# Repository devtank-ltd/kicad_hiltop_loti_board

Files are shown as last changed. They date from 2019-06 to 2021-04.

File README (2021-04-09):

Copyright Devtank Ltd 2021.

This documentation describes Open Hardware and is Licensed under CERN-OHL-W v2.

You may redistribute and modify this documentation under the terms of the CERN-OHL-W v2 (https://cern.ch/cern-ohl). This documentation is distributed WITHOUT ANY EXPRESS OR IMPLIED WARRANTY, INCLUDING OF MERCHANTABILITY, SATISFACTORY QUALITY AND FITNESS FOR A PARTICULAR PURPOSE. Please see the CERN-OHL-W v2 for applicable conditions

Source location: git@github.com:devtank-ltd/kicad_hiltop_loti_board.git 

As per CERN-OHL-W v2 section 4.1, should You produce hardware based on these sources, You must maintain the Source Location visible on the external case of the HILTOP or other product you make using this documentation.

This folder contains HILTOP LoTI Board hardware schematics and pcb layout files 

You will need Kicad to open hardware design files.

LoTI Boards and other test and measurement products can be purchased directly from Devtank Ltd.

Please contact:
Tim Telford
CTO - Devtank Ltd
+44 (0)1332 650944

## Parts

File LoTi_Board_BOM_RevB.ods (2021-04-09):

Title | LoTi Board
Revision | Rev B
Date | Mon 14 Sep 2020 16:12:00 BST
Generated
Company | Devtank Ltd
Comment 1
Comment 2
Comment 3
Comment 4
Total Parts | 442
Total Unique Parts | 79
Ref | Qty | Value | Footprint | Devtank | Description | Manufacturer | Manufacturer Part Number | Supplier | Supplier Part number
C9 C12 C1 C20 C21 C22 C23 C24 C25 C14 C15 C16 C26 C27 C28 C17 C18 C29 C38 C56 C82 C73 C74 C79 C80 C81 C54 | 27 | 100nF | Capacitor_SMD:C_0603_1608Metric | 105-002 | 100nF 50V X7R | Kemet | C0603C104M5RACTU | Farnell | 2581046
C8 C7 C13 | 3 | 100uF | Capacitor_SMD:CP_Elec_6.3x7.7 | 108-003 | 100uF 50V 0.34R FT Series | Panasonic | EEEFTH101XAP | Farnell | 1868426
C6 | 1 | 22nF | Resistor_SMD:R_0603_1608Metric | 105-024 | 22nF 16V X7R | AVX | 0603YC223KAT2A | Farnell | 2332669
C2 C3 C4 C5 | 4 | 15pF | Capacitor_SMD:C_0402_1005Metric | 106-013 | 15pF COG/NPO | AVX | 04025A150JAT2A | Farnell | 1327631
C10 C11 | 2 | 10uF | Capacitor_SMD:C_0805_2012Metric | 105-001 | 10uF 16V X5R 10% MLCC | AVX | 0805YD106KAT2A | Farnell | 1658880
C19 C53 | 2 | 100nF | Resistor_SMD:R_1210_3225Metric | 105-020 | 100nF 50V X7R | AVX | 12101C104KAT2A | Farnell | 1327731
C31 | 1 | 4.7uF | Capacitor_SMD:C_0603_1608Metric | 105-021 | 4.7uF 16V X5R | muRata | GRM188R61C475KAAJD | Farnell | 2611924
C32 C34 C39 C40 C41 C42 C43 C46 C44 C45 C47 C48 C50 C51 C30 C60 C61 C62 C66 C67 C68 C71 C72 | 23 | 100nF | Capacitor_SMD:C_0402_1005Metric | 105-019 | 100nF 50V X7R | TDK | C1005X7R1H104M050BB | Farnell | 2525048
C35 C49 | 2 | 1uF | Capacitor_SMD:C_0603_1608Metric | 105-014 | 1uF 16V X7R | Walsin | 0603B105K160CT | Farnell | 2496835
C33 C37 | 2 | 18pF | Capacitor_SMD:C_0402_1005Metric | 106-010 | 18pF COG/NPO | AVX | 04025A180JAT2A | Farnell | 1740572
C36 | 1 | 10nF | Capacitor_SMD:C_0402_1005Metric | 105-017 | 10nF 50V X7R | AVX | 04025C103KAT2A | Farnell | 2332514
C55 | 1 | 4.7uF | Capacitor_SMD:C_0805_2012Metric | 105-007 | 4.7uF 16V X7R | muRata | GCJ21BR71C475KA01L | Farnell | 2781412
C52 | 1 | DNF | Capacitor_SMD:C_0603_1608Metric
C57 C58 C59 C63 C64 C65 C69 C70 | 8 | DNP | Capacitor_SMD:C_0805_2012Metric
C77 C78 | 2 | 4.3pF | Capacitor_SMD:C_0603_1608Metric | 106-014 | 4.3pF COG/NPO | Kemet | CBR06C439B5GAC | Farnell | 2809587
C75 C76 | 2 | 18pF | Capacitor_SMD:C_0603_1608Metric | 106-003 | 18pF COG/NPO | AVX | 06035A180JAT2A | Farnell | 1612182
D1 D2 D3 D6 D7 D10 D13 | 7 | GRN | LED_SMD:LED_0603_1608Metric | 110-002 | Green LED | Rohm Semiconductor | SML-D12P8WT86C | Farnell | 2687486
D32 | 1 | MBR230LSFT1G | Diode_SMD:D_SOD-123 | 133-006 | Schottky Rectifier, 30 V, 2 A, Single, SOD-123FL | ON Semi | MBR230LSFT1G | Farnell | 2317422
D33 | 1 | BAT42W | Diode_SMD:D_SOD-123 |  | DNF
D4 D5 D8 D9 D11 | 5 | BAT54T1G | Diode_SMD:D_SOD-123 | 133-007 | BAT54T1G Small Signal Schottky Diode, Single, 30V, 200mA | ON Semi | BAT54T1G | Farnell | 1651157
D12 | 1 | RED | LED_SMD:LED_0402_1005Metric | 110-005 | LED RED CLEAR 0402 SMD | Rohm Semiconductor | SML-P12VTT86R | Digikey | 846-1168-6-ND
D18 D16 D14 D20 D22 D24 D19 D17 D15 D21 D23 D25 D28 D27 D26 D29 D30 D31 | 18 | BAV99 | Package_TO_SOT_SMD:SOT-23 | 134-001 | BAV99 - Small Signal Diode, Dual Series, 75 V, 300 mA, 1.25 V, 4 ns, 4.5 | Diodes Inc | BAV99 | Farnell | 1902422
F1 | 1 | Polyfuse | Resistor_SMD:R_1206_3216Metric | 190-003 | PPTC Resettable Fuse, SMD, POLYFUSE 1206L | Littlefuse | 1206L075THYR | Farnell | 1822204
J3 | 1 | Conn_03x32_DIN41612 | Devtank_PCB_Lib:Socket_DIN41612-CaseC1-full-Male-96Pin-3rows_correct | 717-002 | 406AF-96-MSR-AAE4 (Cards) | Valcon | 406AF-96-MSR-AAE4 | Toby | 406AF-96-MSR-AAE4
J4 | 1 | RJ45-TRANS_VALCON | Devtank_PCB_Lib:RJ45_TRANSFO_VALCON | 704-001 | RJ45 Ethernet with Magnetics + LEDs 10/100 | Valcon | VSIMJL-88-CC-GY | Toby | VSIMJL-88-CC-GY
J5 | 1 | USB_A | Devtank_PCB_Lib:USB_A_Vertical_Lumberg_2410_01 | 703-003 | USB Type A – PCB vertical | Lumberg | 2410 01 | Toby | 2410-01
J1 | 1 | Conn_02x10_Odd_Even | DNF |  | DNF |  |  | RS
J2 | 1 | DB44_MALE_MountingHoles | Connector_Dsub:DSUB-44-HD_Female_Horizontal_P2.29x1.98mm_EdgePinOffset8.35mm_Housed_MountingHolesOffset10.89mm | 707-003 | L17HTHBS4F1C - D Sub Connector, HD44, 44 Contacts, Receptacle, Through Hole, DB, HTH Series, Steel Body | Amphenol | L17HTHBS4F1C | Farnell | 2401273
J6 | 1 | Conn_02x08_Odd_Even | DNF |  | DNF |  | 281739-8 | RS | 532-080
JP1 | 1 | Jumper_NC_Dual | Connector_PinHeader_2.54mm:PinHeader_1x03_P2.54mm_Vertical | 710-015 | 3 Way Header (shroudless) | Valcon | THS-03-R | Toby | THS-03-R
K1 K2 K3 K4 K5 | 5 | HRS1KH-S | Devtank_PCB_Lib:Relay_SPDT_HRS1KH-S | 141-002 | Signal Relay 5VDC SPDT 24V 3A HRS1K Series | Multicomp | HRS1KH-S DC5V | Farnell | 9480293
L1 L2 L3 L4 L5 L6 L7 L8 L9 L10 L11 | 11 | 2A/0.05DCR | Inductor_SMD:L_0805_2012Metric | 113-002 | Ferrite 220 ohm, 2 A, WE-CBF Series, 0.05 ohm, ± 25% | Wurth Elektronik | 742792022 | Farnell | 1635733
Q2 Q3 Q4 Q5 Q6 Q7 Q8 Q9 Q10 Q11 Q12 Q13 Q14 | 13 | ZXMN6A07F | Package_TO_SOT_SMD:SOT-23 | 170-002 | ZXMN6A07F N Channel 1A, 60V, 0.4Ohm | Diodes Inc | ZXMN6A07FTA | Farnell | 9525769
R4 R5 R6 R23 R20 R24 R21 R22 R75 R81 R82 R124 | 12 | 330R | Resistor_SMD:R_0603_1608Metric | 101-024 | 330R 1% 0603 | Vishay | CRCW0603330RFKEA | Farnell | 1469803
R7 | 1 | 10R | Resistor_SMD:R_0402_1005Metric | 101-511 | 10R 1% 0402 | Vishay | CRCW040210R0FKED | Farnell | 1652742
R16 R15 | 2 | 4K7 | Resistor_SMD:R_0603_1608Metric | 101-009 | 4K7 1% 50V 0603 | Vishay | CRCW06034K70FKEA | Farnell | 121-9062
R17 R1 R2 R143 R147 R25 R26 R27 R29 R28 R64 R77 R9 R8 | 14 | DNF | Resistor_SMD:R_0603_1608Metric
R14 R18 R36 R38 R40 R42 R52 R53 R58 R59 R62 R63 R120 | 13 | 10K | Resistor_SMD:R_0603_1608Metric | 101-010 | 10K 1% 0603 | Vishay | CRCW060310K0FKEA | Farnell | 1469748
R10 R11 | 4 | 0R | Resistor_SMD:R_1206_3216Metric | 101-007 | 0R 1% 1206 | Vishay | CRCW12060000Z0EA | Farnell | 1469963
R3 R30 R31 R32 R33 R34 R35 R44 R45 R46 R47 | 11 | 100R | Resistor_SMD:R_0603_1608Metric | 101-018 | 100R 1% 50V 100mW CR Series | Bourns Inc | CR0603-FX-1000ELF | Farnell | 2008332
R13 | 1 | DNF | Resistor_SMD:R_0603_1608Metric |  | DNF | Vishay | CRCW06032K70FKEA | Farnell | 1469768
R145 | 1 | DNF | Resistor_SMD:R_0603_1608Metric |  | DNF
R149 R83 R84 R76 R122 R123 R118 R119 R121 R80 R79 | 11 | 0R | Resistor_SMD:R_0603_1608Metric | 101-005 | 0R 1% 0603 | Vishay | CRCW06030000Z0EA | Farnell | 1469739
R78 | 1 | 24K | Resistor_SMD:R_0603_1608Metric | 101-055 | 24K 1% 0603 | Multicomp Pro | MCWR06X2402FTL | Farnell | 2447308
R152 | 1 | 47K | Resistor_SMD:R_0603_1608Metric | 101-016 | 47K 1% 0603 | Bourns Inc | CR0603-FX-4702ELF | Farnell | 2333548
R150 R151 | 2 | 0R | Resistor_SMD:R_1210_3225Metric | 101-008 | 0R 1% 1210 | Vishay | CRCW12100000Z0EA | Farnell | 2309109
R19 R43 | 2 | 16K | Resistor_SMD:R_0603_1608Metric | 101-052 | 16K 1% 0603 | Vishay | CRCW060316K0FKEA | Farnell | 2138433
R37 R39 R41 | 3 | 3K3 | Resistor_SMD:R_0603_1608Metric | 101-013 | 3K3 1% 0603 | Vishay | CRCW06033K30FKEA | Farnell | 1469793
R50 R51 R56 R57 R61 | 5 | 470R | Resistor_SMD:R_0603_1608Metric | 101-001 | 470R 1% 50V | Vishay | CRCW0603470RFKEA | Farnell | 1469815
R48 R49 R54 R55 R60 | 5 | 2K2 | Resistor_SMD:R_0603_1608Metric | 101-011 | 2.2K 1% 0603 | Vishay | CRCW06032K20FKEA | Farnell | 1469765
R69 | 1 | 12K | Resistor_SMD:R_0402_1005Metric | 101-508 | 12K 1% 0402 | Vishay | CRCW040212K0FKED | Farnell | 2140866
R72 R73 R71 R74 | 4 | 49.9R | Resistor_SMD:R_0402_1005Metric | 101-514 | 49.9R 1% 0402 | Multicomp | CMR04X49R9FTL | Farnell | 2073090
R70 | 1 | 12.4K | Resistor_SMD:R_0402_1005Metric | 101-513 | 12.4K 1% 0402 | Panasonic | ERJ2RKF1242X | Farnell | 2059158
R68 R67 | 2 | 10K | Resistor_SMD:R_0402_1005Metric | 101-501 | 10K 1% 0402 | Vishay | CRCW040210K0FKED | Farnell | 1469669
R65 | 1 | 1M | Resistor_SMD:R_0402_1005Metric | 101-512 | 1M 1% 0402 | Vishay | CRCW04021M00JNED | Farnell | 2616728
R66 | 1 | 1K | Resistor_SMD:R_0402_1005Metric | 101-507 | 1K 1% 0402 | Vishay | CRCW04021K00FKED | Farnell | 1469662
R88 R89 R90 R100 R101 R102 R111 R112 R125 R126 R127 R128 R129 R130 R131 R132 R133 R134 R135 R136 R137 R138 R139 R140 R141 R142 | 26 | 1K | Resistor_SMD:R_0603_1608Metric | 101-012 | 1K 1% 0603 | Vishay | CRCW06031K00FKEA | Farnell | 1469740
R94 R95 R96 R106 R107 R108 R115 R116 | 8 | 100K | Resistor_SMD:R_0603_1608Metric | 101-015 | 100K 1% 0603 | Vishay | CRCW0402100KFKED | Farnell | 1469671
R85 R86 R87 R97 R98 R99 R109 R110 | 8 | 0R | Resistor_SMD:R_0805_2012Metric | 101-006 | 0R 1% 0805 | Vishay | CRCW08050000Z0EA | Farnell | 1469846
R91 R92 R93 R103 R104 R105 R113 R114 | 8 | DNP | Resistor_SMD:R_0805_2012Metric
SW1 | 1 | SW_Push | Button_Switch_SMD:SW_SPST_B3U-1000P | 780-001 | Switch SMT Micro SPST-NO | Omron | B3U-1000P | Mouser | 653-B3U-1000P
TP6 TP7 TP5 TP4 TP3 TP8 TP9 TP10 TP11 TP55 TP56 TP57 TP58 TP59 TP60 TP61 TP62 TP63 TP64 TP12 TP13 TP14 TP15 TP16 TP17 TP18 TP19 TP20 TP21 TP22 TP23 TP24 TP25 TP26 TP27 TP28 TP29 TP30 TP37 TP38 TP39 TP40 TP41 TP42 TP43 TP44 TP45 TP46 TP47 TP48 TP49 TP50 TP51 TP52 TP53 TP54 TP65 TP66 TP67 TP68 TP69 TP70 TP71 TP72 TP73 TP74 TP75 TP76 TP77 TP78 TP79 TP80 TP100 TP87 TP88 TP89 TP90 TP91 TP92 TP93 TP94 TP95 TP96 TP97 TP98 TP99 TP81 TP82 TP83 TP84 TP85 TP31 TP32 TP33 TP34 TP35 TP36 TP2 TP86 TP1 TP101 TP102 TP103 TP104 TP105 TP114 TP115 TP116 TP108 TP106 TP126 | 111 | Test_Point | TestPoint:TestPoint_THTPad_D1.0mm_Drill0.5mm
U1 | 1 | INA250A4 | Package_SO:TSSOP-16_4.4x5mm_P0.65mm | 119-002 | INA250 Current Shunt Monitor 2V/A (A4) | Texas Instruments | INA250A4PWR | Digikey
U3 | 1 | AT25DN512CSSHF-B | Package_SO:SOIC-8_3.9x4.9mm_P1.27mm | 129-002 | 512K, 2.3V, 104MHz Serial Flash | Adesto | AT25DN512C-SSHF-B (https://www.mouser.co.uk/ProductDetail/Adesto-Technologies/AT25DN512C-SSHF-B) | Mouser | 988-AT25DN512CSSHF-B
U2 | 1 | LD1117S33TR_SOT223 | Package_TO_SOT_SMD:SOT-223-3_TabPin2 | 150-004 | LM1117IMP-3.3 Fixed LDO Regulator 3.3V | Texas Instruments | LM1117IMP-3.3/NOPB | Farnell | 1469051
U4 U5 U6 U7 U8 | 5 | AD8646ARZ | Package_SO:SOIC-8_3.9x4.9mm_P1.27mm | 120-004 | Operational Amplifier, Rail-Rail, 1 Amplifier, 10 MHz, 20 V/µs, ± 2.25V to ± 18V, 4.5V to 36V, SOIC | Analog Devices | AD8646ARZ | Farnell | 1440771
U10 | 1 | LAN9513 | Package_DFN_QFN:QFN-64-1EP_9x9mm_P0.5mm_EP7.3x7.3mm_ThermalVias | 123-011 | LAN9513 - Ethernet Bridge, USB to Ethernet USB 2.0, 10/100 Base-T/TX PHY USB Interface 64-QFN (9x9) | Microchip | LAN9513-JZX | Digikey | LAN9513-JZX-ND
U11 | 1 | MIC2026-1YM | Package_SO:SOIC-8_3.9x4.9mm_P1.27mm | 153-003 | MIC2026-1YM USB Power distribution Switch Current Limit, high side switch – 2 outputs | Microchip | MIC2026-1YM | Farnell | 2509898
U9 | 1 | 93LCxxA | Package_SO:SOIC-8_3.9x4.9mm_P1.27mm | 129-004 | EEPROM, kbit, 64 x 16bit 3MHz | Microchip | 93LC46B-I/SN | Farnell | 9758232
U12 | 1 | SP3003-02XJ | Devtank_PCB_Lib:SC70-5 | 153-004 | SP3003-02JTG-ESD Protection Device | Littlefuse | SP3003-02JTG | Farnell | 1827640
U13 | 1 | CP2102N-A01-GQFN24 | Package_DFN_QFN:QFN-24-1EP_4x4mm_P0.5mm_EP2.6x2.6mm_ThermalVias | 118-007 | CP2102N USB to UART adapter IC | Silicon Labs | CP2102N-A01-GQFN24 | Farnell | 2577278
U14 U15 U16 U17 U18 U19 U20 U21 | 8 | BTS4140N | Package_TO_SOT_SMD:SOT-223 | 146-001 | BTS4140NHUMA1 Smart Power Switch, SIPMOS Technology, High Side, 1 Output, 0.7A, |  | BTS4140NHUMA1 | Farnell | 2215503
U22 | 1 | STM32F072RBTx | Package_QFP:LQFP-64_10x10mm_P0.5mm | 126-001 | STM32F072RBT6, 32bit ARM Cortex M0 Microcontroller, 48MHz, 64 kB, 128 kB Flash | ST Microelectronics | STM32F072RBT6 | RS | 907-4757
U23 | 1 | M74VHC1GT14DFT2G | Package_TO_SOT_SMD:SOT-353_SC-70-5 | 123-016 | M74VHC1GT14DFT2G Schmitt trigger inverter | On Semi | M74VHC1GT14DFT2G | Farnell | 2464477
Y1 | 1 | 25MHz Crystal | Crystal:Crystal_SMD_SeikoEpson_FA238V-4Pin_3.2x2.5mm | 181-001 | 25MHz Crystal 30ppm | Abracon | ABM8G-25.000MHZ-18-D2Y-T | Farnell | 2101339
Y3 | 1 | ABS25-32.768KHZ-6-T | Crystal:Crystal_SMD_7050-4Pin_7.0x5.0mm | 181-008 | Crystal, 32.768 kHz, SMD, 8mm x 3.8mm | Abracon | ABS25-32.768KHZ-6-T | Farnell | 2101354
Y2 | 1 | 8MHZ | Crystal:Crystal_SMD_Abracon_ABM3C-4Pin_5.0x3.2mm | 181-009 | ABM3B-8.000MHZ-B2-T - Crystal, 8 MHz, SMD, 5mm x 3.2mm, 50 ppm, 18 pF, 20 ppm | Abracon | ABM3B-8.000MHZ-B2-T | Farnell | 2467818
BOM made with KICAD_BOM_WIZARD (https://github.com/HashDefineElectronics/KiCad_BOM_Wizard.git)
Generated Tue 23 Apr 2019 13:30:32 BST

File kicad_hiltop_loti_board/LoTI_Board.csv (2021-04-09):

Title | LoTI Board
Revision | Rev A
Date | 2019-07-03
Generated | Mon 14 Sep 2020 16:12:00 BST
Company | Devtank Ltd
Comment 1
Comment 2
Comment 3
Comment 4
Total Parts | 442
Total Unique Parts | 79
Ref | Qty | Value | Footprint | Devtank
C9 C12 C1 C20 C21 C22 C23 C24 C25 C14 C15 C16 C26 C27 C28 C17 C18 C29 C56 C54 C82 C73 C74 C79 C80 C81 C38 | 27 | 100nF | Capacitor_SMD:C_0603_1608Metric | 105-002
C8 C7 C13 | 3 | 100uF | Capacitor_SMD:CP_Elec_6.3x7.7 | 108-003
C6 | 1 | 22nF | Resistor_SMD:R_0603_1608Metric | 105-024
C2 C3 C4 C5 | 4 | 15pF | Capacitor_SMD:C_0402_1005Metric | 106-013
C10 C11 | 2 | 10uF | Capacitor_SMD:C_0805_2012Metric | 105-001
C19 C53 | 2 | 100nF | Resistor_SMD:R_1210_3225Metric | 105-020
C55 | 1 | 4.7uF | Capacitor_SMD:C_0805_2012Metric | 105-007
C52 | 1 | DNF | Capacitor_SMD:C_0603_1608Metric
C60 C61 C62 C66 C67 C68 C71 C72 C32 C34 C39 C40 C41 C42 C43 C46 C44 C45 C47 C48 C50 C51 C30 | 23 | 100nF | Capacitor_SMD:C_0402_1005Metric | 105-019
C57 C58 C59 C63 C64 C65 C69 C70 | 8 | DNP | Capacitor_SMD:C_0805_2012Metric
C77 C78 | 2 | 4.3pF | Capacitor_SMD:C_0603_1608Metric | 106-014
C75 C76 | 2 | 18pF | Capacitor_SMD:C_0603_1608Metric | 106-003
C31 | 1 | 4.7uF | Capacitor_SMD:C_0603_1608Metric | 105-021
C35 C49 | 2 | 1uF | Capacitor_SMD:C_0603_1608Metric | 105-014
C33 C37 | 2 | 18pF | Capacitor_SMD:C_0402_1005Metric | 106-010
C36 | 1 | 10nF | Capacitor_SMD:C_0402_1005Metric | 105-017
D1 D2 D3 D6 D7 D10 D13 | 7 | GRN | LED_SMD:LED_0603_1608Metric | 110-002
D32 | 1 | MBR230LSFT1G | Diode_SMD:D_SOD-123 | 133-006
D33 | 1 | DNF | Diode_SMD:D_SOD-123 | 133-005
D4 D5 D8 D9 D11 | 5 | BAT54T1G | Diode_SMD:D_SOD-123 | 133-007
D18 D16 D14 D20 D22 D24 D19 D17 D15 D21 D23 D25 D28 D27 D26 D29 D30 D31 | 18 | BAV99 | Package_TO_SOT_SMD:SOT-23 | 134-001
D12 | 1 | RED | LED_SMD:LED_0402_1005Metric | 110-004
F1 | 1 | Polyfuse | Resistor_SMD:R_1206_3216Metric | 190-003
J3 | 1 | Conn_03x32_DIN41612 | Devtank_PCB_Lib:Socket_DIN41612-CaseC1-full-Male-96Pin-3rows_correct | 717-002
J4 | 1 | RJ45-TRANS_VALCON | Devtank_PCB_Lib:RJ45_TRANSFO_VALCON | 704-001
J5 | 1 | USB_A | Devtank_PCB_Lib:USB_A_Vertical_Lumberg_2410_01 | 703-003
J1 | 1 | Conn_02x10_Odd_Even | Connector_IDC:IDC-Header_2x10_P2.54mm_Vertical | 710-018
J2 | 1 | DB44_MALE_MountingHoles | Connector_Dsub:DSUB-44-HD_Female_Horizontal_P2.29x1.98mm_EdgePinOffset8.35mm_Housed_MountingHolesOffset10.89mm | 707-003
J6 | 1 | Conn_02x08_Odd_Even | Connector_IDC:IDC-Header_2x08_P2.54mm_Vertical | 710-017
JP1 | 1 | Jumper_NC_Dual | Connector_PinHeader_2.54mm:PinHeader_1x03_P2.54mm_Vertical | 710-015
K1 K2 K3 K4 K5 | 5 | HRS1KH-S | Devtank_PCB_Lib:Relay_SPDT_HRS1KH-S | 141-002
L3 L4 L5 L6 L7 L8 L9 L10 L11 L1 L2 | 11 | 2A/0.05DCR | Inductor_SMD:L_0805_2012Metric | 113-002
Q2 Q3 Q4 Q5 Q6 Q7 Q8 Q9 Q10 Q11 Q12 Q13 Q14 | 13 | ZXMN6A07F | Package_TO_SOT_SMD:SOT-23 | 170-002
R4 R5 R6 R23 R20 R24 R21 R22 R81 R82 R124 R75 | 12 | 330R | Resistor_SMD:R_0603_1608Metric | 101-024
R7 | 1 | 10R | Resistor_SMD:R_0402_1005Metric | 101-511
R16 R15 | 2 | 4K7 | Resistor_SMD:R_0603_1608Metric | 101-009
R17 R1 R2 R143 R147 R12 R148 R25 R26 R27 R29 R28 R77 R117 R64 | 15 | DNF | Resistor_SMD:R_0603_1608Metric
R14 R18 R36 R38 R40 R42 R52 R53 R58 R59 R62 R120 R63 | 13 | 10K | Resistor_SMD:R_0603_1608Metric | 101-010
R9 R8 | 2 | DNF | Resistor_SMD:R_1206_3216Metric | 101-007
R10 R11 | 2 | 0R | Resistor_SMD:R_1206_3216Metric | 101-007
R3 R30 R31 R32 R33 R34 R35 R44 R45 R46 R47 | 11 | 100R | Resistor_SMD:R_0603_1608Metric | 101-018
R13 | 1 | DNF | Resistor_SMD:R_0603_1608Metric | 101-051
R145 | 1 | DNF | Resistor_SMD:R_0603_1608Metric | 101-053
R144 R146 | 2 | DNF | Resistor_SMD:R_0603_1608Metric | 101-005
R149 R83 R84 R76 R80 R79 R122 R123 R118 R119 R121 | 11 | 0R | Resistor_SMD:R_0603_1608Metric | 101-005
R150 R151 | 2 | 0R | Resistor_SMD:R_1210_3225Metric | 101-008
R19 R43 | 2 | 16K | Resistor_SMD:R_0603_1608Metric | 101-052
R37 R39 R41 | 3 | 3K3 | Resistor_SMD:R_0603_1608Metric | 101-013
R50 R51 R56 R57 R61 | 5 | 470R | Resistor_SMD:R_0603_1608Metric | 101-001
R48 R49 R54 R55 R60 | 5 | 2K2 | Resistor_SMD:R_0603_1608Metric | 101-011
R78 | 1 | 24K | Resistor_SMD:R_0603_1608Metric | 101-005
R152 | 1 | 47K | Resistor_SMD:R_0603_1608Metric
R88 R89 R90 R100 R101 R102 R111 R112 R125 R126 R127 R128 R129 R130 R131 R132 R133 R134 R135 R136 R137 R138 R139 R140 R141 R142 | 26 | 1K | Resistor_SMD:R_0603_1608Metric | 101-012
R94 R95 R96 R106 R107 R108 R115 R116 | 8 | 100K | Resistor_SMD:R_0603_1608Metric | 101-015
R85 R86 R87 R97 R98 R99 R109 R110 | 8 | 0R | Resistor_SMD:R_0805_2012Metric | 101-006
R91 R92 R93 R103 R104 R105 R113 R114 | 8 | DNP | Resistor_SMD:R_0805_2012Metric
R69 | 1 | 12K | Resistor_SMD:R_0402_1005Metric | 101-508
R72 R73 R71 R74 | 4 | 49.9R | Resistor_SMD:R_0402_1005Metric | 101-514
R70 | 1 | 12.4K | Resistor_SMD:R_0402_1005Metric | 101-513
R68 R67 | 2 | 10K | Resistor_SMD:R_0402_1005Metric | 101-501
R65 | 1 | 1M | Resistor_SMD:R_0402_1005Metric | 101-512
R66 | 1 | 1K | Resistor_SMD:R_0402_1005Metric | 101-507
SW1 | 1 | SW_Push | Button_Switch_SMD:SW_SPST_B3U-1000P | 780-001
TP6 TP7 TP5 TP4 TP3 TP8 TP9 TP10 TP11 TP55 TP56 TP57 TP58 TP59 TP60 TP61 TP62 TP63 TP64 TP12 TP13 TP14 TP15 TP16 TP17 TP18 TP19 TP20 TP21 TP22 TP23 TP24 TP25 TP26 TP27 TP28 TP29 TP30 TP37 TP38 TP39 TP40 TP41 TP42 TP43 TP44 TP45 TP46 TP47 TP48 TP49 TP50 TP51 TP52 TP53 TP54 TP65 TP66 TP67 TP68 TP69 TP70 TP71 TP72 TP73 TP74 TP75 TP76 TP77 TP78 TP79 TP80 TP100 TP87 TP88 TP89 TP90 TP91 TP92 TP93 TP94 TP95 TP96 TP97 TP98 TP99 TP81 TP82 TP83 TP84 TP85 TP31 TP32 TP33 TP34 TP35 TP36 TP2 TP86 TP1 TP101 TP102 TP103 TP104 TP105 TP126 TP114 TP115 TP116 TP108 TP106 | 111 | Test_Point | TestPoint:TestPoint_THTPad_D1.0mm_Drill0.5mm
U1 | 1 | INA250A4 | Package_SO:TSSOP-16_4.4x5mm_P0.65mm | 119-002
U3 | 1 | AT25DN512CSSHF-B | Package_SO:SOIC-8_3.9x4.9mm_P1.27mm | 129-002
U2 | 1 | LD1117S33TR_SOT223 | Package_TO_SOT_SMD:SOT-223-3_TabPin2 | 150-004
U4 U5 U6 U7 U8 | 5 | AD8646 | Package_SO:SOIC-8_3.9x4.9mm_P1.27mm | 120-004
U13 | 1 | CP2102N-A01-GQFN24 | Package_DFN_QFN:QFN-24-1EP_4x4mm_P0.5mm_EP2.6x2.6mm_ThermalVias | 118-007
U23 | 1 | M74VHC1GT14DFT2G | Package_TO_SOT_SMD:SOT-353_SC-70-5
U14 U15 U16 U17 U18 U19 U20 U21 | 8 | BTS4140N | Package_TO_SOT_SMD:SOT-223 | 146-001
U22 | 1 | STM32F072RBTx | Package_QFP:LQFP-64_10x10mm_P0.5mm | 126-001
U10 | 1 | LAN9513 | Package_DFN_QFN:QFN-64-1EP_9x9mm_P0.5mm_EP7.3x7.3mm_ThermalVias | 123-011
U11 | 1 | MIC2026-1YM | Package_SO:SOIC-8_3.9x4.9mm_P1.27mm | 153-003
U9 | 1 | 93LCxxA | Package_SO:SOIC-8_3.9x4.9mm_P1.27mm | 129-004
U12 | 1 | SP3003-02XJ | Devtank_PCB_Lib:SC70-5 | 153-004
Y3 | 1 | ABS25-32.768KHZ-6-T | Crystal:Crystal_SMD_7050-4Pin_7.0x5.0mm | 181-008
Y2 | 1 | 8MHZ | Crystal:Crystal_SMD_Abracon_ABM3C-4Pin_5.0x3.2mm | 181-009
Y1 | 1 | 25MHz Crystal | Crystal:Crystal_SMD_SeikoEpson_FA238V-4Pin_3.2x2.5mm | 181-001
BOM made with KICAD_BOM_WIZARD (https://github.com/HashDefineElectronics/KiCad_BOM_Wizard.git)
Generated Mon 14 Sep 2020 16:12:00 BST

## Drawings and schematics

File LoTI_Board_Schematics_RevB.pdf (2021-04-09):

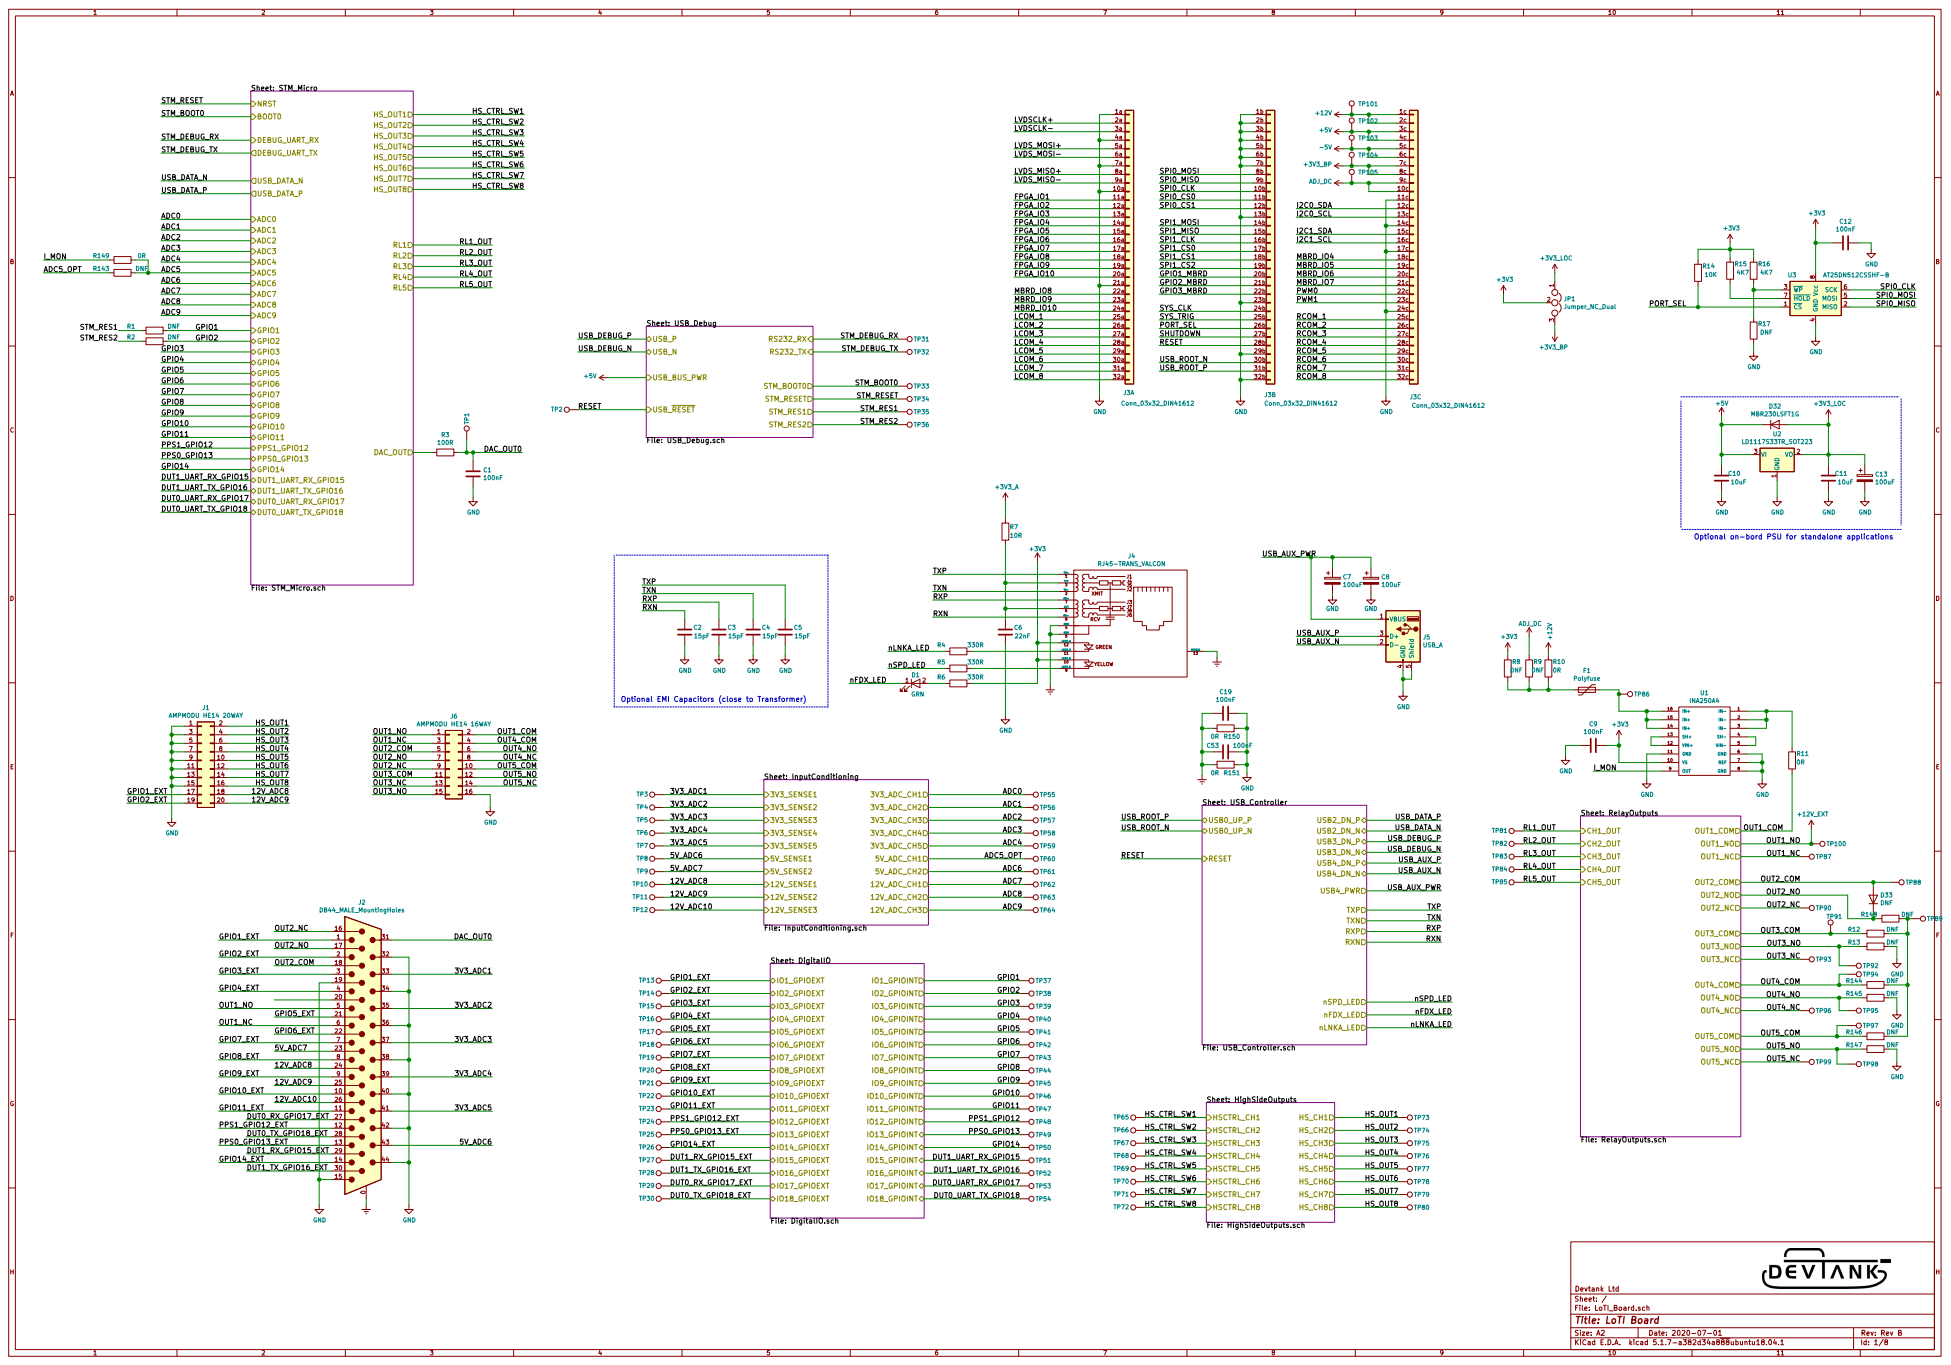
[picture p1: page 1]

Optional on-bord PSU for standalone applications

Optional EMI Capacitors (close to Transformer)

File: LoTI_Board.sch Sheet: / Devtank Ltd

Id: 1/8 Title: LoTI Board

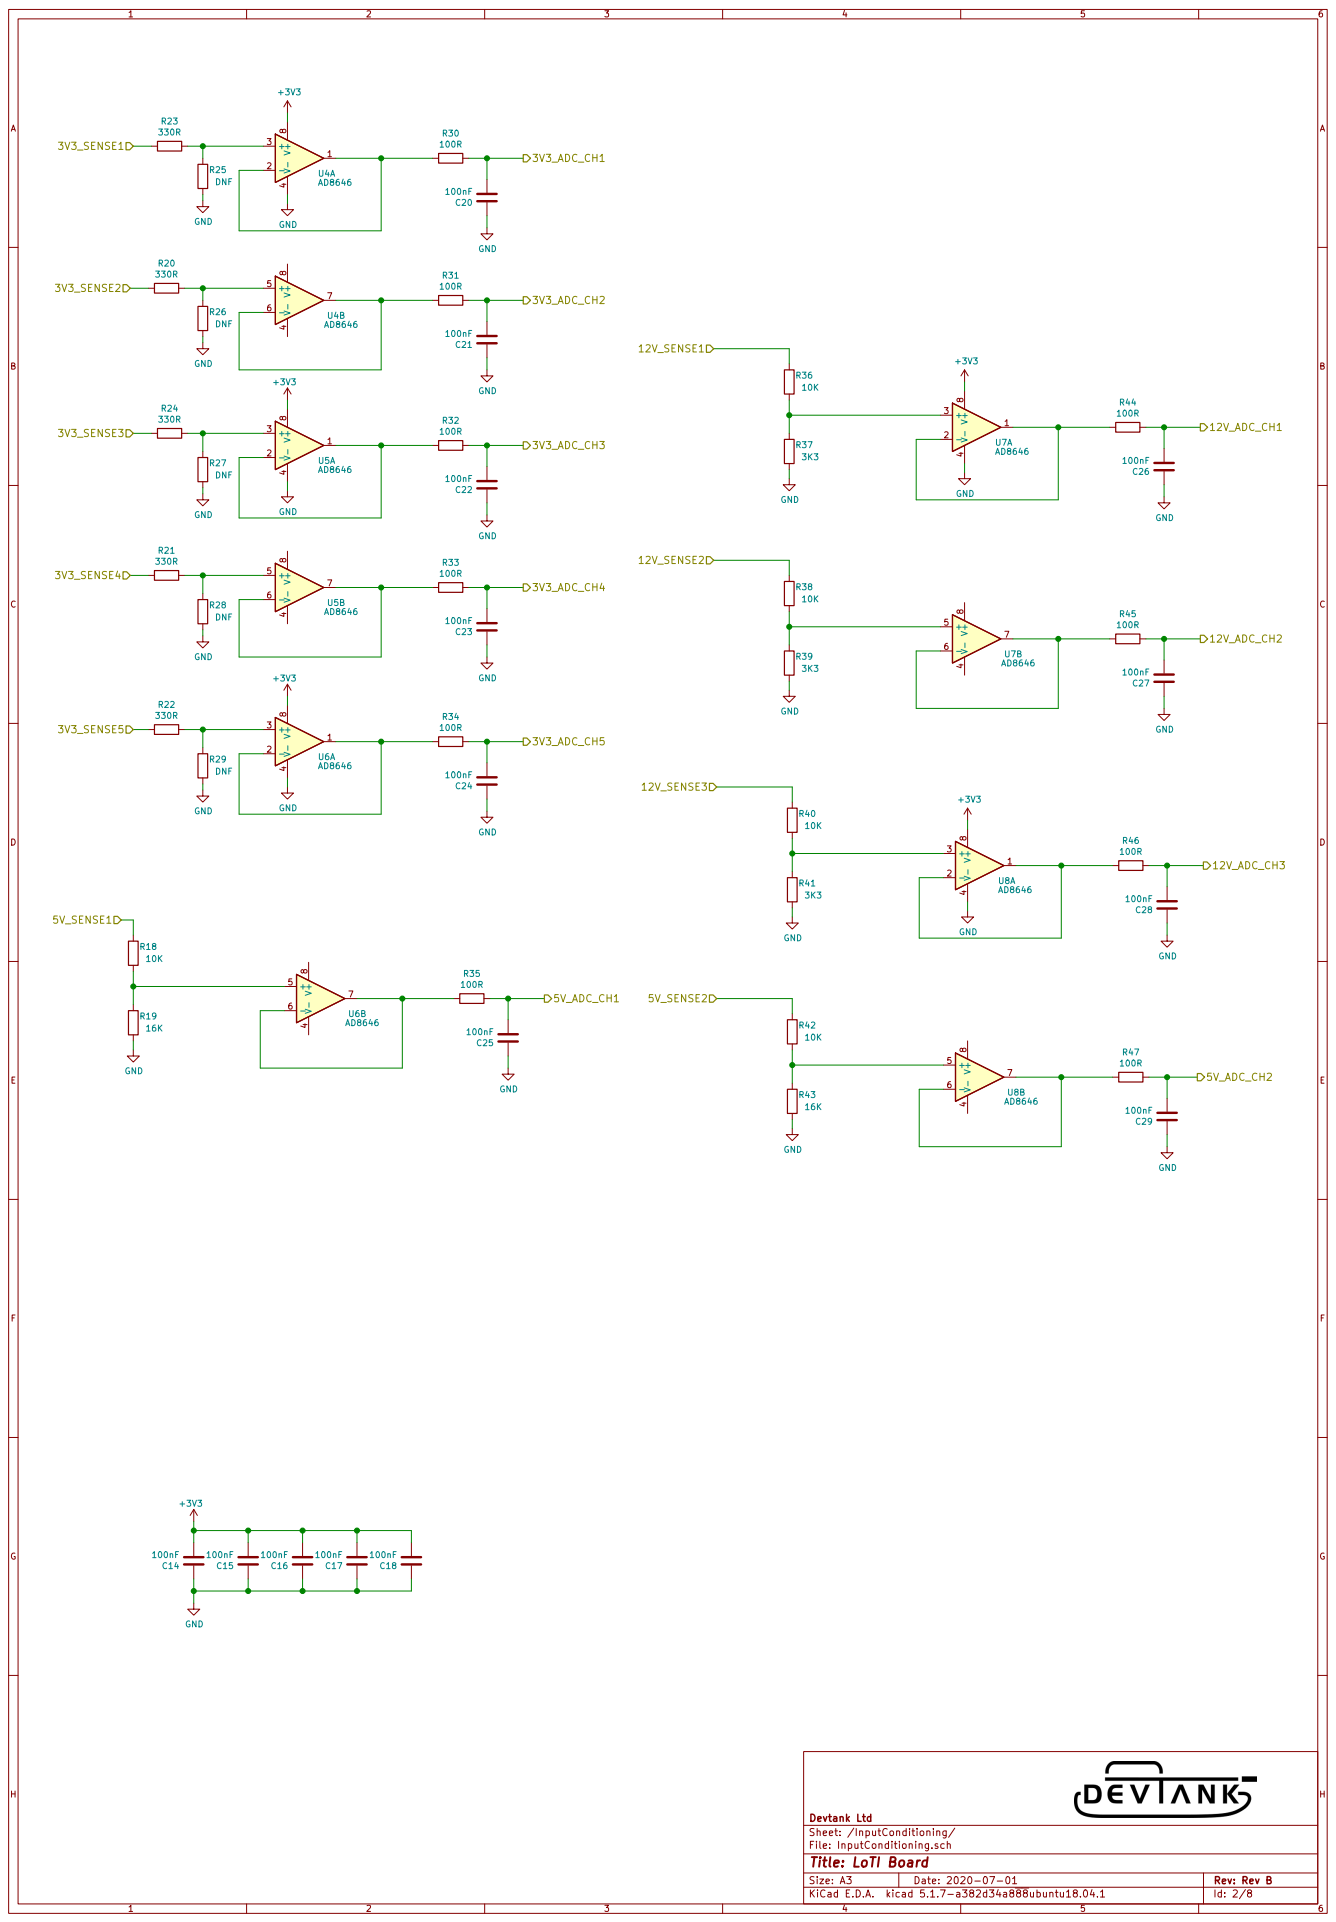
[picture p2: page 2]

Sheet: /InputConditioning/ Devtank Ltd

File: InputConditioning.sch
Id: 2/8 Title: LoTI Board

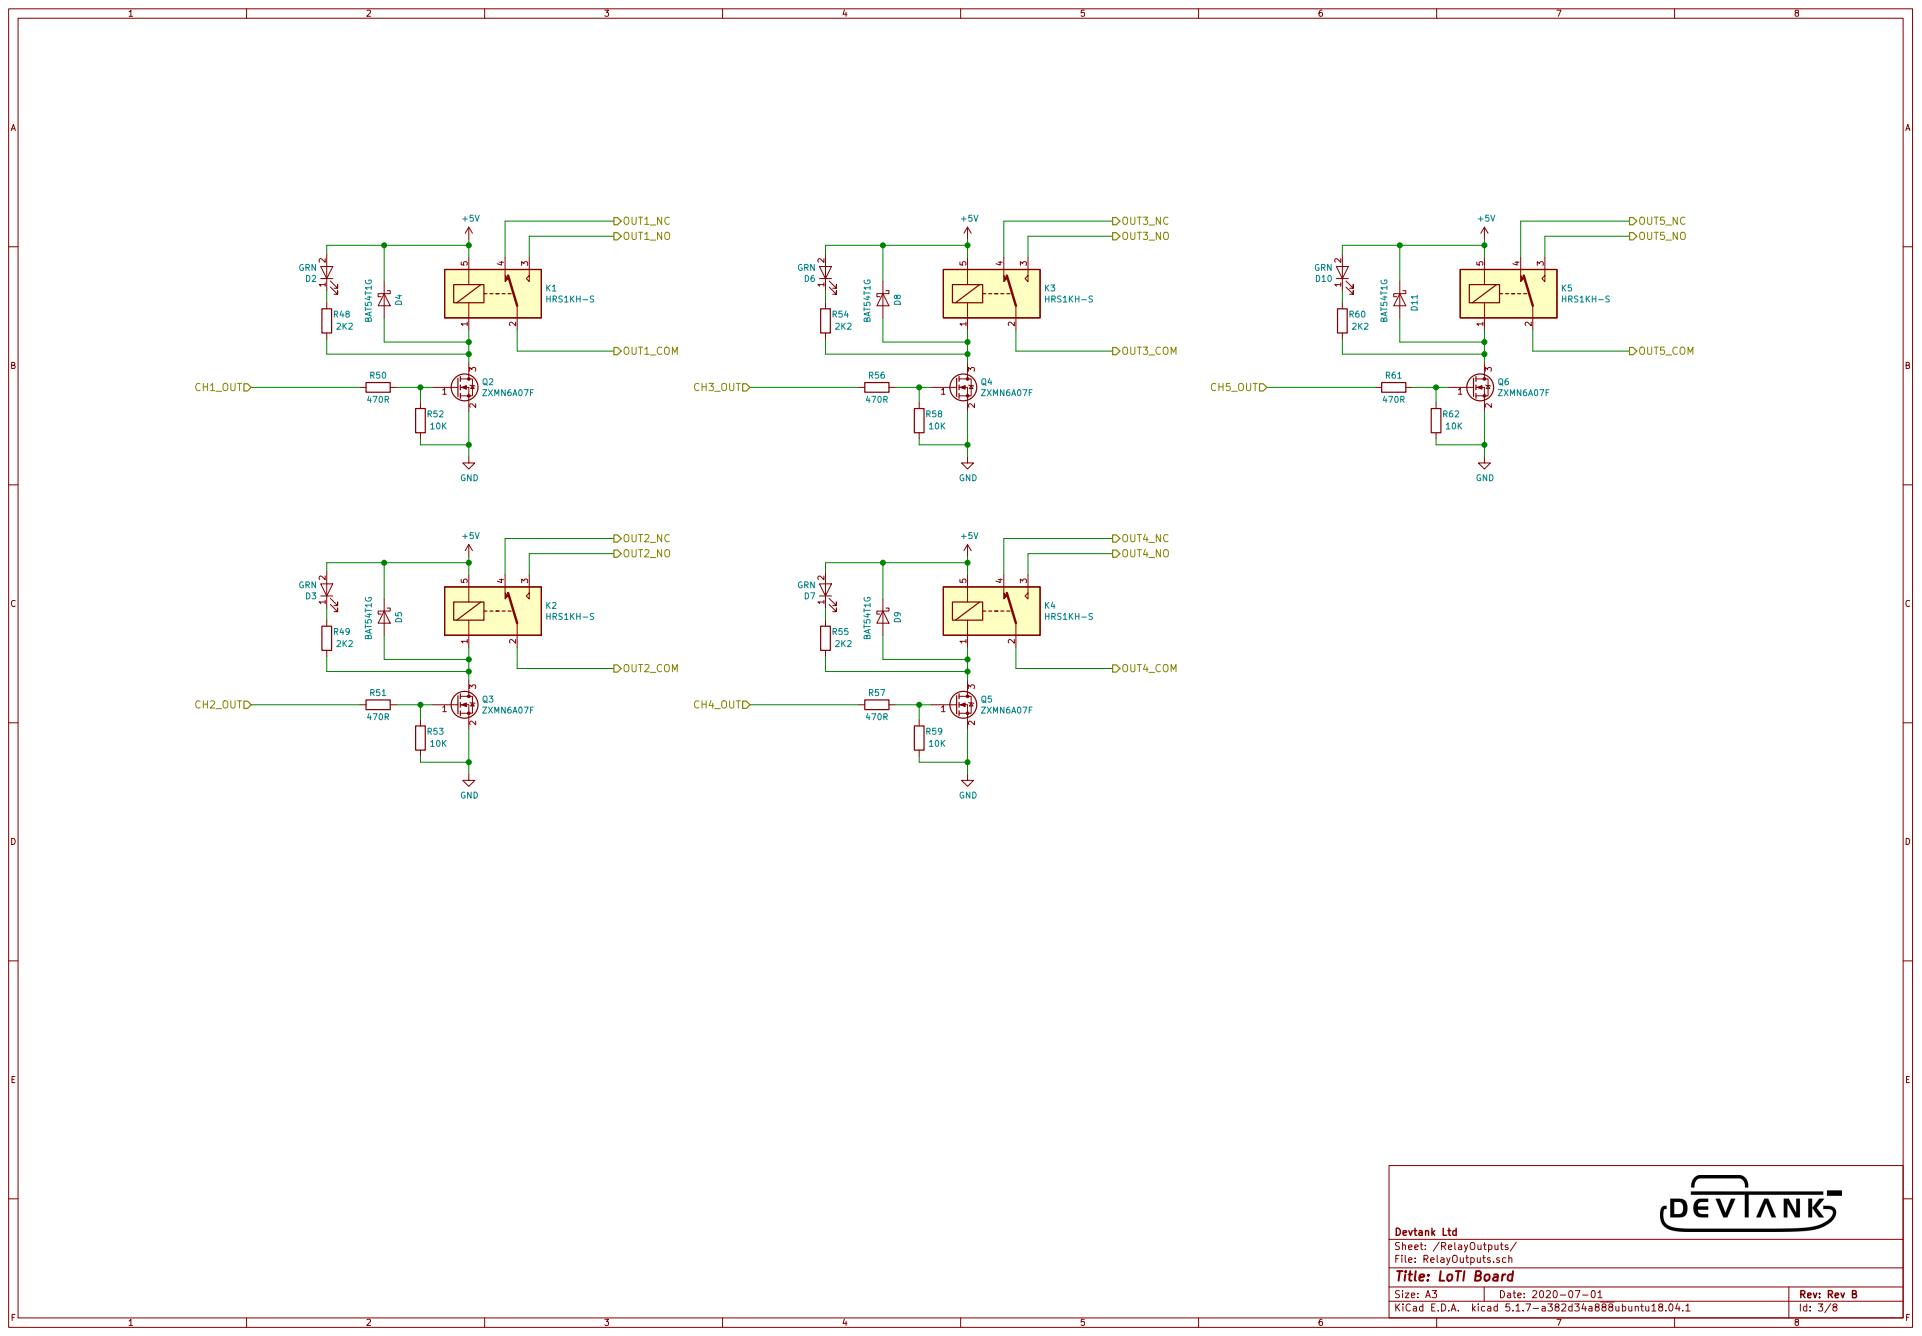
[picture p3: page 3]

Sheet: /RelayOutputs/ Devtank Ltd

File: RelayOutputs.sch
Id: 3/8 Title: LoTI Board

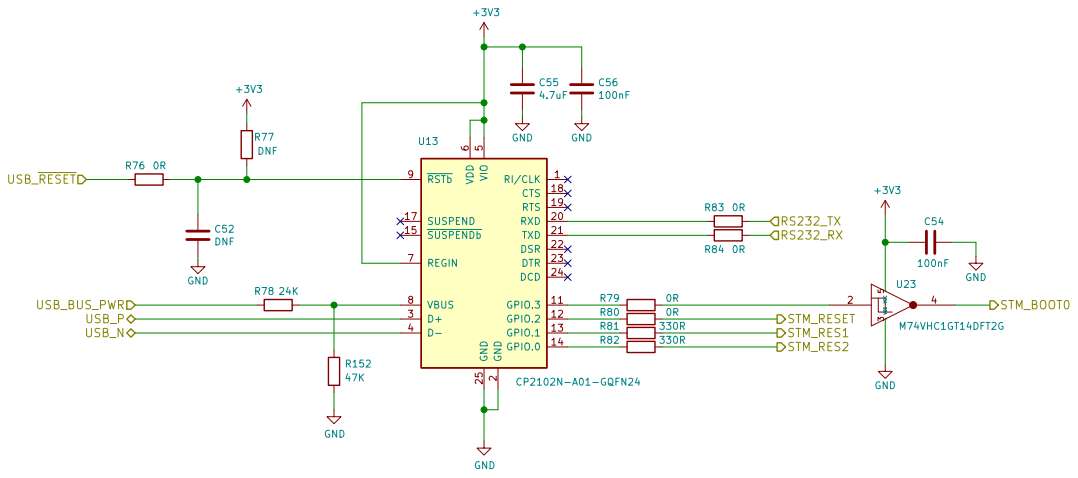
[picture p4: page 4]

6 REGIN 7 VBUS 8 RSTb 9 U13 CP2102N-A01-GQFN24 GND

2 RXD 20 TXD 21 DSR 22 DTR 23 DCD 24 GND 25 D+ 3 D- 4 VIO

File: USB_Debug.sch
Id: 4/8 Title: LoTI Board

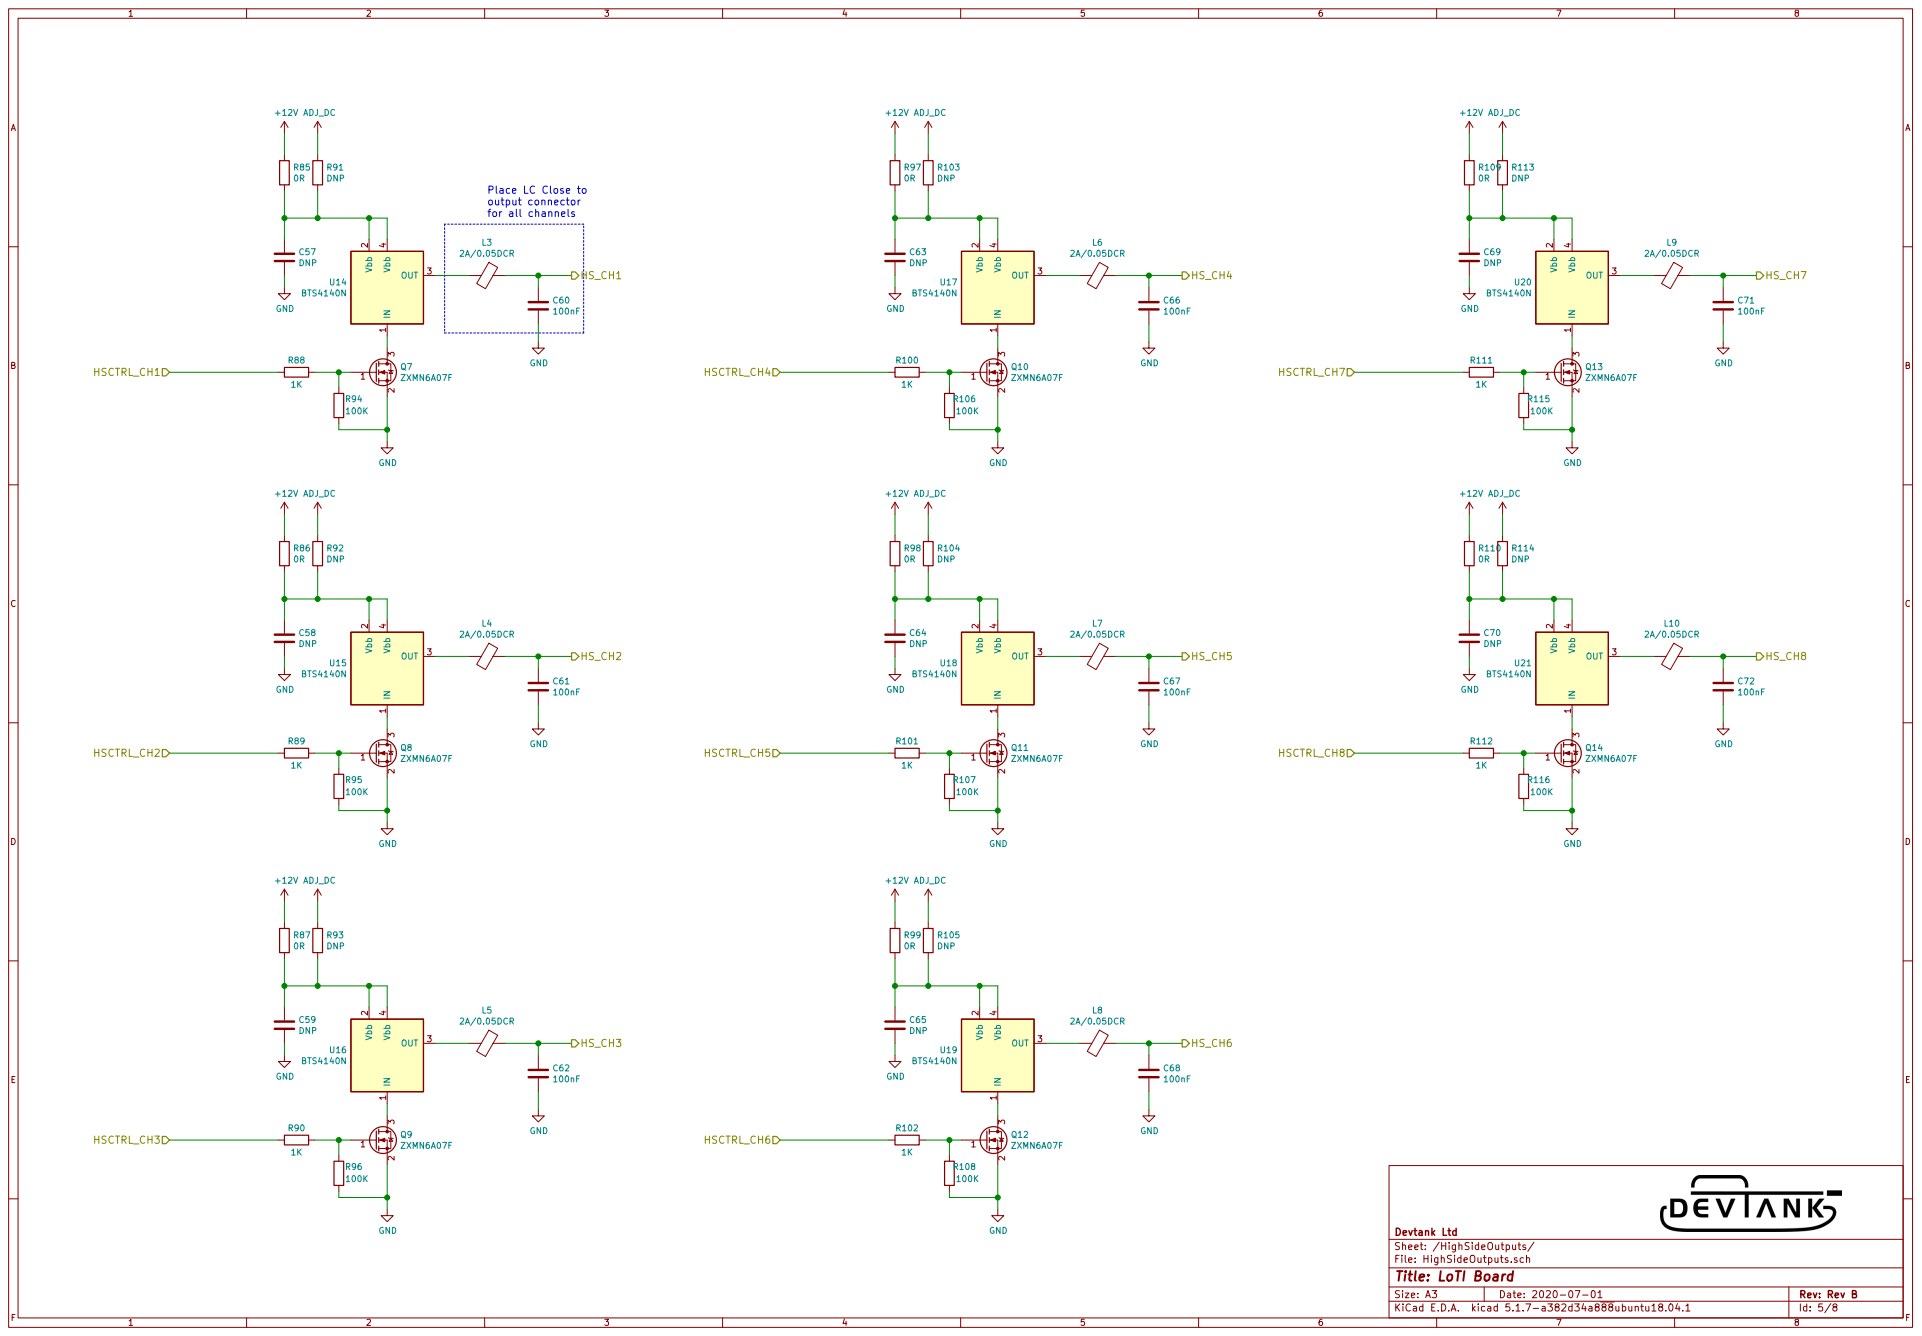
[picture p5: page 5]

Place LC Close to
output connector
for all channels

File: HighSideOutputs.sch
Id: 5/8 Title: LoTI Board

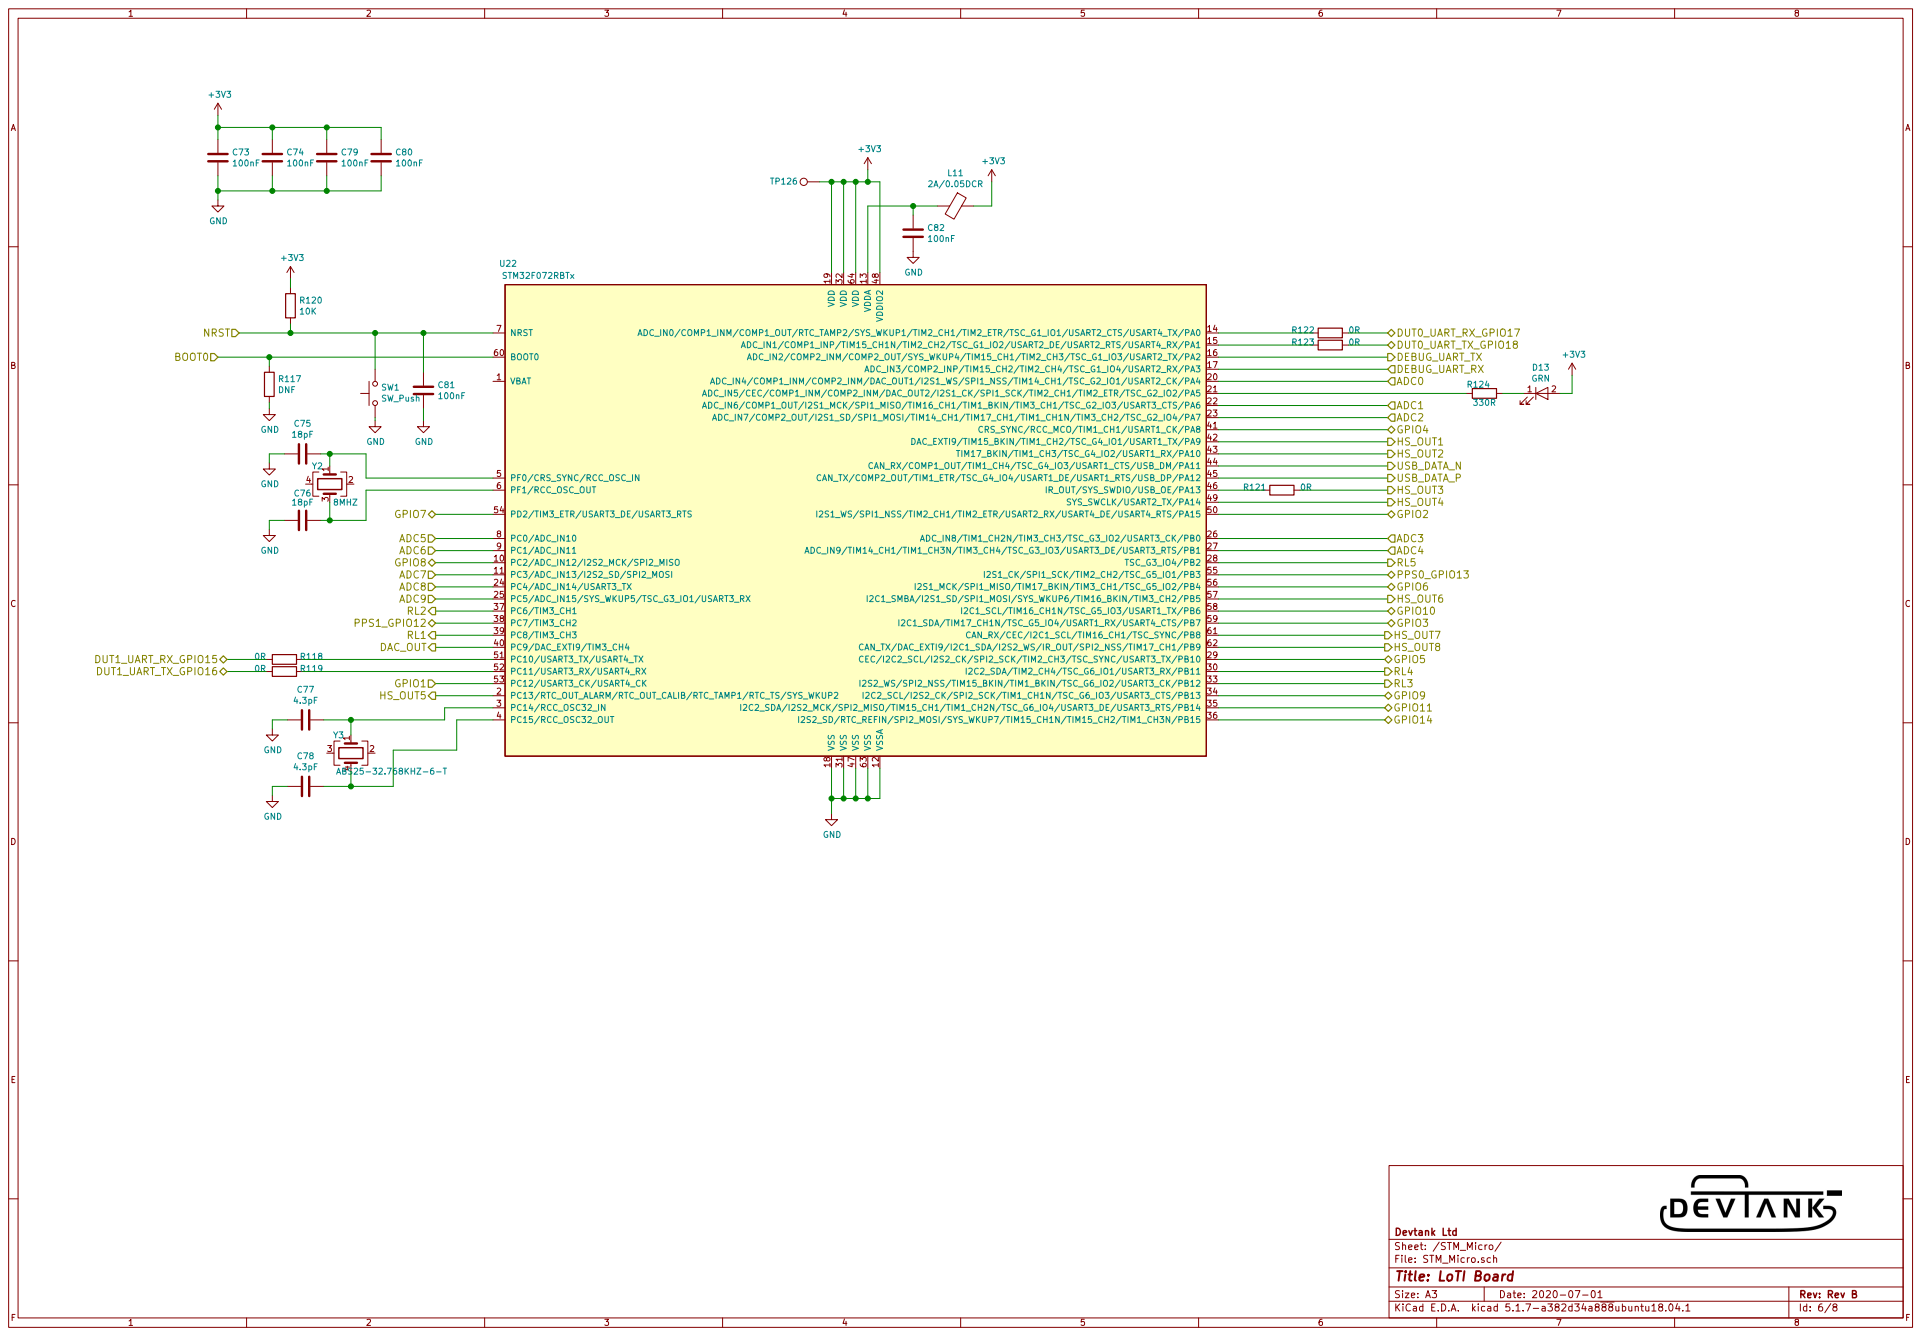
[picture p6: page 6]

File: STM_Micro.sch
Id: 6/8 Title: LoTI Board

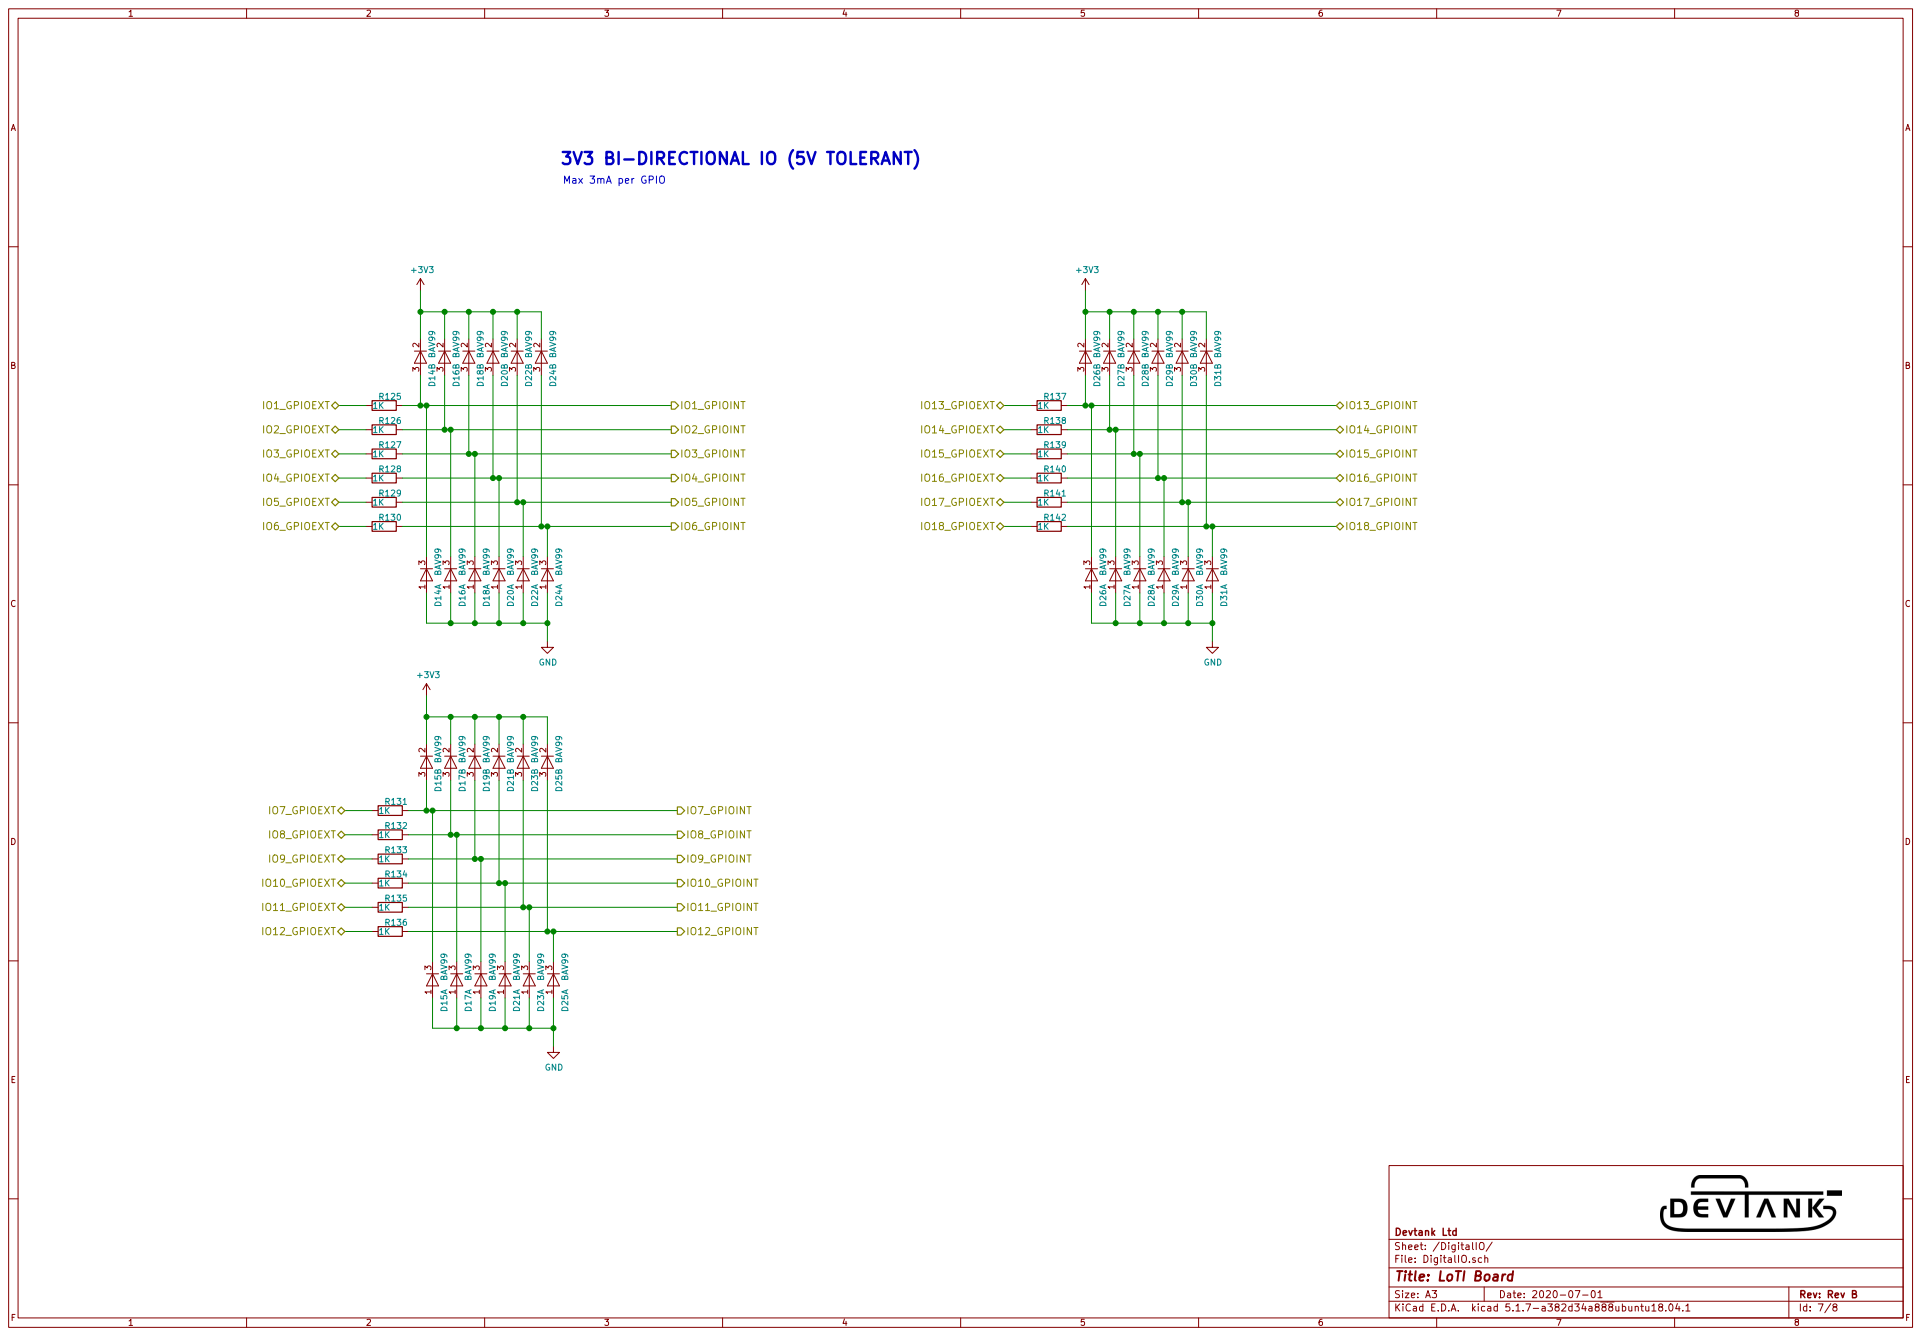
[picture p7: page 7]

3V3 BI-DIRECTIONAL IO (5V TOLERANT)

Sheet: /DigitalIO/ Devtank Ltd

File: DigitalIO.sch
Id: 7/8 Title: LoTI Board

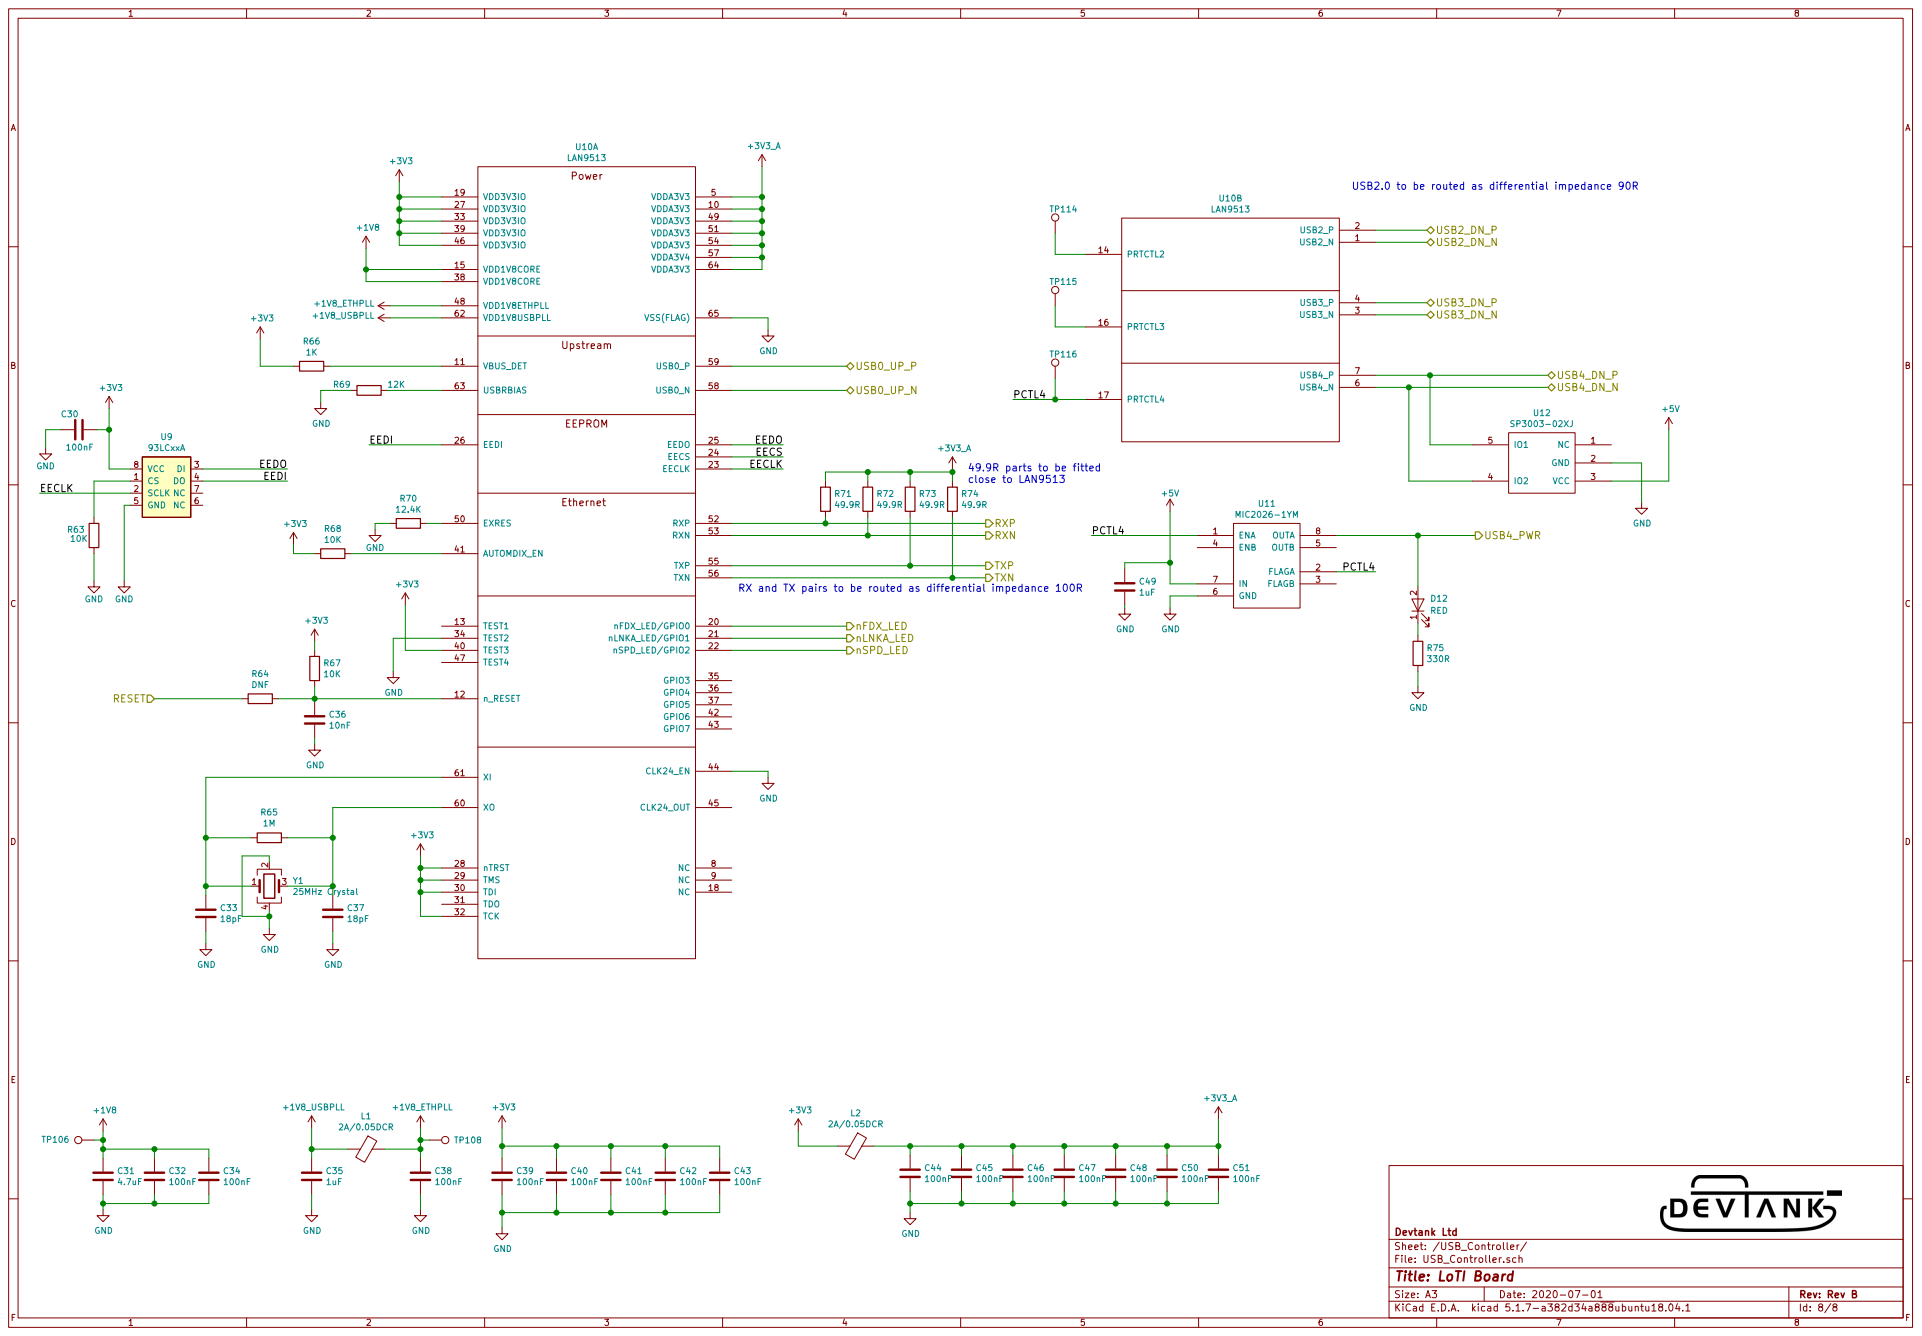
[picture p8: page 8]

USB2.0 to be routed as differential impedance 90R

EEDO
EECS
EECLK
49.9R parts to be fitted close to LAN9513 RX and TX pairs to be routed as differential impedance 100R

File: USB_Controller.sch
Id: 8/8 Title: LoTI Board

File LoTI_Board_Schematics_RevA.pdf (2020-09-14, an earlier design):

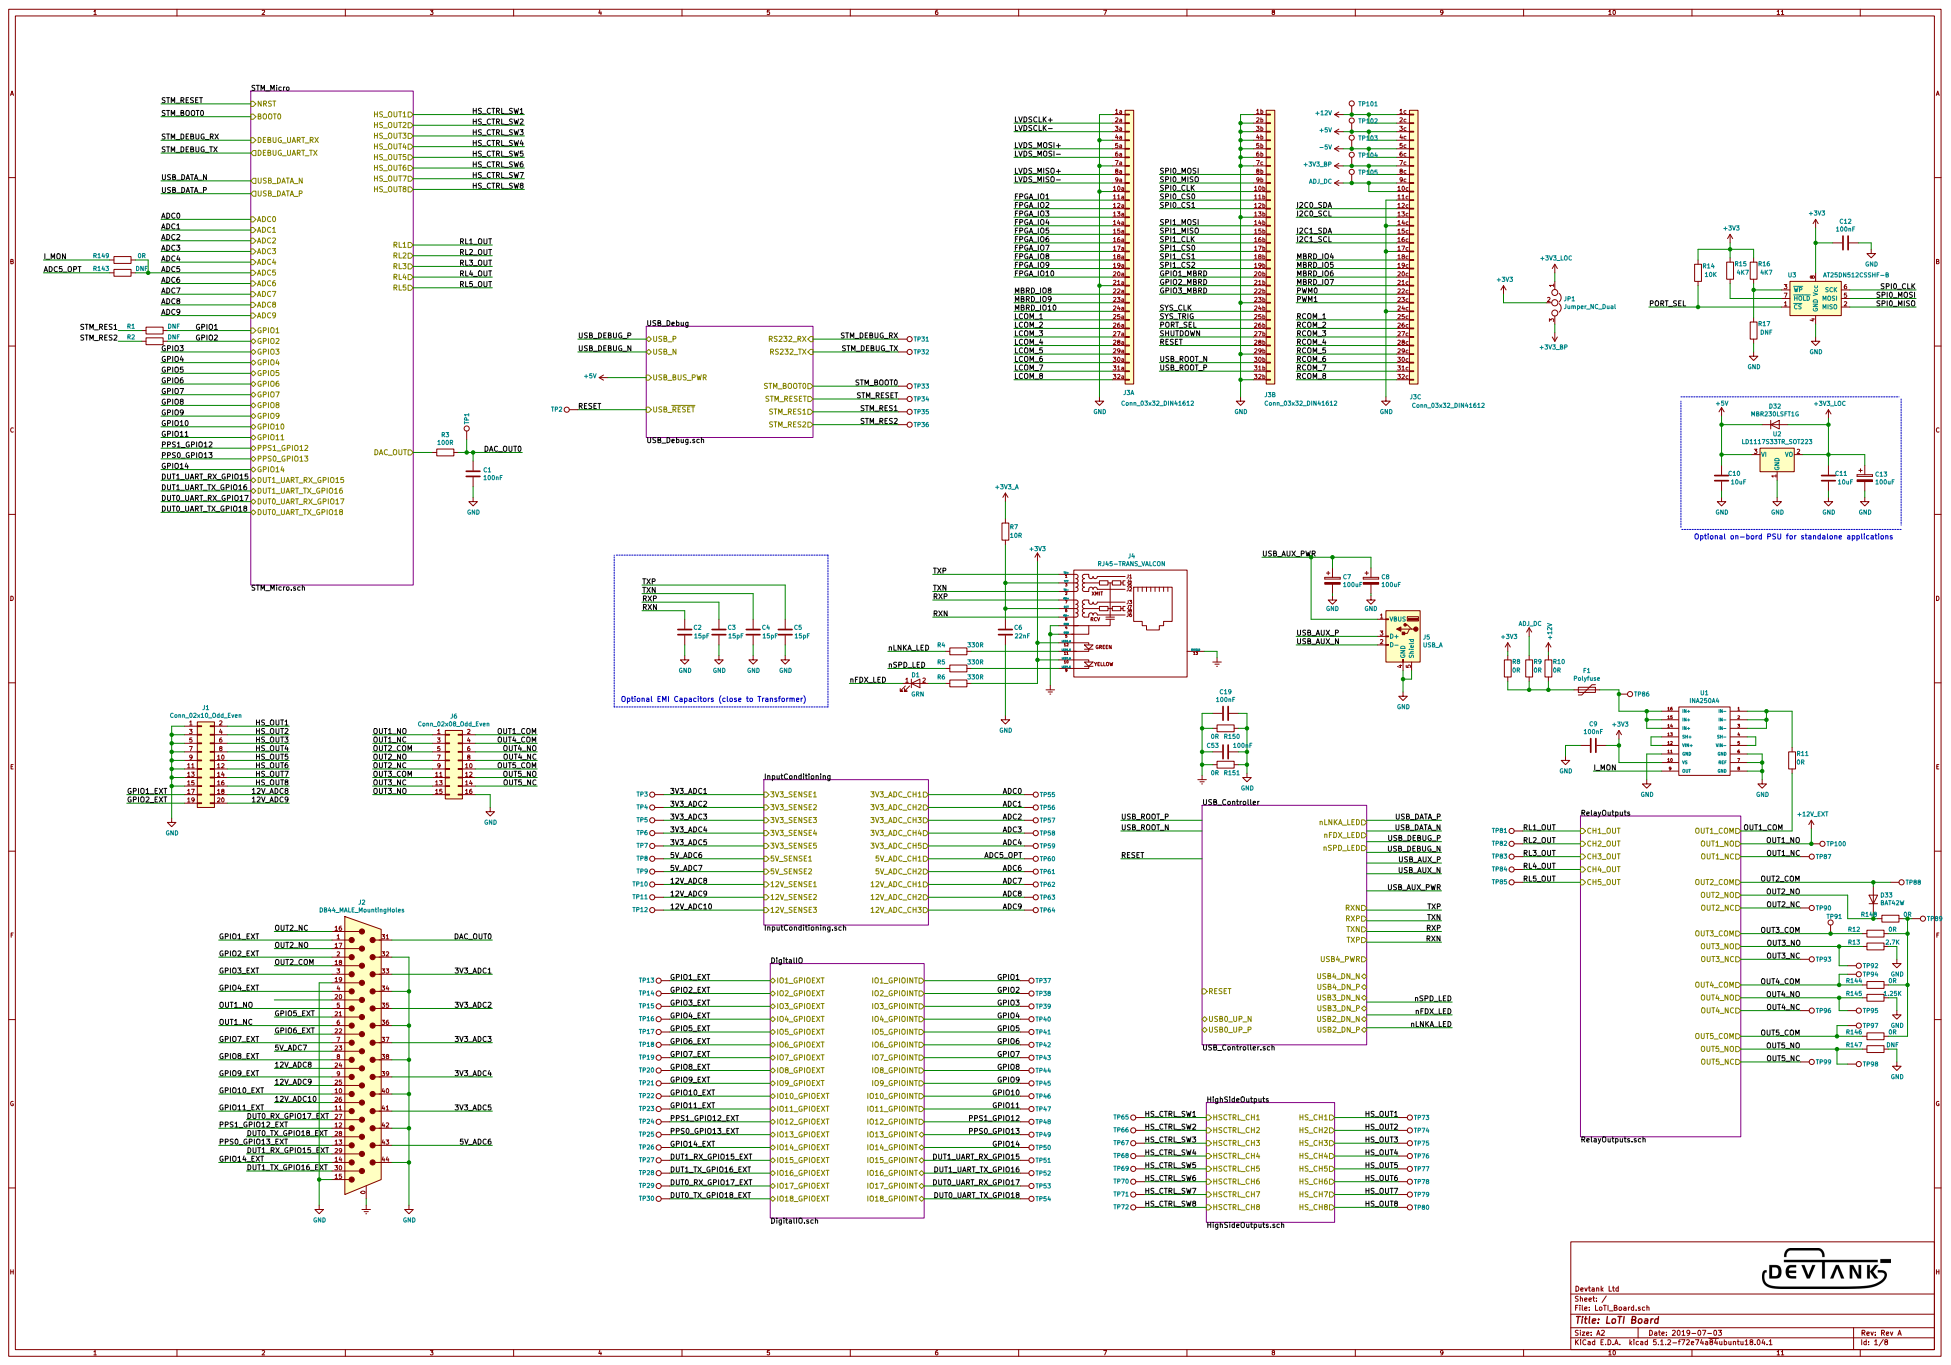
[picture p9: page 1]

LCOM_7 | 31a | USB_ROOT_P | 31b | RCOM_7
LCOM_8 | 32a | | 32b | RCOM_8

100uF GND Optional on-bord PSU for standalone applications D32 MBR230LSFT1G

File: LoTI_Board.sch Sheet: / Devtank Ltd

Id: 1/8 Title: LoTI Board

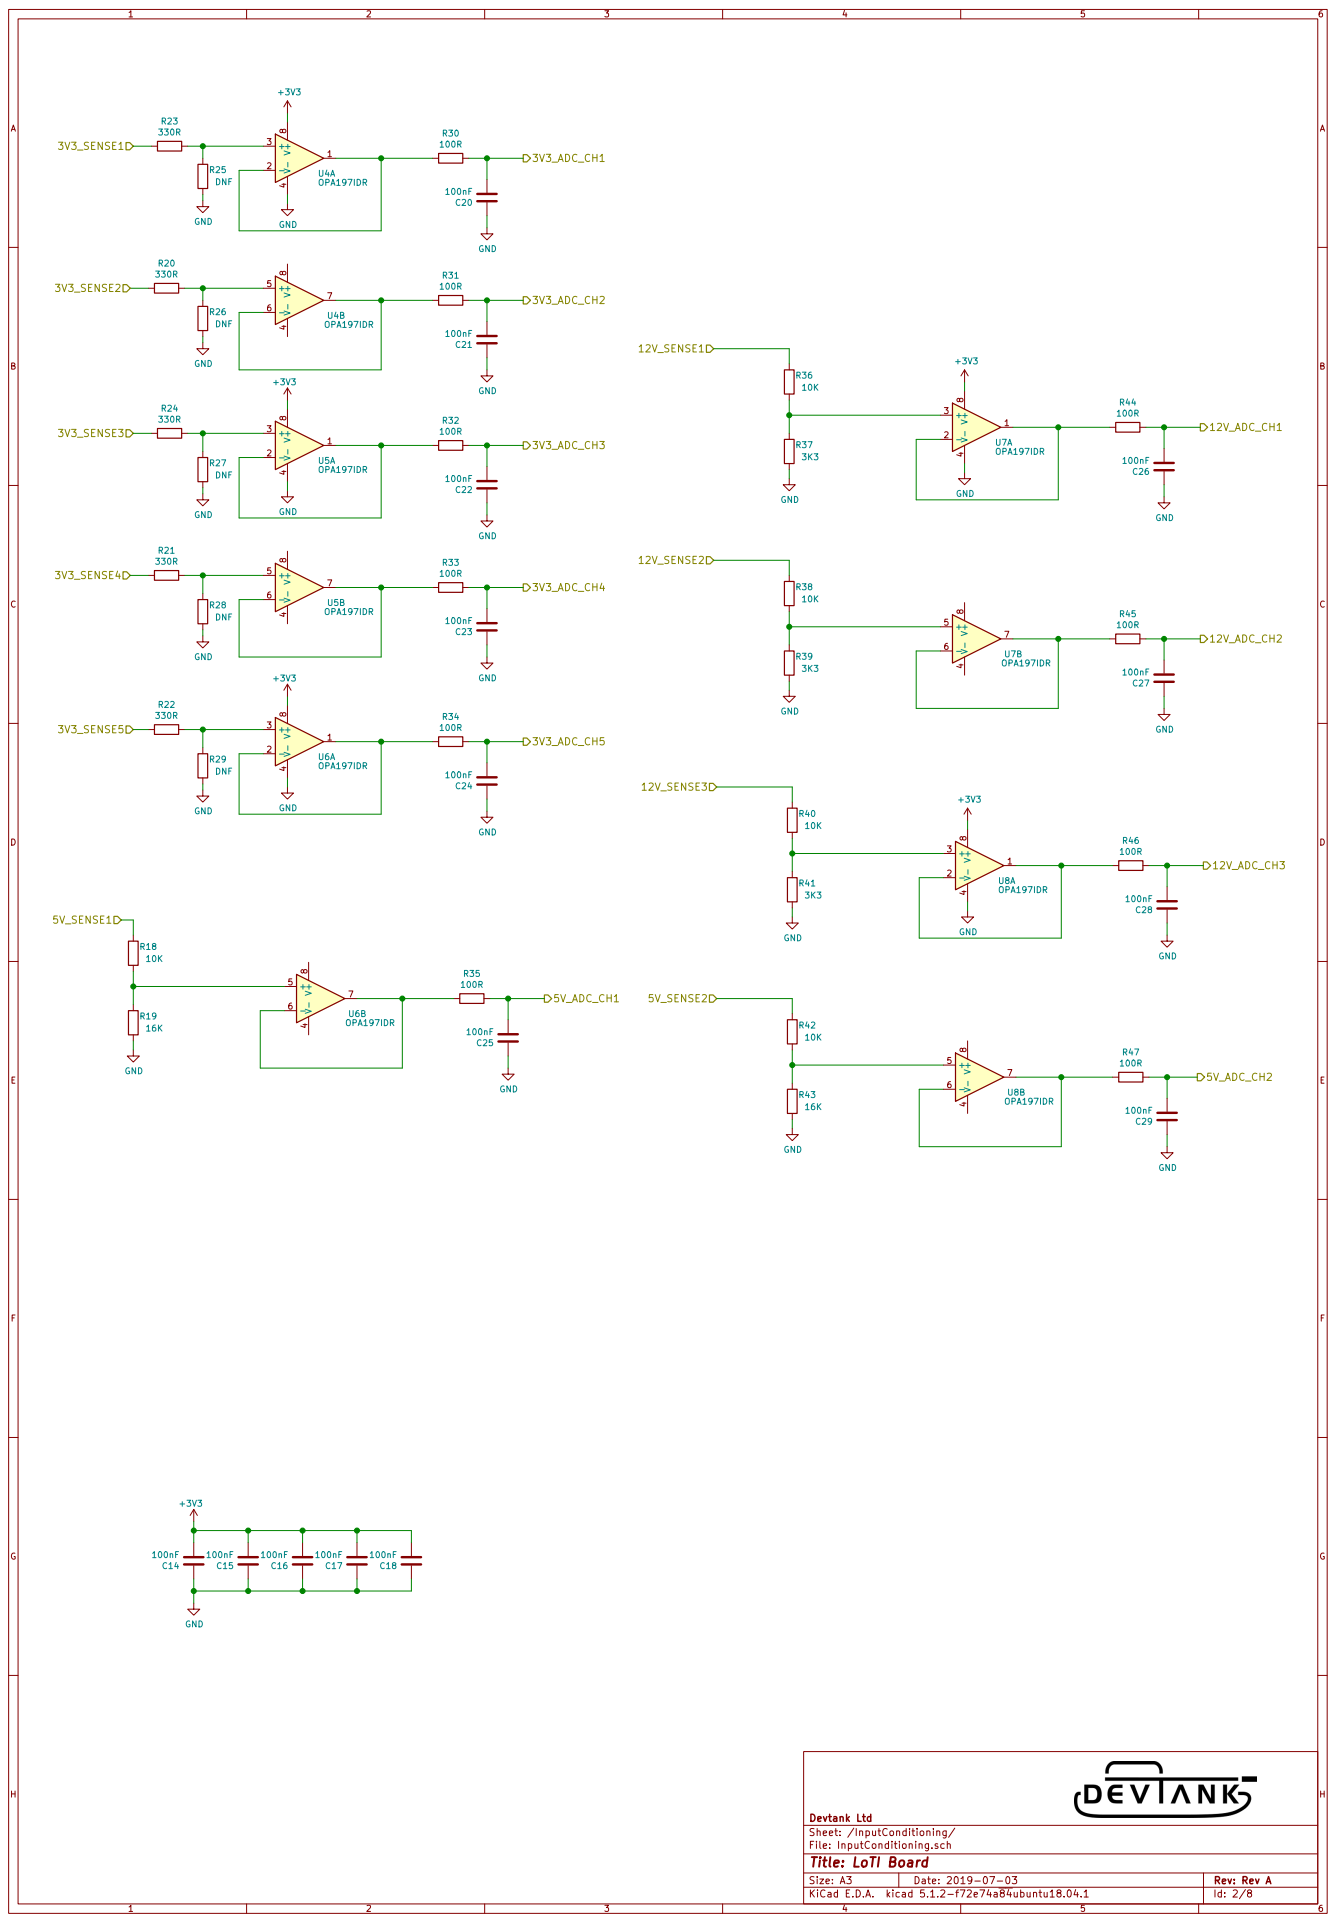
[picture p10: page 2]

Sheet: /InputConditioning/ Devtank Ltd

File: InputConditioning.sch
Id: 2/8 Title: LoTI Board

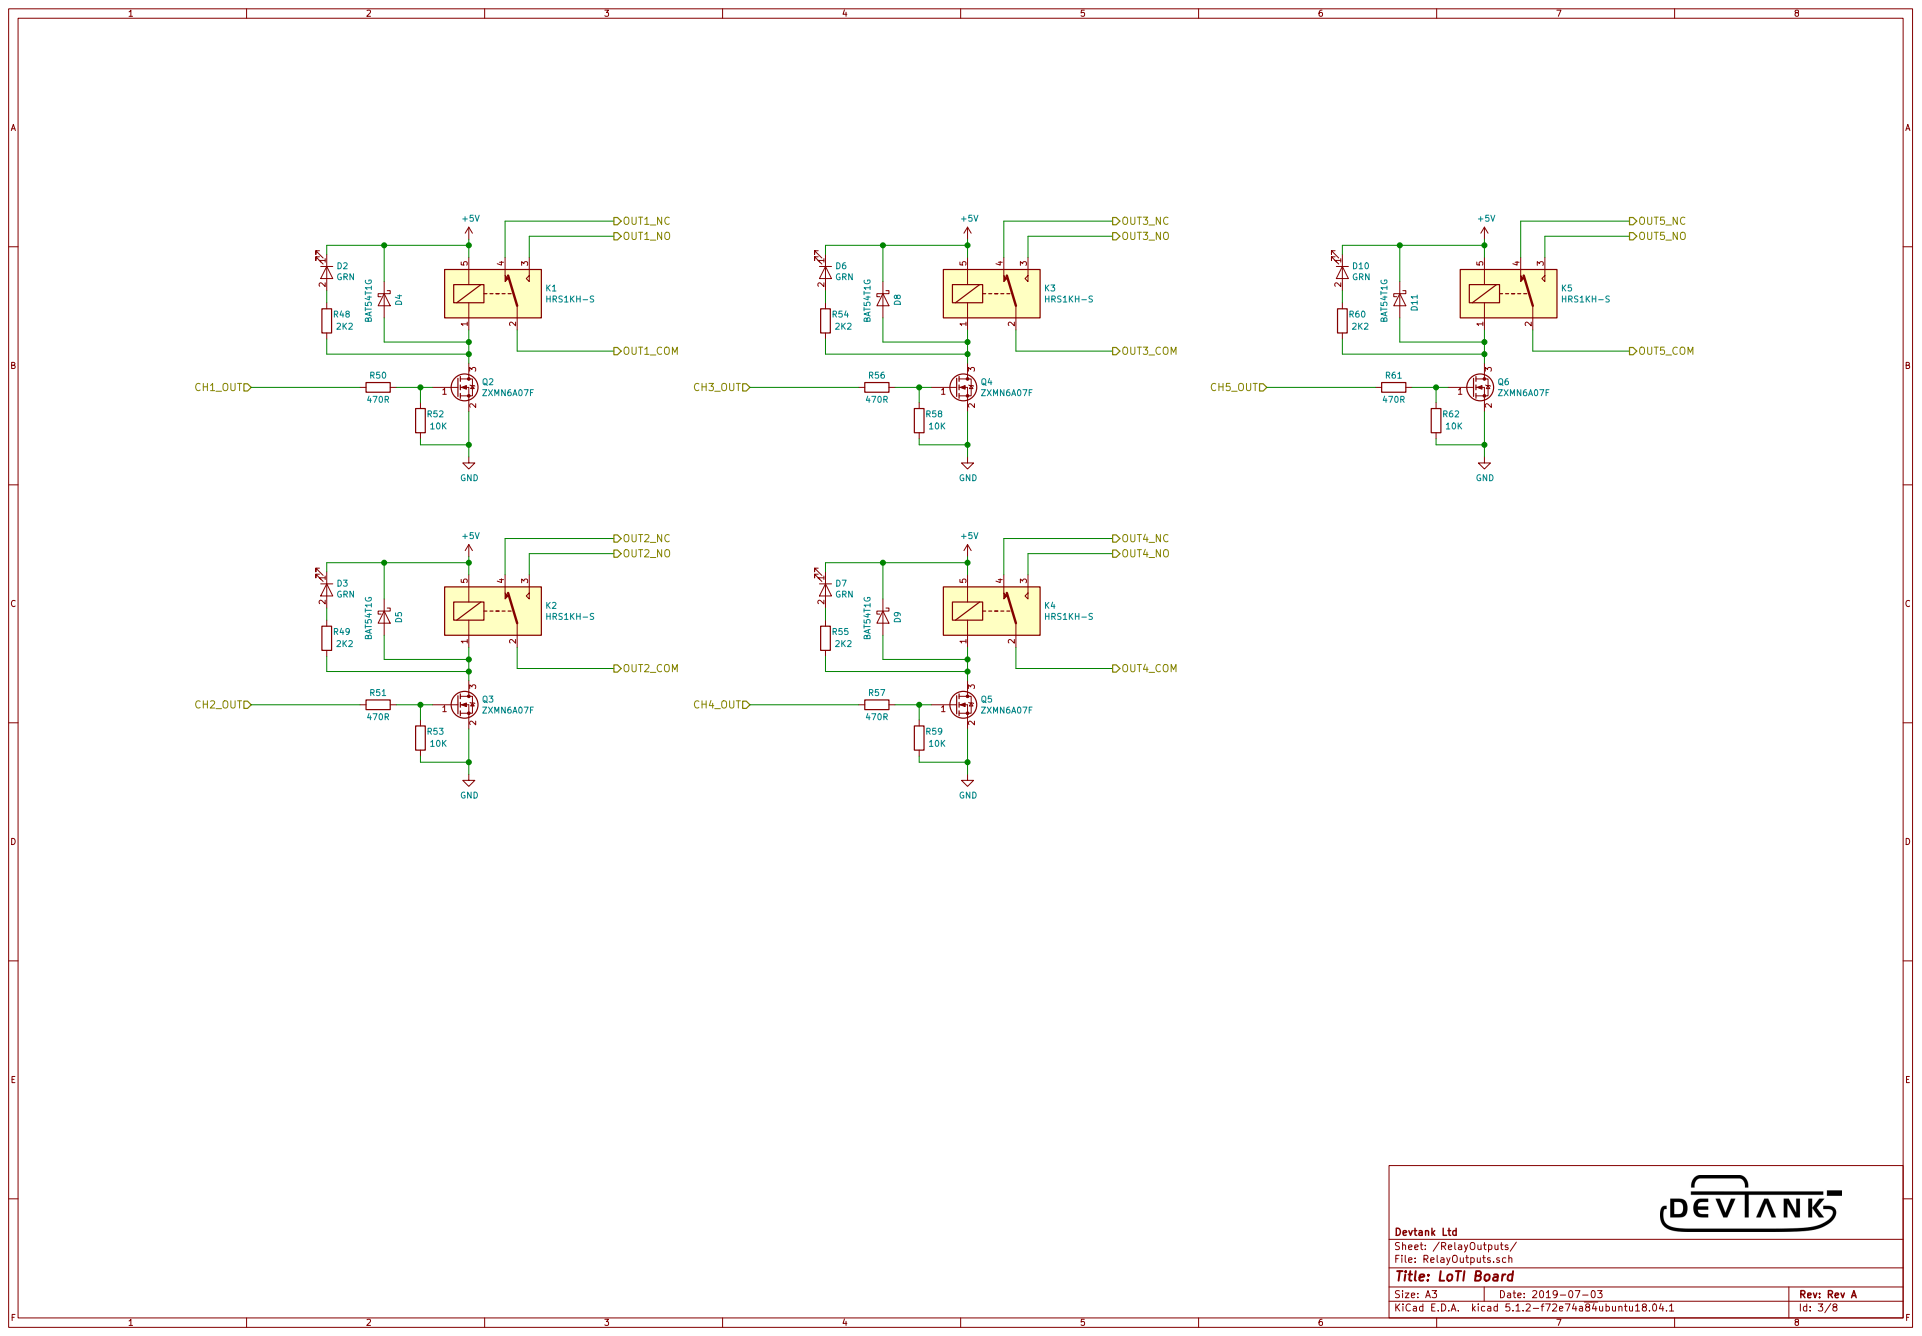
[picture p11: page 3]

Sheet: /RelayOutputs/ Devtank Ltd

File: RelayOutputs.sch
Id: 3/8 Title: LoTI Board

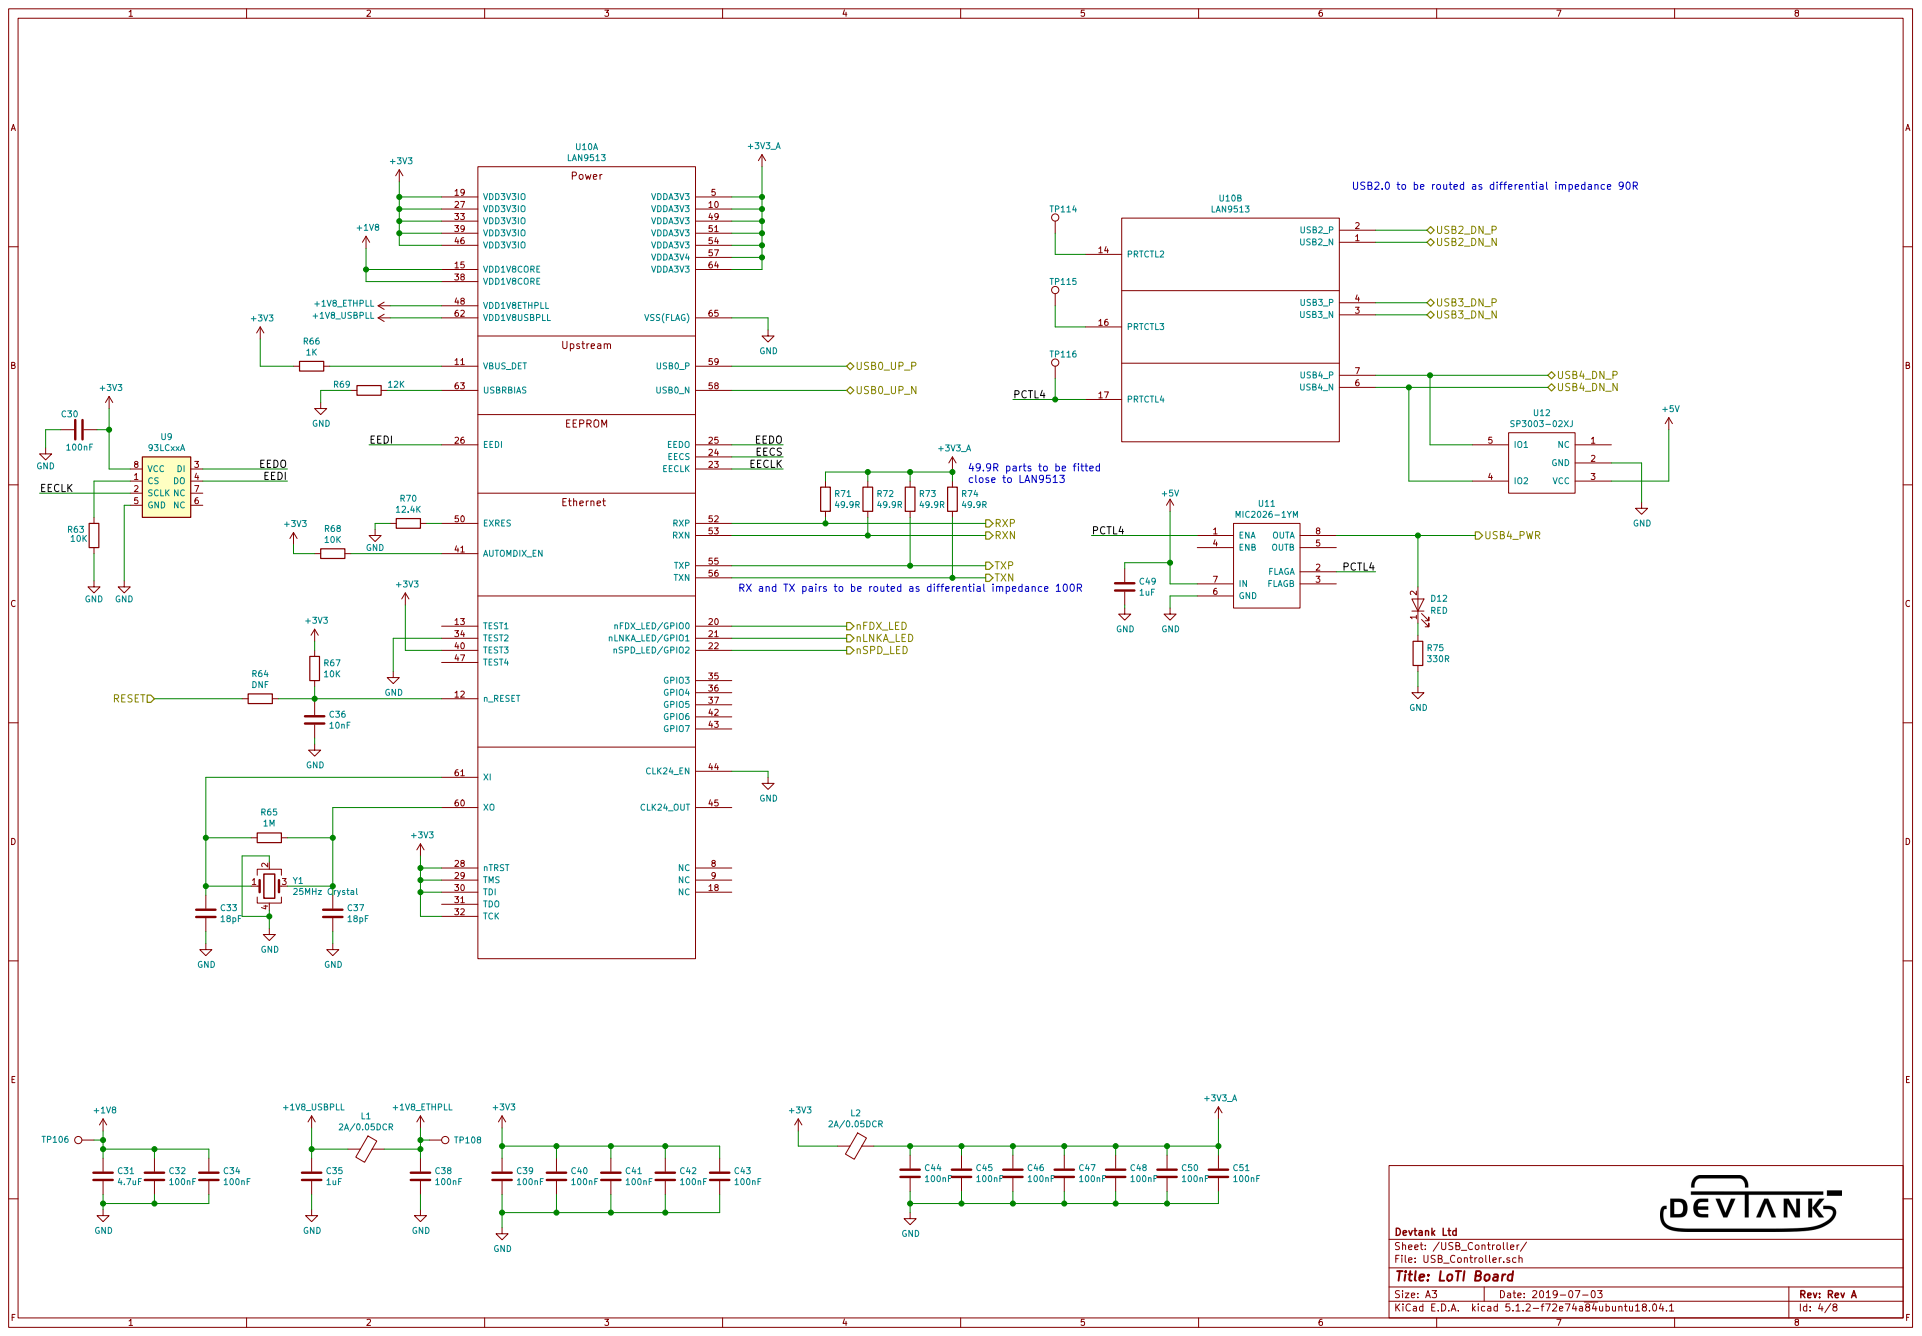
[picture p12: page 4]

USB2.0 to be routed as differential impedance 90R

TP114 TP115 TP116 49.9R parts to be fitted close to LAN9513

File: USB_Controller.sch
Id: 4/8 Title: LoTI Board


6 REGIN 7 VBUS 8 RSTb 9 U13 CP2102N-A01-GQFN24 GND

2 RXD 20 TXD 21 DSR 22 DTR 23 DCD 24 GND 25 D+ 3 D- 4 VIO

File: USB_Debug.sch
Id: 5/8 Title: LoTI Board


Place LC Close to
output connector
for all channels

Sheet: /HighSideOutputs/ Devtank Ltd IN

File: HighSideOutputs.sch
Id: 6/8 Title: LoTI Board


File: STM_Micro.sch
Id: 7/8 Title: LoTI Board


3V3 BI-DIRECTIONAL IO (5V TOLERANT)

Sheet: /DigitalIO/ Devtank Ltd

File: DigitalIO.sch
Id: 8/8 Title: LoTI Board

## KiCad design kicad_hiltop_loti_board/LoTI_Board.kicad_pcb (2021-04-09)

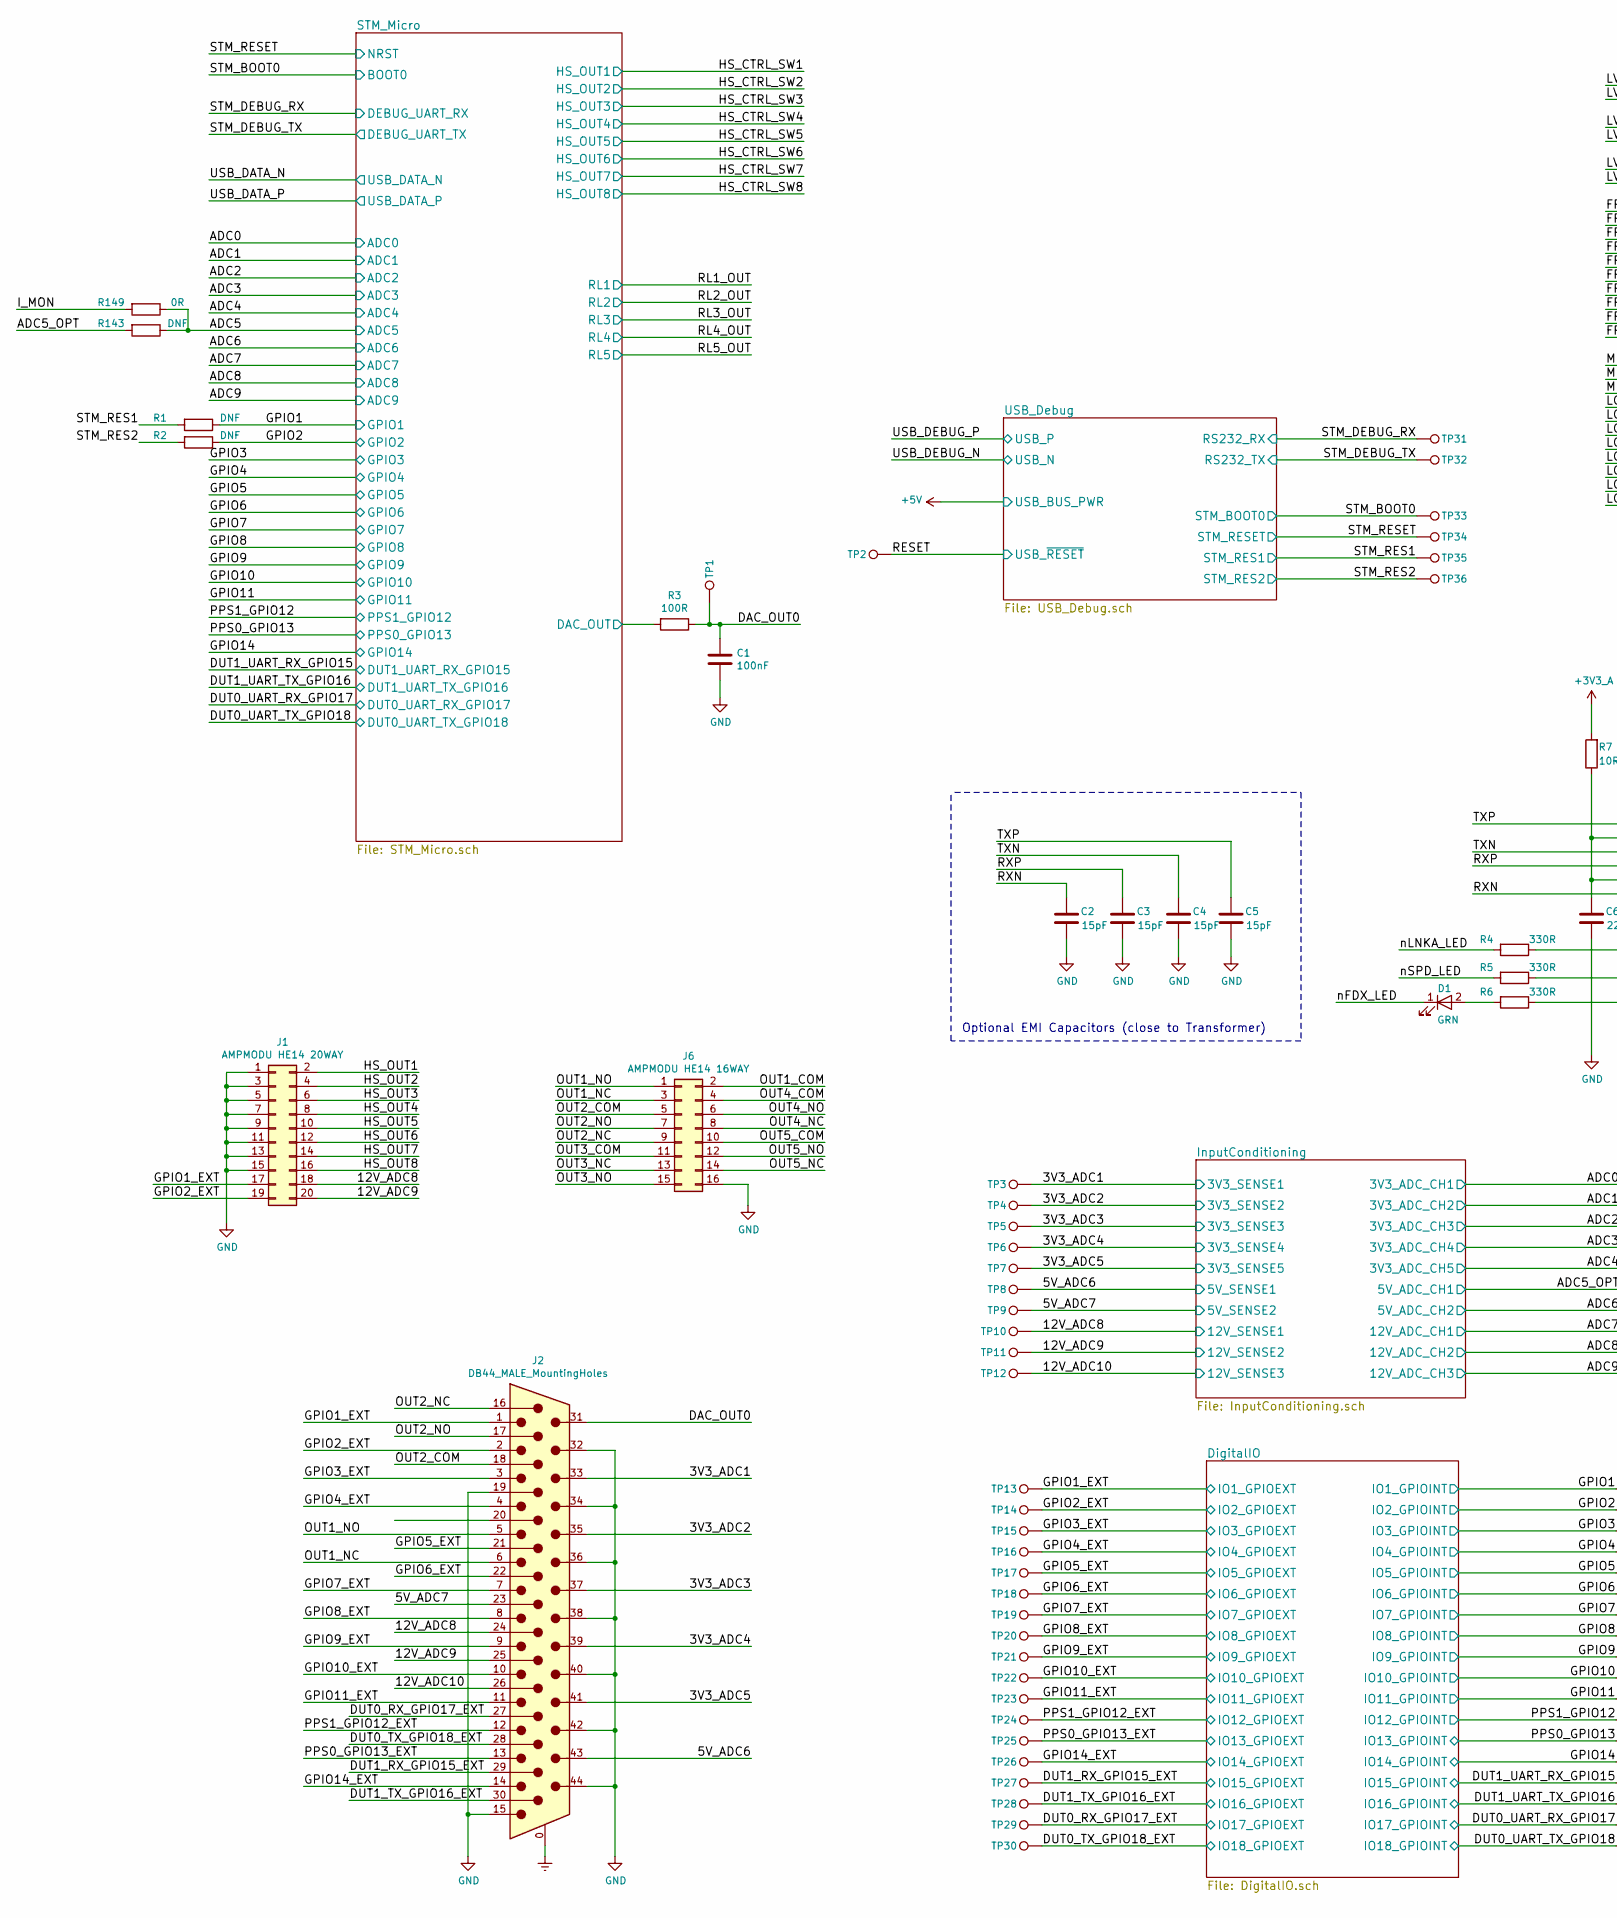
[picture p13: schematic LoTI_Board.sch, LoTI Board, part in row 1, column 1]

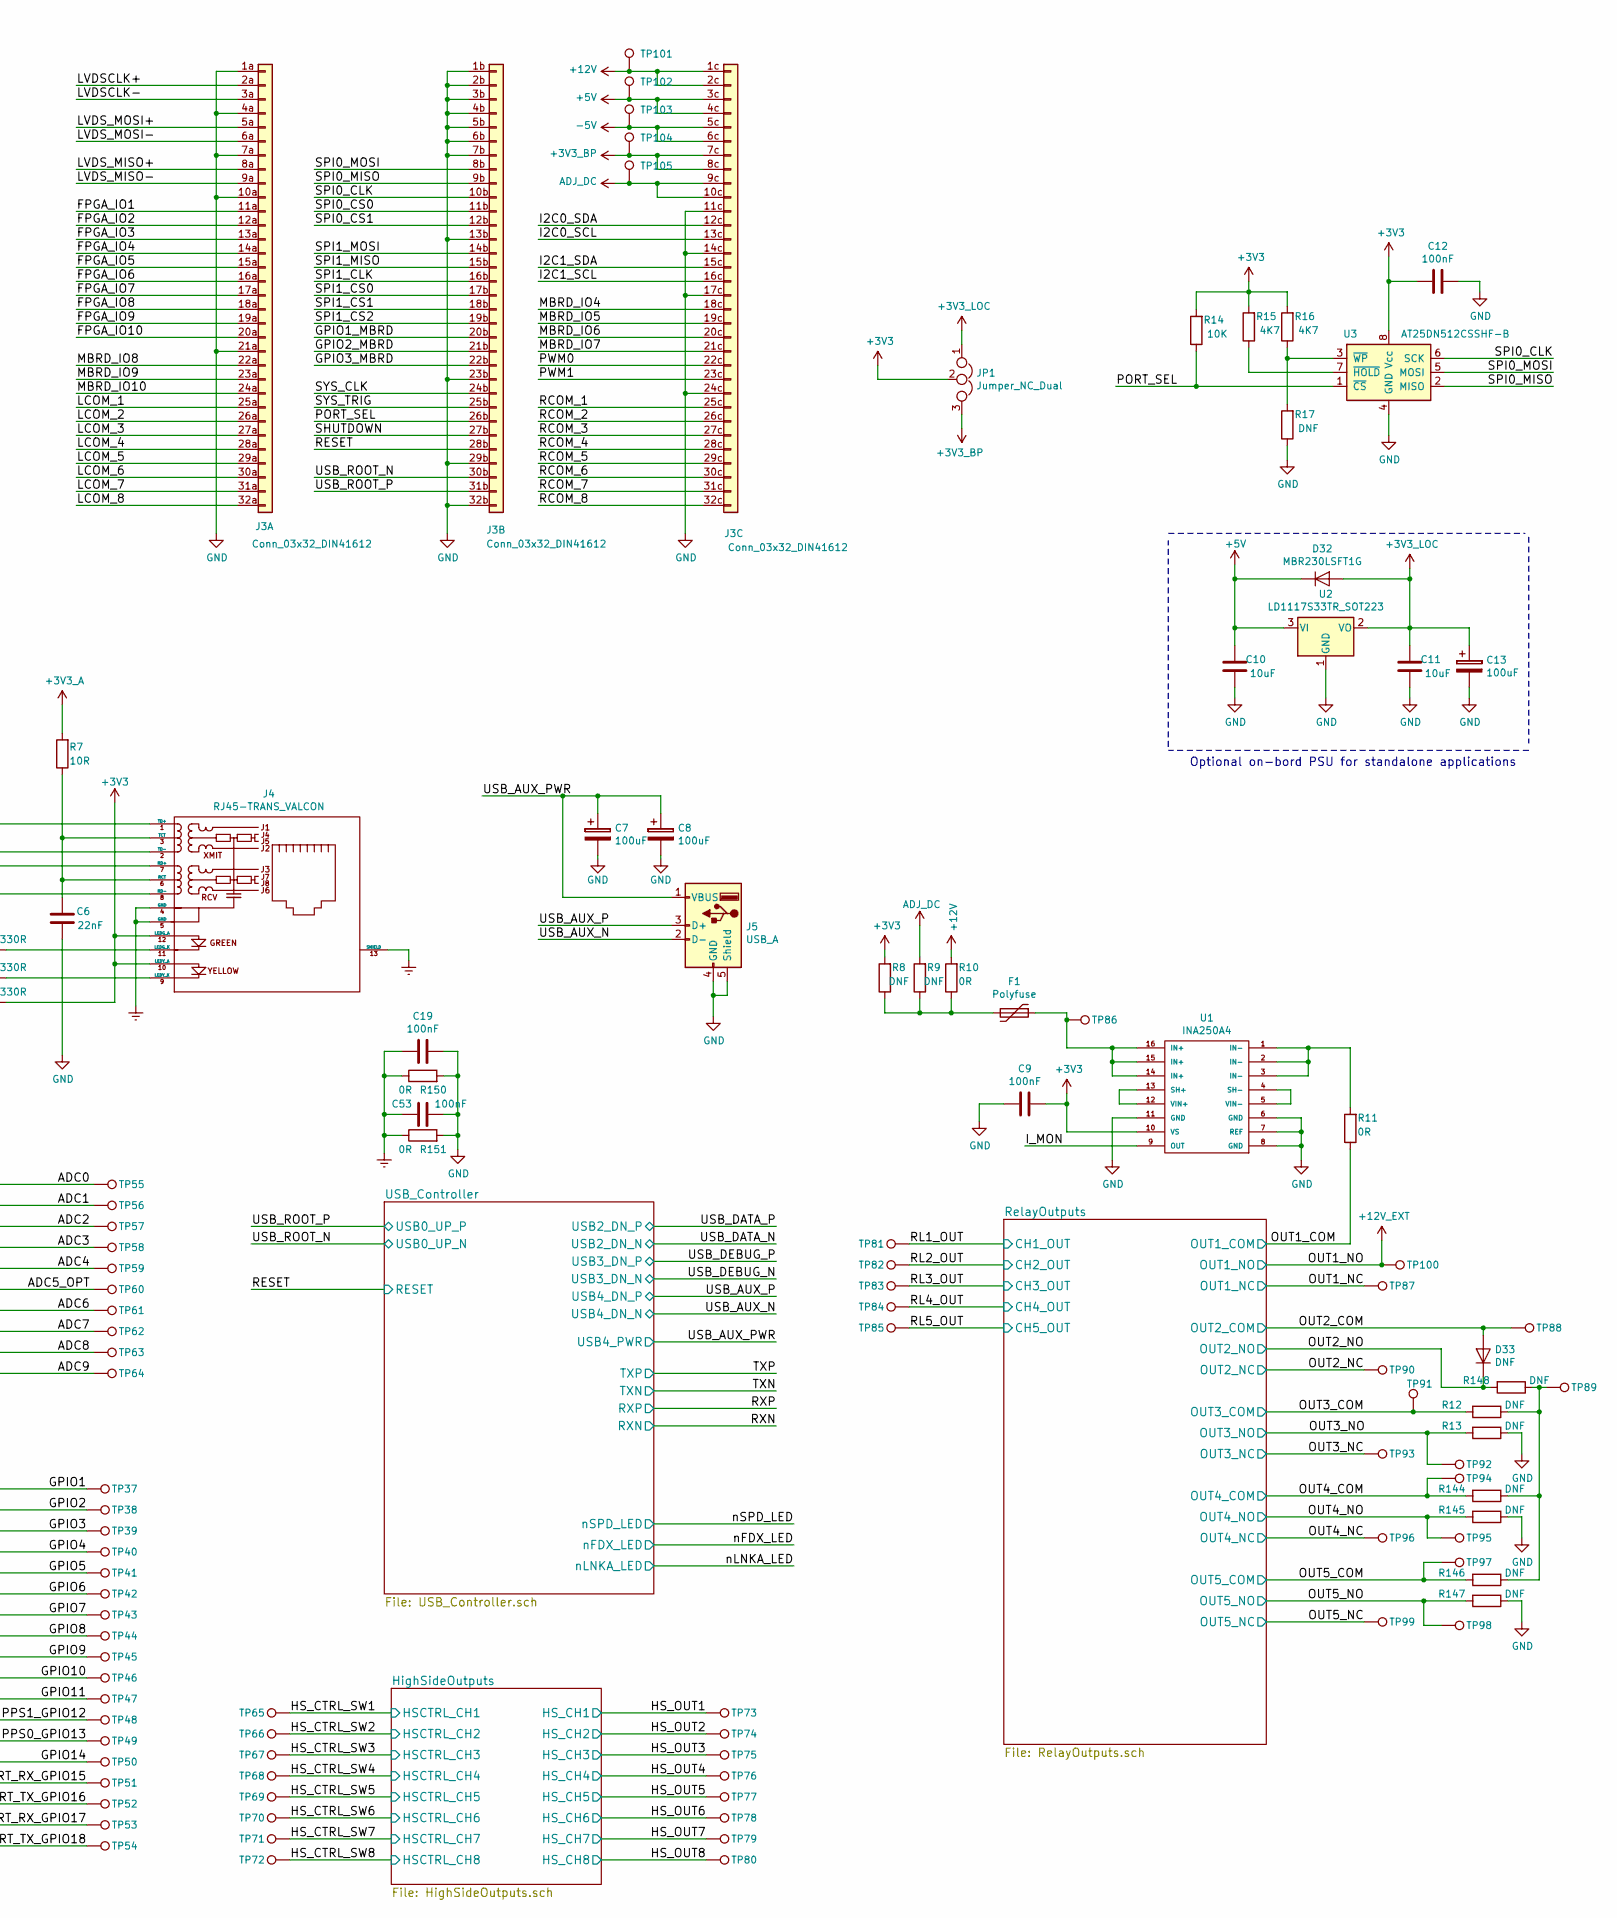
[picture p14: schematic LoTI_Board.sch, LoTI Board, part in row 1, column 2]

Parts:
C1, C9, C12: 100nF; C_0603_1608Metric
C2, C3, C4, C5: 15pF; C_0402_1005Metric
C6: 22nF; R_0603_1608Metric
C7, C8, C13: 100uF; CP_Elec_6.3x7.7
C10, C11: 10uF; C_0805_2012Metric
C19, C53: 100nF; R_1210_3225Metric
D1: GRN; LED_0603_1608Metric
D32: MBR230LSFT1G; D_SOD-123
D33: DNF; D_SOD-123
F1: Polyfuse; R_1206_3216Metric
J1: AMPMODU HE14 20WAY; IDC-Header_2x10_P2.54mm_Vertical
J2: DB44_MALE_MountingHoles; DSUB-44-HD_Female_Horizontal_P2.29x1.98mm_EdgePinOffset8.35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
J3: Conn_03x32_DIN41612; Socket_DIN41612-CaseC1-full-Male-96Pin-3rows_correct
J4: RJ45-TRANS_VALCON; RJ45_TRANSFO_VALCON
J5: USB_A; USB_A_Vertical_Lumberg_2410_01
J6: AMPMODU HE14 16WAY; IDC-Header_2x08_P2.54mm_Vertical
JP1: Jumper_NC_Dual; PinHeader_1x03_P2.54mm_Vertical
R1, R2, R12, R13, R17, R143, R144, R145, R146, R147, R148: DNF; R_0603_1608Metric
R3: 100R; R_0603_1608Metric
R4, R5, R6: 330R; R_0603_1608Metric
R7: 10R; R_0402_1005Metric
R8, R9: DNF; R_1206_3216Metric
R10, R11: 0R; R_1206_3216Metric
R14: 10K; R_0603_1608Metric
R15, R16: 4K7; R_0603_1608Metric
R149: 0R; R_0603_1608Metric
R150, R151: 0R; R_1210_3225Metric
TP1, TP2, TP3, TP4, TP5, TP6, TP7, TP8, TP9, TP10, TP11, TP12, TP13, TP14, TP15, TP16, TP17, TP18, TP19, TP20, TP21, TP22, TP23, TP24, TP25, TP26, TP27, TP28, TP29, TP30, TP31, TP32, TP33, TP34, TP35, TP36, TP37, TP38, TP39, TP40, TP41, TP42, TP43, TP44, TP45, TP46, TP47, TP48, TP49, TP50, TP51, TP52, TP53, TP54, TP55, TP56, TP57, TP58, TP59, TP60, TP61, TP62, TP63, TP64, TP65, TP66, TP67, TP68, TP69, TP70, TP71, TP72, TP73, TP74, TP75, TP76, TP77, TP78, TP79, TP80, TP81, TP82, TP83, TP84, TP85, TP86, TP87, TP88, TP89, TP90, TP91, TP92, TP93, TP94, TP95, TP96, TP97, TP98, TP99, TP100, TP101, TP102, TP103, TP104, TP105: Test_Point; TestPoint_THTPad_D1.0mm_Drill0.5mm
U1: INA250A4; TSSOP-16_4.4x5mm_P0.65mm
U2: LD1117S33TR_SOT223; SOT-223-3_TabPin2
U3: AT25DN512CSSHF-B; SOIC-8_3.9x4.9mm_P1.27mm

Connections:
+3V3: C9.1, C12.2, J4.10 (LEDY_A), J4.12 (LEDG_A), JP1.2, R6.1, R8.2, R14.2, R15.2, R16.2, U1.10 (VS), U3.8 (Vcc); also elsewhere on the board
+3V3_A: R7.2; also elsewhere on the board
+3V3_BP: J3.7c (Pin_7), J3.8c (Pin_8), JP1.3, TP104.1
+3V3_LOC: C11.2, C13.1, D32.2 (A), JP1.1, U2.2 (VO)
+5V: C10.2, D32.1 (K), J3.3c (Pin_3), J3.4c (Pin_4), TP102.1, U2.3 (VI); also elsewhere on the board
+12V: J3.1c (Pin_1), J3.2c (Pin_2), R10.2, TP101.1; also elsewhere on the board
+12V_EXT: J2.5, J6.1, TP100.1; also elsewhere on the board
-5V: J3.5c (Pin_5), J3.6c (Pin_6), TP103.1
/3V3_ADC1: J2.33, TP3.1; also elsewhere on the board
/3V3_ADC2: J2.35, TP4.1; also elsewhere on the board
/3V3_ADC3: J2.37, TP5.1; also elsewhere on the board
/3V3_ADC4: J2.39, TP6.1; also elsewhere on the board
/3V3_ADC5: J2.41, TP7.1; also elsewhere on the board
/5V_ADC6: J2.43, TP8.1; also elsewhere on the board
/5V_ADC7: J2.23, TP9.1; also elsewhere on the board
/12V_ADC8: J1.18, J2.24, TP10.1; also elsewhere on the board
/12V_ADC9: J1.20, J2.25, TP11.1; also elsewhere on the board
/12V_ADC10: J2.26, TP12.1; also elsewhere on the board
/ADC0: TP55.1; also elsewhere on the board
/ADC1: TP56.1; also elsewhere on the board
/ADC2: TP57.1; also elsewhere on the board
/ADC3: TP58.1; also elsewhere on the board
/ADC4: TP59.1; also elsewhere on the board
/ADC5: R143.1, R149.1; also elsewhere on the board
/ADC5_OPT: R143.2, TP60.1; also elsewhere on the board
/ADC6: TP61.1; also elsewhere on the board
/ADC7: TP62.1; also elsewhere on the board
/ADC8: TP63.1; also elsewhere on the board
/ADC9: TP64.1; also elsewhere on the board
/DAC_OUT0: C1.1, J2.31, R3.1, TP1.1
/DUT0_RX_GPIO17_EXT: J2.27, TP29.1; also elsewhere on the board
/DUT0_TX_GPIO18_EXT: J2.28, TP30.1; also elsewhere on the board
/DUT0_UART_RX_GPIO17: TP53.1; also elsewhere on the board
/DUT0_UART_TX_GPIO18: TP54.1; also elsewhere on the board
/DUT1_RX_GPIO15_EXT: J2.29, TP27.1; also elsewhere on the board
/DUT1_TX_GPIO16_EXT: J2.30, TP28.1; also elsewhere on the board
/DUT1_UART_RX_GPIO15: TP51.1; also elsewhere on the board
/DUT1_UART_TX_GPIO16: TP52.1; also elsewhere on the board
/FPGA_IO1: J3.11a (Pin_11)
/FPGA_IO2: J3.12a (Pin_12)
/FPGA_IO3: J3.13a (Pin_13)
/FPGA_IO4: J3.14a (Pin_14)
/FPGA_IO5: J3.15a (Pin_15)
/FPGA_IO6: J3.16a (Pin_16)
/FPGA_IO7: J3.17a (Pin_17)
/FPGA_IO8: J3.18a (Pin_18)
/FPGA_IO9: J3.19a (Pin_19)
/FPGA_IO10: J3.20a (Pin_20)
/GPIO1: R1.1, TP37.1; also elsewhere on the board
/GPIO1_EXT: J1.17, J2.1, TP13.1; also elsewhere on the board
/GPIO1_MBRD: J3.20b (Pin_20)
/GPIO2: R2.1, TP38.1; also elsewhere on the board
/GPIO2_EXT: J1.19, J2.2, TP14.1; also elsewhere on the board
/GPIO2_MBRD: J3.21b (Pin_21)
/GPIO3: TP39.1; also elsewhere on the board
/GPIO3_EXT: J2.3, TP15.1; also elsewhere on the board
/GPIO3_MBRD: J3.22b (Pin_22)
/GPIO4: TP40.1; also elsewhere on the board
/GPIO4_EXT: J2.4, TP16.1; also elsewhere on the board
/GPIO5: TP41.1; also elsewhere on the board
/GPIO5_EXT: J2.21, TP17.1; also elsewhere on the board
/GPIO6: TP42.1; also elsewhere on the board
/GPIO6_EXT: J2.22, TP18.1; also elsewhere on the board
/GPIO7: TP43.1; also elsewhere on the board
/GPIO7_EXT: J2.7, TP19.1; also elsewhere on the board
/GPIO8: TP44.1; also elsewhere on the board
/GPIO8_EXT: J2.8, TP20.1; also elsewhere on the board
/GPIO9: TP45.1; also elsewhere on the board
/GPIO9_EXT: J2.9, TP21.1; also elsewhere on the board
/GPIO10: TP46.1; also elsewhere on the board
/GPIO10_EXT: J2.10, TP22.1; also elsewhere on the board
/GPIO11: TP47.1; also elsewhere on the board
/GPIO11_EXT: J2.11, TP23.1; also elsewhere on the board
/GPIO14: TP50.1; also elsewhere on the board
/GPIO14_EXT: J2.14, TP26.1; also elsewhere on the board
/HS_CTRL_SW1: TP65.1; also elsewhere on the board
/HS_CTRL_SW2: TP66.1; also elsewhere on the board
/HS_CTRL_SW3: TP67.1; also elsewhere on the board
/HS_CTRL_SW4: TP68.1; also elsewhere on the board
/HS_CTRL_SW5: TP69.1; also elsewhere on the board
/HS_CTRL_SW6: TP70.1; also elsewhere on the board
/HS_CTRL_SW7: TP71.1; also elsewhere on the board
/HS_CTRL_SW8: TP72.1; also elsewhere on the board
/HS_OUT1: J1.2, TP73.1; also elsewhere on the board
/HS_OUT2: J1.4, TP74.1; also elsewhere on the board
/HS_OUT3: J1.6, TP75.1; also elsewhere on the board
/HS_OUT4: J1.8, TP76.1; also elsewhere on the board
/HS_OUT5: J1.10, TP77.1; also elsewhere on the board
/HS_OUT6: J1.12, TP78.1; also elsewhere on the board
/HS_OUT7: J1.14, TP79.1; also elsewhere on the board
/HS_OUT8: J1.16, TP80.1; also elsewhere on the board
/I2C0_SCL: J3.13c (Pin_13)
/I2C0_SDA: J3.12c (Pin_12)
/I2C1_SCL: J3.16c (Pin_16)
/I2C1_SDA: J3.15c (Pin_15)
/I_MON: R149.2, U1.9 (OUT)
/LCOM_1: J3.25a (Pin_25)
/LCOM_2: J3.26a (Pin_26)
/LCOM_3: J3.27a (Pin_27)
/LCOM_4: J3.28a (Pin_28)
/LCOM_5: J3.29a (Pin_29)
/LCOM_6: J3.30a (Pin_30)
/LCOM_7: J3.31a (Pin_31)
/LCOM_8: J3.32a (Pin_32)
/LVDSCLK+: J3.2a (Pin_2)
/LVDSCLK-: J3.3a (Pin_3)
/LVDS_MISO+: J3.8a (Pin_8)
/LVDS_MISO-: J3.9a (Pin_9)
/LVDS_MOSI+: J3.5a (Pin_5)
/LVDS_MOSI-: J3.6a (Pin_6)
/MBRD_IO4: J3.18c (Pin_18)
/MBRD_IO5: J3.19c (Pin_19)
/MBRD_IO6: J3.20c (Pin_20)
/MBRD_IO7: J3.21c (Pin_21)
/MBRD_IO8: J3.22a (Pin_22)
/MBRD_IO9: J3.23a (Pin_23)
/MBRD_IO10: J3.24a (Pin_24)
/OUT1_COM: J6.2, R11.1; also elsewhere on the board
/OUT1_NC: J2.6, J6.3, TP87.1; also elsewhere on the board
/OUT2_COM: D33.2 (A), J2.18, J6.5, TP88.1; also elsewhere on the board
/OUT2_NC: J2.16, J6.9, TP90.1; also elsewhere on the board
/OUT2_NO: D33.1 (K), J2.17, J6.7, R148.2; also elsewhere on the board
/OUT3_COM: J6.11, R12.2, TP91.1; also elsewhere on the board
/OUT3_NC: J6.13, TP93.1; also elsewhere on the board
/OUT3_NO: J6.15, R13.2, TP92.1; also elsewhere on the board
/OUT4_COM: J6.4, R144.2, TP94.1; also elsewhere on the board
/OUT4_NC: J6.8, TP96.1; also elsewhere on the board
/OUT4_NO: J6.6, R145.2, TP95.1; also elsewhere on the board
/OUT5_COM: J6.10, R146.2, TP97.1; also elsewhere on the board
/OUT5_NC: J6.14, TP99.1; also elsewhere on the board
/OUT5_NO: J6.12, R147.2, TP98.1; also elsewhere on the board
/PORT_SEL: J3.26b (Pin_26), R14.1, U3.1 (~CS)
/PPS0_GPIO13: TP49.1; also elsewhere on the board
/PPS0_GPIO13_EXT: J2.13, TP25.1; also elsewhere on the board
/PPS1_GPIO12: TP48.1; also elsewhere on the board
/PPS1_GPIO12_EXT: J2.12, TP24.1; also elsewhere on the board
/PWM0: J3.22c (Pin_22)
/PWM1: J3.23c (Pin_23)
/RCOM_1: J3.25c (Pin_25)
/RCOM_2: J3.26c (Pin_26)
/RCOM_3: J3.27c (Pin_27)
/RCOM_4: J3.28c (Pin_28)
/RCOM_5: J3.29c (Pin_29)
/RCOM_6: J3.30c (Pin_30)
/RCOM_7: J3.31c (Pin_31)
/RCOM_8: J3.32c (Pin_32)
/RESET: J3.28b (Pin_28), TP2.1; also elsewhere on the board
/RL1_OUT: TP81.1; also elsewhere on the board
/RL2_OUT: TP82.1; also elsewhere on the board
/RL3_OUT: TP83.1; also elsewhere on the board
/RL4_OUT: TP84.1; also elsewhere on the board
/RL5_OUT: TP85.1; also elsewhere on the board
/RXN: C2.2, J4.8 (RD-); also elsewhere on the board
/RXP: C3.2, J4.7 (RD+); also elsewhere on the board
/SHUTDOWN: J3.27b (Pin_27)
/SPI0_CLK: J3.10b (Pin_10), U3.6 (SCK)
/SPI0_CS0: J3.11b (Pin_11)
/SPI0_CS1: J3.12b (Pin_12)
/SPI0_MISO: J3.9b (Pin_9), U3.2 (MISO)
/SPI0_MOSI: J3.8b (Pin_8), U3.5 (MOSI)
/SPI1_CLK: J3.16b (Pin_16)
/SPI1_CS0: J3.17b (Pin_17)
/SPI1_CS1: J3.18b (Pin_18)
/SPI1_CS2: J3.19b (Pin_19)
/SPI1_MISO: J3.15b (Pin_15)
/SPI1_MOSI: J3.14b (Pin_14)
/STM_BOOT0: TP33.1; also elsewhere on the board
/STM_DEBUG_RX: TP31.1; also elsewhere on the board
/STM_DEBUG_TX: TP32.1; also elsewhere on the board
/STM_Micro/DAC_OUT: R3.2; also elsewhere on the board
/STM_RES1: R1.2, TP35.1; also elsewhere on the board
/STM_RES2: R2.2, TP36.1; also elsewhere on the board
/STM_RESET: TP34.1; also elsewhere on the board
/SYS_CLK: J3.24b (Pin_24)
/SYS_TRIG: J3.25b (Pin_25)
/TXN: C4.2, J4.2 (TD-); also elsewhere on the board
/TXP: C5.2, J4.1 (TD+); also elsewhere on the board
/USB_AUX_N: J5.2 (D-); also elsewhere on the board
/USB_AUX_P: J5.3 (D+); also elsewhere on the board
/USB_AUX_PWR: C7.1, C8.1, J5.1 (VBUS); also elsewhere on the board
/USB_ROOT_N: J3.30b (Pin_30); also elsewhere on the board
/USB_ROOT_P: J3.31b (Pin_31); also elsewhere on the board
/nFDX_LED: D1.1 (K); also elsewhere on the board
/nLNKA_LED: R4.2; also elsewhere on the board
/nSPD_LED: R5.2; also elsewhere on the board
ADJ_DC: J3.9c (Pin_9), J3.10c (Pin_10), R9.2, TP105.1; also elsewhere on the board
Earth: C19.2, C53.2, J2.0 (PAD), J4.4 (GND), J4.5 (GND), J4.13 (SHIELD), R150.1, R151.1
GND: C1.2, C2.1, C3.1, C4.1, C5.1, C6.1, C7.2, C8.2, C9.2, C10.1, C11.1, C12.1, C13.2, C19.1, C53.1, J1.1, J1.3, J1.5, J1.7, J1.9, J1.11, J1.13, J1.15, J2.15, J2.19, J2.32, J2.34, J2.36, J2.38, J2.40, J2.42, J2.44, J3.1a (Pin_1), J3.1b (Pin_1), J3.2b (Pin_2), J3.3b (Pin_3), J3.4a (Pin_4), J3.4b (Pin_4), J3.5b (Pin_5), J3.6b (Pin_6), J3.7a (Pin_7), J3.7b (Pin_7), J3.10a (Pin_10), J3.11c (Pin_11), J3.13b (Pin_13), J3.14c (Pin_14), J3.17c (Pin_17), J3.21a (Pin_21), J3.23b (Pin_23), J3.24c (Pin_24), J3.29b (Pin_29), J3.32b (Pin_32), J5.4 (GND), J5.5 (Shield), J6.16, R13.1, R17.1, R145.1, R147.1, R150.2, R151.2, U1.6 (GND), U1.7 (REF), U1.8 (GND), U1.11 (GND), U2.1 (GND), U3.4 (GND); also elsewhere on the board
unnamed: C6.2, J4.3 (TCT), J4.6 (RCT), R7.1
unnamed: D1.2 (A), R6.2
unnamed: F1.1, TP86.1, U1.14 (IN+), U1.15 (IN+), U1.16 (IN+)
unnamed: F1.2, R8.1, R9.1, R10.1
unnamed: J4.9 (LEDY_K), R5.1
unnamed: J4.11 (LEDG_K), R4.1
unnamed: R11.2, U1.1 (IN-), U1.2 (IN-), U1.3 (IN-)
unnamed: R12.1, R144.1, R146.1, R148.1, TP89.1
unnamed: R15.1, U3.7 (~HOLD)
unnamed: R16.1, R17.2, U3.3 (~WP)
unnamed: U1.4 (SH-), U1.5 (VIN-)
unnamed: U1.12 (VIN+), U1.13 (SH+)

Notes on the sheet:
Optional EMI Capacitors (close to Transformer)
Optional on-bord PSU for standalone applications

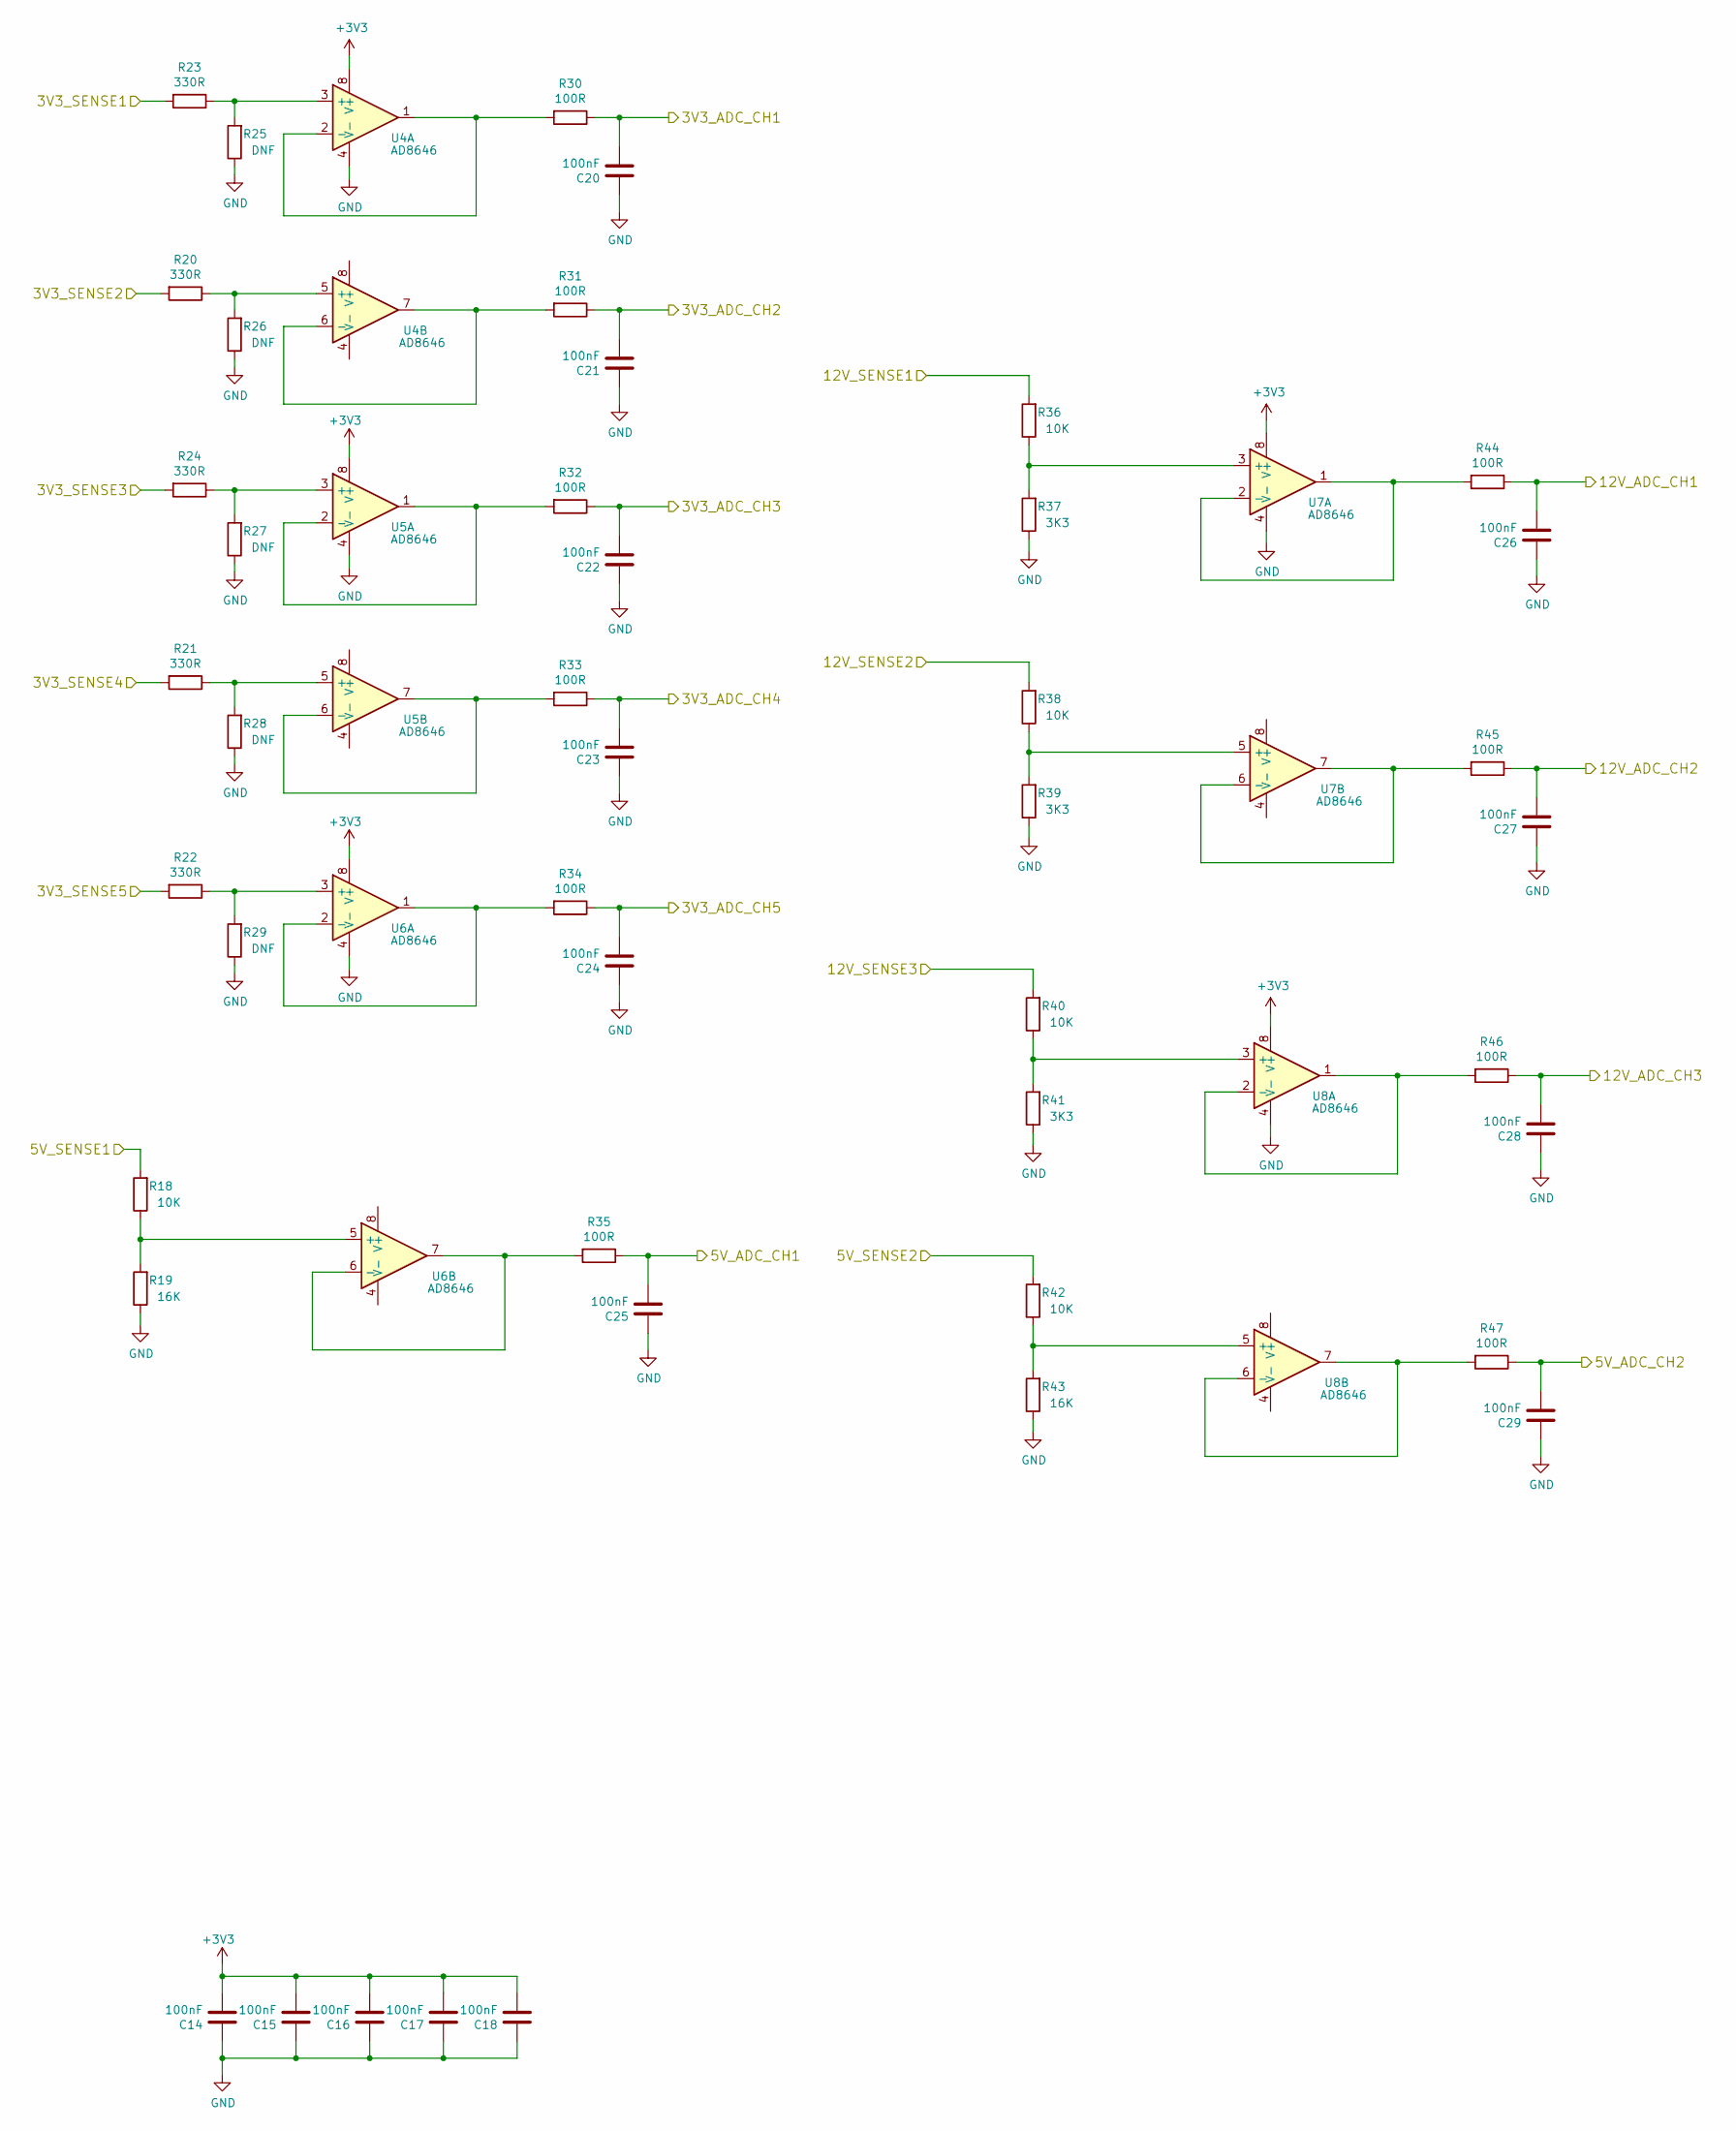
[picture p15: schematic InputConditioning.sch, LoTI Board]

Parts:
C14, C15, C16, C17, C18, C20, C21, C22, C23, C24, C25, C26, C27, C28, C29: 100nF; C_0603_1608Metric
R18, R36, R38, R40, R42: 10K; R_0603_1608Metric
R19, R43: 16K; R_0603_1608Metric
R20, R21, R22, R23, R24: 330R; R_0603_1608Metric
R25, R26, R27, R28, R29: DNF; R_0603_1608Metric
R30, R31, R32, R33, R34, R35, R44, R45, R46, R47: 100R; R_0603_1608Metric
R37, R39, R41: 3K3; R_0603_1608Metric
U4, U5, U6, U7, U8: AD8646; SOIC-8_3.9x4.9mm_P1.27mm

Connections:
+3V3: C14.2, C15.2, C16.2, C17.2, C18.2, U4.8 (V+), U5.8 (V+), U6.8 (V+), U7.8 (V+), U8.8 (V+); also elsewhere on the board
/3V3_ADC1: R23.2; also elsewhere on the board
/3V3_ADC2: R20.2; also elsewhere on the board
/3V3_ADC3: R24.2; also elsewhere on the board
/3V3_ADC4: R21.2; also elsewhere on the board
/3V3_ADC5: R22.2; also elsewhere on the board
/5V_ADC6: R18.2; also elsewhere on the board
/5V_ADC7: R42.2; also elsewhere on the board
/12V_ADC8: R36.2; also elsewhere on the board
/12V_ADC9: R38.2; also elsewhere on the board
/12V_ADC10: R40.2; also elsewhere on the board
/ADC0: C20.2, R30.1; also elsewhere on the board
/ADC1: C21.2, R31.1; also elsewhere on the board
/ADC2: C22.2, R32.1; also elsewhere on the board
/ADC3: C23.2, R33.1; also elsewhere on the board
/ADC4: C24.2, R34.1; also elsewhere on the board
/ADC5_OPT: C25.2, R35.1; also elsewhere on the board
/ADC6: C29.2, R47.1; also elsewhere on the board
/ADC7: C26.2, R44.1; also elsewhere on the board
/ADC8: C27.2, R45.1; also elsewhere on the board
/ADC9: C28.2, R46.1; also elsewhere on the board
GND: C14.1, C15.1, C16.1, C17.1, C18.1, C20.1, C21.1, C22.1, C23.1, C24.1, C25.1, C26.1, C27.1, C28.1, C29.1, R19.1, R25.1, R26.1, R27.1, R28.1, R29.1, R37.1, R39.1, R41.1, R43.1, U4.4 (V-), U5.4 (V-), U6.4 (V-), U7.4 (V-), U8.4 (V-); also elsewhere on the board
unnamed: R18.1, R19.2, U6.5 (+)
unnamed: R20.1, R26.2, U4.5 (+)
unnamed: R21.1, R28.2, U5.5 (+)
unnamed: R22.1, R29.2, U6.3 (+)
unnamed: R23.1, R25.2, U4.3 (+)
unnamed: R24.1, R27.2, U5.3 (+)
unnamed: R30.2, U4.1, U4.2 (-)
unnamed: R31.2, U4.6 (-), U4.7
unnamed: R32.2, U5.1, U5.2 (-)
unnamed: R33.2, U5.6 (-), U5.7
unnamed: R34.2, U6.1, U6.2 (-)
unnamed: R35.2, U6.6 (-), U6.7
unnamed: R36.1, R37.2, U7.3 (+)
unnamed: R38.1, R39.2, U7.5 (+)
unnamed: R40.1, R41.2, U8.3 (+)
unnamed: R42.1, R43.2, U8.5 (+)
unnamed: R44.2, U7.1, U7.2 (-)
unnamed: R45.2, U7.6 (-), U7.7
unnamed: R46.2, U8.1, U8.2 (-)
unnamed: R47.2, U8.6 (-), U8.7

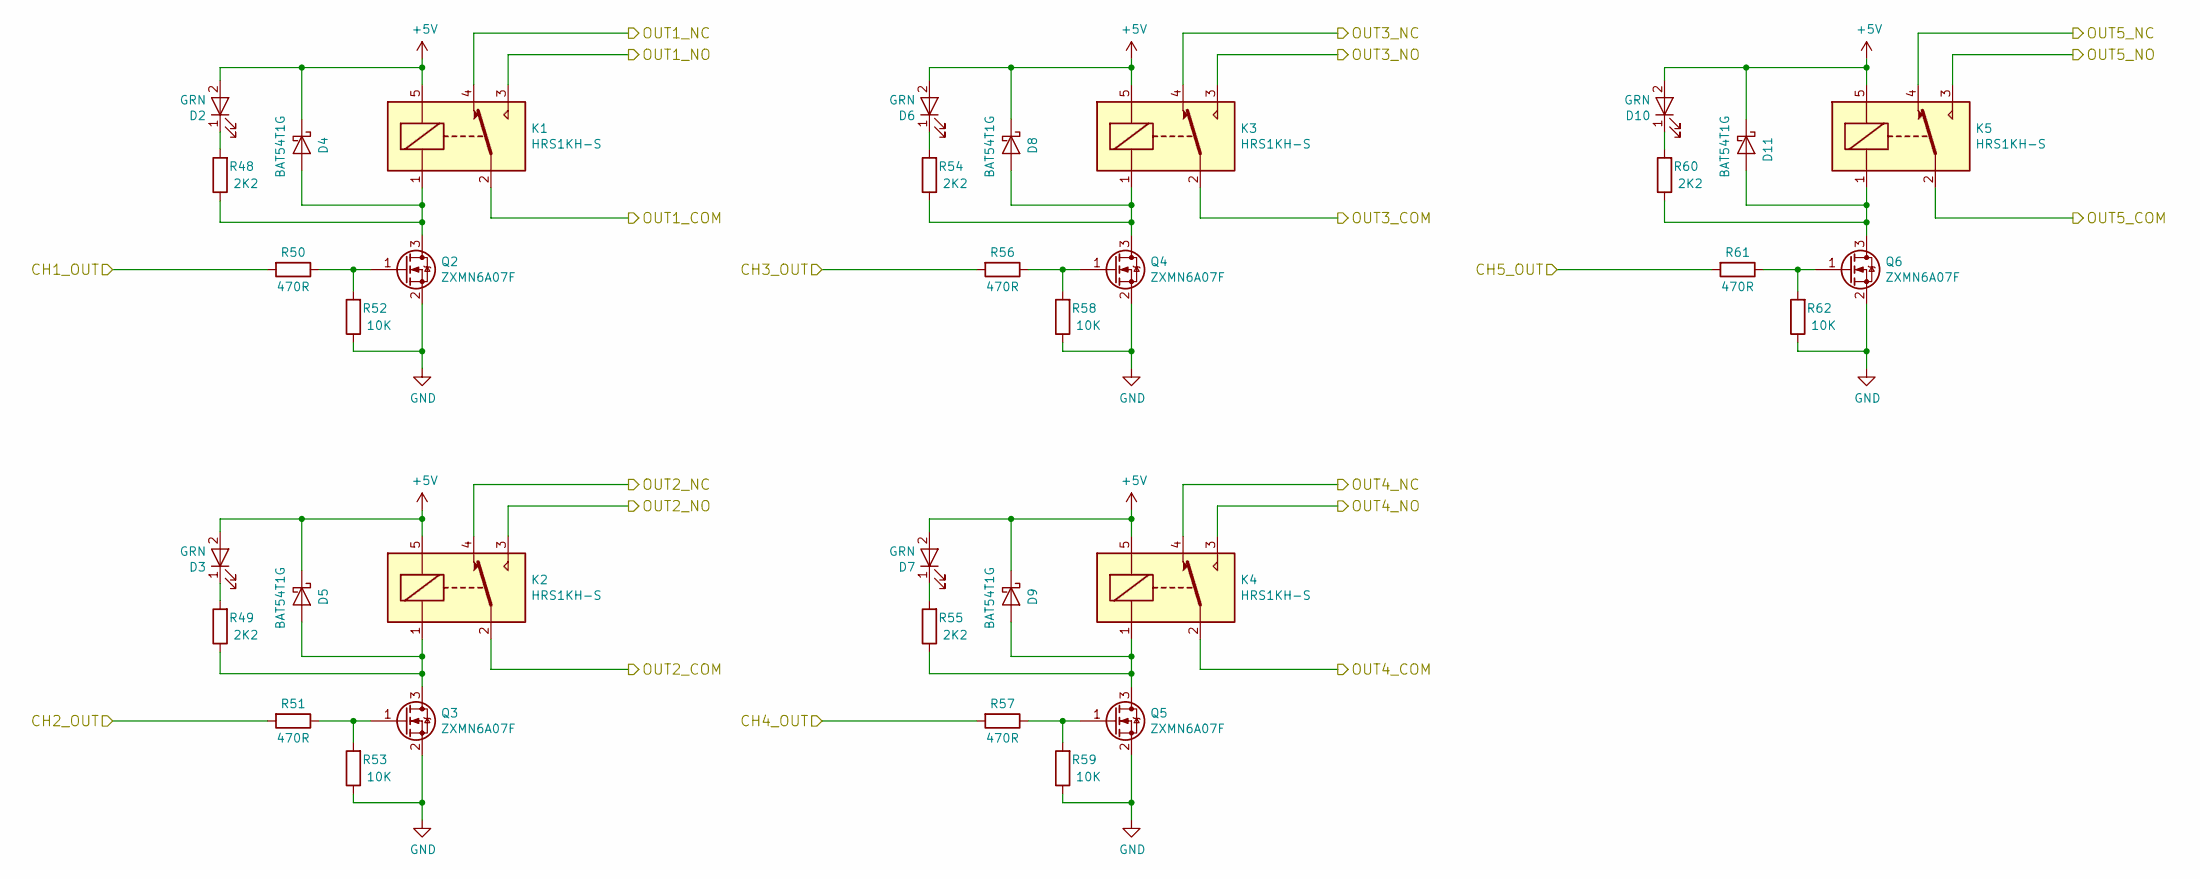
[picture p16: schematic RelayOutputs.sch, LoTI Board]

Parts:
D2, D3, D6, D7, D10: GRN; LED_0603_1608Metric
D4, D5, D8, D9, D11: BAT54T1G; D_SOD-123
K1, K2, K3, K4, K5: HRS1KH-S; Relay_SPDT_HRS1KH-S
Q2, Q3, Q4, Q5, Q6: ZXMN6A07F; SOT-23
R48, R49, R54, R55, R60: 2K2; R_0603_1608Metric
R50, R51, R56, R57, R61: 470R; R_0603_1608Metric
R52, R53, R58, R59, R62: 10K; R_0603_1608Metric

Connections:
+5V: D2.2 (A), D3.2 (A), D4.1 (K), D5.1 (K), D6.2 (A), D7.2 (A), D8.1 (K), D9.1 (K), D10.2 (A), D11.1 (K), K1.5, K2.5, K3.5, K4.5, K5.5; also elsewhere on the board
+12V_EXT: K1.3; also elsewhere on the board
/OUT1_COM: K1.2; also elsewhere on the board
/OUT1_NC: K1.4; also elsewhere on the board
/OUT2_COM: K2.2; also elsewhere on the board
/OUT2_NC: K2.4; also elsewhere on the board
/OUT2_NO: K2.3; also elsewhere on the board
/OUT3_COM: K3.2; also elsewhere on the board
/OUT3_NC: K3.4; also elsewhere on the board
/OUT3_NO: K3.3; also elsewhere on the board
/OUT4_COM: K4.2; also elsewhere on the board
/OUT4_NC: K4.4; also elsewhere on the board
/OUT4_NO: K4.3; also elsewhere on the board
/OUT5_COM: K5.2; also elsewhere on the board
/OUT5_NC: K5.4; also elsewhere on the board
/OUT5_NO: K5.3; also elsewhere on the board
/RL1_OUT: R50.2; also elsewhere on the board
/RL2_OUT: R51.2; also elsewhere on the board
/RL3_OUT: R56.2; also elsewhere on the board
/RL4_OUT: R57.2; also elsewhere on the board
/RL5_OUT: R61.2; also elsewhere on the board
GND: Q2.2 (S), Q3.2 (S), Q4.2 (S), Q5.2 (S), Q6.2 (S), R52.1, R53.1, R58.1, R59.1, R62.1; also elsewhere on the board
unnamed: D2.1 (K), R48.2
unnamed: D3.1 (K), R49.2
unnamed: D4.2 (A), K1.1, Q2.3 (D), R48.1
unnamed: D5.2 (A), K2.1, Q3.3 (D), R49.1
unnamed: D6.1 (K), R54.2
unnamed: D7.1 (K), R55.2
unnamed: D8.2 (A), K3.1, Q4.3 (D), R54.1
unnamed: D9.2 (A), K4.1, Q5.3 (D), R55.1
unnamed: D10.1 (K), R60.2
unnamed: D11.2 (A), K5.1, Q6.3 (D), R60.1
unnamed: Q2.1 (G), R50.1, R52.2
unnamed: Q3.1 (G), R51.1, R53.2
unnamed: Q4.1 (G), R56.1, R58.2
unnamed: Q5.1 (G), R57.1, R59.2
unnamed: Q6.1 (G), R61.1, R62.2

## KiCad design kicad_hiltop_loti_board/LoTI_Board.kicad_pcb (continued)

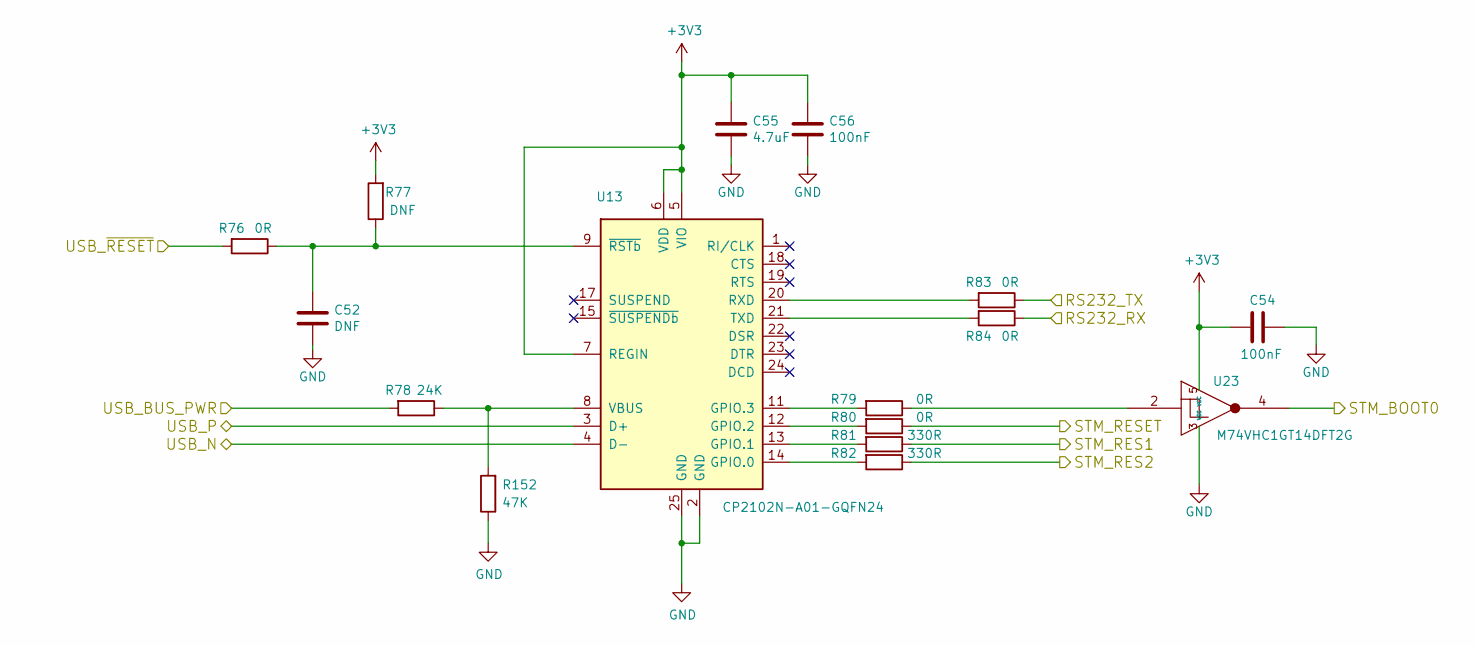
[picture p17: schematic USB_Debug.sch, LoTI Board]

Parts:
C52: DNF; C_0603_1608Metric
C54, C56: 100nF; C_0603_1608Metric
C55: 4.7uF; C_0805_2012Metric
R76, R79, R80, R83, R84: 0R; R_0603_1608Metric
R77: DNF; R_0603_1608Metric
R78: 24K; R_0603_1608Metric
R81, R82: 330R; R_0603_1608Metric
R152: 47K; R_0603_1608Metric
U13: CP2102N-A01-GQFN24; QFN-24-1EP_4x4mm_P0.5mm_EP2.6x2.6mm_ThermalVias
U23: M74VHC1GT14DFT2G; SOT-353_SC-70-5

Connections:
+3V3: C54.2, C55.1, C56.1, R77.2, U13.5 (VIO), U13.6 (VDD), U13.7 (REGIN), U23.5 (VCC); also elsewhere on the board
+5V: R78.2; also elsewhere on the board
/RESET: R76.2; also elsewhere on the board
/STM_BOOT0: U23.4; also elsewhere on the board
/STM_DEBUG_RX: R84.1; also elsewhere on the board
/STM_DEBUG_TX: R83.1; also elsewhere on the board
/STM_RES1: R81.1; also elsewhere on the board
/STM_RES2: R82.1; also elsewhere on the board
/STM_RESET: R80.1; also elsewhere on the board
/USB_DEBUG_N: U13.4 (D-); also elsewhere on the board
/USB_DEBUG_P: U13.3 (D+); also elsewhere on the board
GND: C52.2, C54.1, C55.2, C56.2, R152.1, U13.2 (GND), U13.25 (GND), U23.3 (VSS); also elsewhere on the board
unnamed: C52.1, R76.1, R77.1, U13.9 (~RSTb)
unnamed: R79.1, U23.2
unnamed: R79.2, U13.11 (GPIO.3)
unnamed: R80.2, U13.12 (GPIO.2)
unnamed: R81.2, U13.13 (GPIO.1)
unnamed: R82.2, U13.14 (GPIO.0)
unnamed: R83.2, U13.20 (RXD)
unnamed: R84.2, U13.21 (TXD)
unnamed: R78.1, R152.2, U13.8 (VBUS)

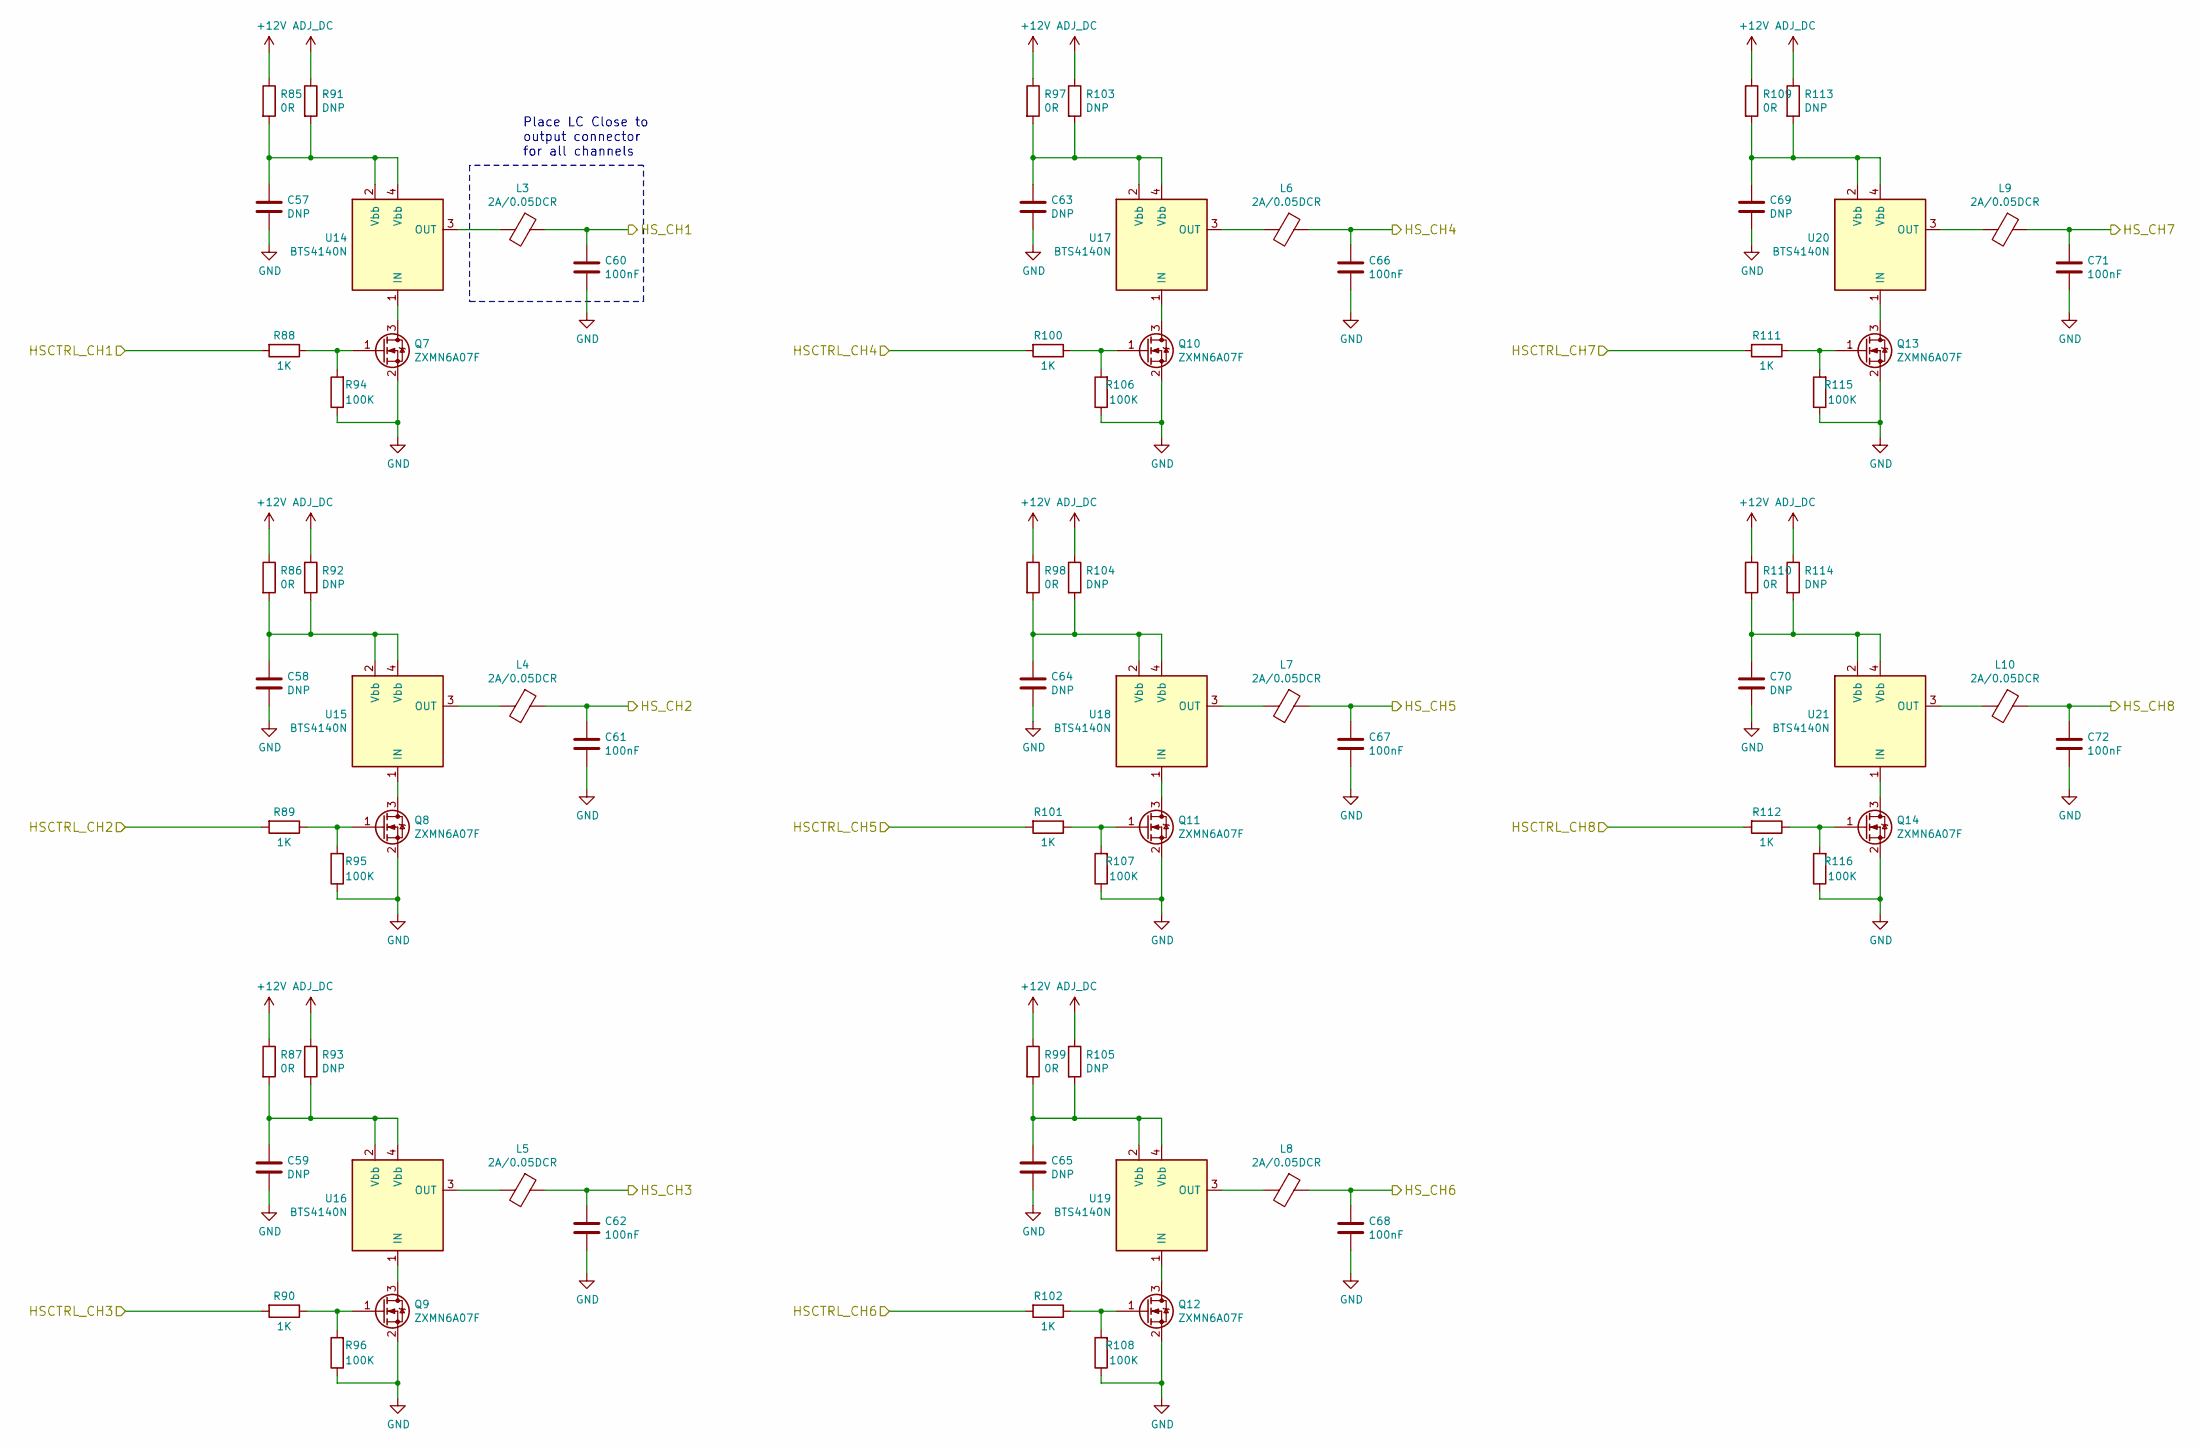
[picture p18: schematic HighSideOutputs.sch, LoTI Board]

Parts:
C57, C58, C59, C63, C64, C65, C69, C70: DNP; C_0805_2012Metric
C60, C61, C62, C66, C67, C68, C71, C72: 100nF; C_0402_1005Metric
L3, L4, L5, L6, L7, L8, L9, L10: 2A/0.05DCR; L_0805_2012Metric
Q7, Q8, Q9, Q10, Q11, Q12, Q13, Q14: ZXMN6A07F; SOT-23
R85, R86, R87, R97, R98, R99, R109, R110: 0R; R_0805_2012Metric
R88, R89, R90, R100, R101, R102, R111, R112: 1K; R_0603_1608Metric
R91, R92, R93, R103, R104, R105, R113, R114: DNP; R_0805_2012Metric
R94, R95, R96, R106, R107, R108, R115, R116: 100K; R_0603_1608Metric
U14, U15, U16, U17, U18, U19, U20, U21: BTS4140N; SOT-223

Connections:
+12V: R85.1, R86.1, R87.1, R97.1, R98.1, R99.1, R109.1, R110.1; also elsewhere on the board
/HS_CTRL_SW1: R88.2; also elsewhere on the board
/HS_CTRL_SW2: R89.2; also elsewhere on the board
/HS_CTRL_SW3: R90.2; also elsewhere on the board
/HS_CTRL_SW4: R100.2; also elsewhere on the board
/HS_CTRL_SW5: R101.2; also elsewhere on the board
/HS_CTRL_SW6: R102.2; also elsewhere on the board
/HS_CTRL_SW7: R111.2; also elsewhere on the board
/HS_CTRL_SW8: R112.2; also elsewhere on the board
/HS_OUT1: C60.1, L3.1; also elsewhere on the board
/HS_OUT2: C61.1, L4.1; also elsewhere on the board
/HS_OUT3: C62.1, L5.1; also elsewhere on the board
/HS_OUT4: C66.1, L6.1; also elsewhere on the board
/HS_OUT5: C67.1, L7.1; also elsewhere on the board
/HS_OUT6: C68.1, L8.1; also elsewhere on the board
/HS_OUT7: C71.1, L9.1; also elsewhere on the board
/HS_OUT8: C72.1, L10.1; also elsewhere on the board
ADJ_DC: R91.1, R92.1, R93.1, R103.1, R104.1, R105.1, R113.1, R114.1; also elsewhere on the board
GND: C57.2, C58.2, C59.2, C60.2, C61.2, C62.2, C63.2, C64.2, C65.2, C66.2, C67.2, C68.2, C69.2, C70.2, C71.2, C72.2, Q7.2 (S), Q8.2 (S), Q9.2 (S), Q10.2 (S), Q11.2 (S), Q12.2 (S), Q13.2 (S), Q14.2 (S), R94.1, R95.1, R96.1, R106.1, R107.1, R108.1, R115.1, R116.1; also elsewhere on the board
unnamed: C57.1, R85.2, R91.2, U14.2 (Vbb), U14.4 (Vbb)
unnamed: C58.1, R86.2, R92.2, U15.2 (Vbb), U15.4 (Vbb)
unnamed: C59.1, R87.2, R93.2, U16.2 (Vbb), U16.4 (Vbb)
unnamed: C63.1, R97.2, R103.2, U17.2 (Vbb), U17.4 (Vbb)
unnamed: C64.1, R98.2, R104.2, U18.2 (Vbb), U18.4 (Vbb)
unnamed: C65.1, R99.2, R105.2, U19.2 (Vbb), U19.4 (Vbb)
unnamed: C69.1, R109.2, R113.2, U20.2 (Vbb), U20.4 (Vbb)
unnamed: C70.1, R110.2, R114.2, U21.2 (Vbb), U21.4 (Vbb)
unnamed: L3.2, U14.3 (OUT)
unnamed: L4.2, U15.3 (OUT)
unnamed: L5.2, U16.3 (OUT)
unnamed: L6.2, U17.3 (OUT)
unnamed: L7.2, U18.3 (OUT)
unnamed: L8.2, U19.3 (OUT)
unnamed: L9.2, U20.3 (OUT)
unnamed: L10.2, U21.3 (OUT)
unnamed: Q7.1 (G), R88.1, R94.2
unnamed: Q7.3 (D), U14.1 (IN)
unnamed: Q8.1 (G), R89.1, R95.2
unnamed: Q8.3 (D), U15.1 (IN)
unnamed: Q9.1 (G), R90.1, R96.2
unnamed: Q9.3 (D), U16.1 (IN)
unnamed: Q10.1 (G), R100.1, R106.2
unnamed: Q10.3 (D), U17.1 (IN)
unnamed: Q11.1 (G), R101.1, R107.2
unnamed: Q11.3 (D), U18.1 (IN)
unnamed: Q12.1 (G), R102.1, R108.2
unnamed: Q12.3 (D), U19.1 (IN)
unnamed: Q13.1 (G), R111.1, R115.2
unnamed: Q13.3 (D), U20.1 (IN)
unnamed: Q14.1 (G), R112.1, R116.2
unnamed: Q14.3 (D), U21.1 (IN)

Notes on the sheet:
Place LC Close to output connector for all channels

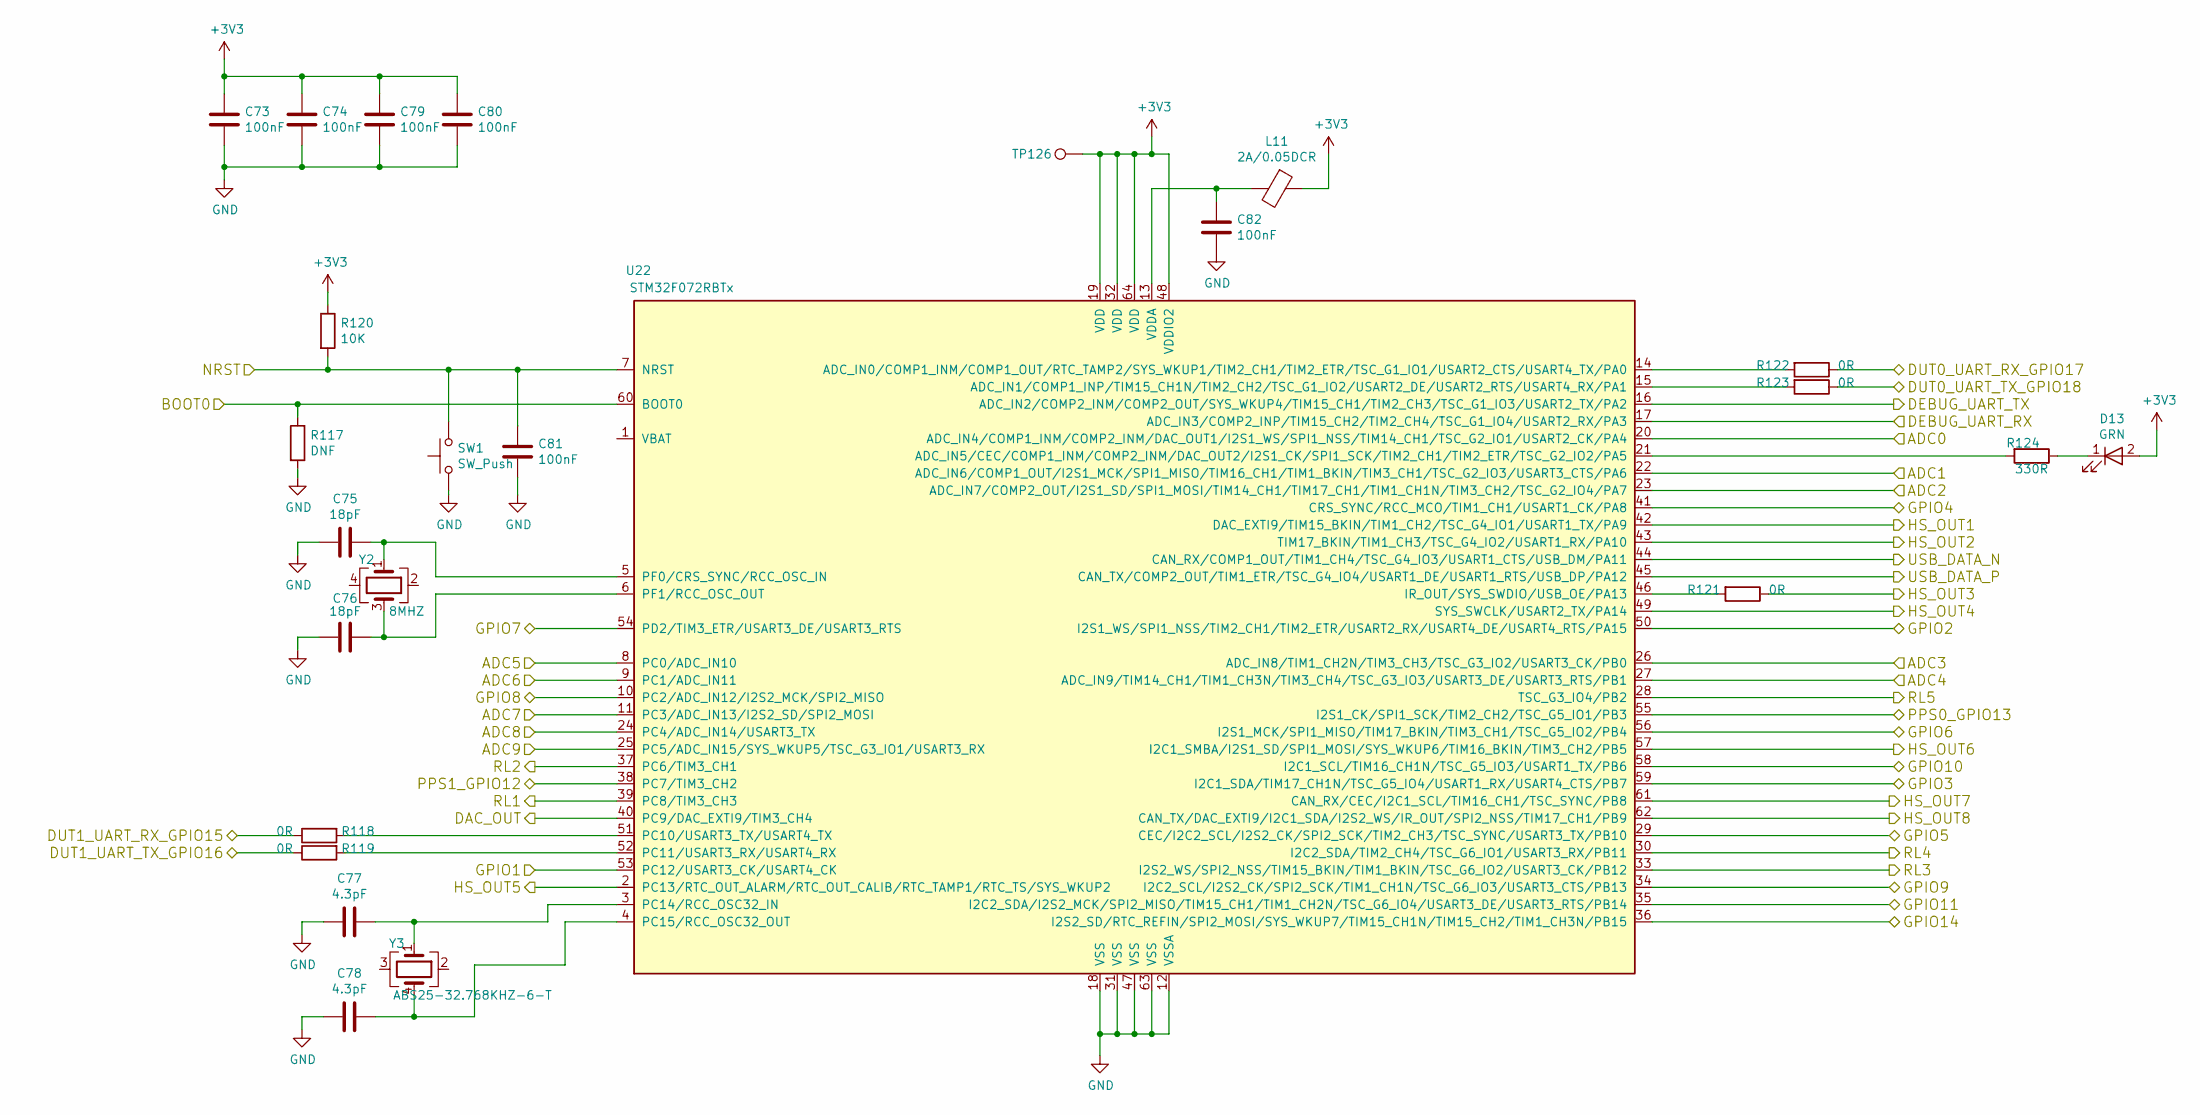
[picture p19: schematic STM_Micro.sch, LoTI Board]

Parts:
C73, C74, C79, C80, C81, C82: 100nF; C_0603_1608Metric
C75, C76: 18pF; C_0603_1608Metric
C77, C78: 4.3pF; C_0603_1608Metric
D13: GRN; LED_0603_1608Metric
L11: 2A/0.05DCR; L_0805_2012Metric
R117: DNF; R_0603_1608Metric
R118, R119, R121, R122, R123: 0R; R_0603_1608Metric
R120: 10K; R_0603_1608Metric
R124: 330R; R_0603_1608Metric
SW1: SW_Push; SW_SPST_B3U-1000P
TP126: Test_Point; TestPoint_THTPad_D1.0mm_Drill0.5mm
U22: STM32F072RBTx; LQFP-64_10x10mm_P0.5mm
Y2: 8MHZ; Crystal_SMD_Abracon_ABM3C-4Pin_5.0x3.2mm
Y3: ABS25-32.768KHZ-6-T; Crystal_SMD_7050-4Pin_7.0x5.0mm

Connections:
+3V3: C73.1, C74.1, C79.1, C80.1, D13.2 (A), L11.1, R120.1, TP126.1, U22.19 (VDD), U22.32 (VDD), U22.48 (VDDIO2), U22.64 (VDD); also elsewhere on the board
/ADC0: U22.20 (ADC_IN4/COMP1_INM/COMP2_INM/DAC_OUT1/I2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); also elsewhere on the board
/ADC1: U22.22 (ADC_IN6/COMP1_OUT/I2S1_MCK/SPI1_MISO/TI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); also elsewhere on the board
/ADC2: U22.23 (ADC_IN7/COMP2_OUT/I2S1_SD/SPI1_MOSI/TIM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); also elsewhere on the board
/ADC3: U22.26 (ADC_IN8/TIM1_CH2N/TIM3_CH3/TSC_G3_IO2/U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); also elsewhere on the board
/ADC4: U22.27 (ADC_IN9/TIM14_CH1/TIM1_CH3N/TIM3_CH4/TS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); also elsewhere on the board
/ADC5: U22.8 (PC0/ADC_IN10); also elsewhere on the board
/ADC6: U22.9 (PC1/ADC_IN11); also elsewhere on the board
/ADC7: U22.11 (PC3/ADC_IN13/I2S2_SD/SPI2_MOSI); also elsewhere on the board
/ADC8: U22.24 (PC4/ADC_IN14/USART3_TX); also elsewhere on the board
/ADC9: U22.25 (PC5/ADC_IN15/SYS_WKUP5/TSC_G3_IO1/USART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); also elsewhere on the board
/DUT0_UART_RX_GPIO17: R122.1; also elsewhere on the board
/DUT0_UART_TX_GPIO18: R123.1; also elsewhere on the board
/DUT1_UART_RX_GPIO15: R118.1; also elsewhere on the board
/DUT1_UART_TX_GPIO16: R119.1; also elsewhere on the board
/GPIO1: U22.53 (PC12/USART3_CK/USART4_CK); also elsewhere on the board
/GPIO2: U22.50 (I2S1_WS/SPI1_NSS/TIM2_CH1/TIM2_ETR/USAR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); also elsewhere on the board
/GPIO3: U22.59 (I2C1_SDA/TIM17_CH1N/TSC_G5_IO4/USART1_R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); also elsewhere on the board
/GPIO4: U22.41 (CRS_SYNC/RCC_MCO/TIM1_CH1/USART1_CK/PA8); also elsewhere on the board
/GPIO5: U22.29 (CEC/I2C2_SCL/I2S2_CK/SPI2_SCK/TIM2_CH3/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); also elsewhere on the board
/GPIO6: U22.56 (I2S1_MCK/SPI1_MISO/TIM17_BKIN/TIM3_CH1/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); also elsewhere on the board
/GPIO7: U22.54 (PD2/TIM3_ETR/USART3_DE/USART3_RTS); also elsewhere on the board
/GPIO8: U22.10 (PC2/ADC_IN12/I2S2_MCK/SPI2_MISO); also elsewhere on the board
/GPIO9: U22.34 (I2C2_SCL/I2S2_CK/SPI2_SCK/TIM1_CH1N/TSC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); also elsewhere on the board
/GPIO10: U22.58 (I2C1_SCL/TIM16_CH1N/TSC_G5_IO3/USART1_T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); also elsewhere on the board
/GPIO11: U22.35 (I2C2_SDA/I2S2_MCK/SPI2_MISO/TIM15_CH1/T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); also elsewhere on the board
/GPIO14: U22.36 (I2S2_SD/RTC_REFIN/SPI2_MOSI/SYS_WKUP7/T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); also elsewhere on the board
/HS_CTRL_SW1: U22.42 (DAC_EXTI9/TIM15_BKIN/TIM1_CH2/TSC_G4_IO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); also elsewhere on the board
/HS_CTRL_SW2: U22.43 (TIM17_BKIN/TIM1_CH3/TSC_G4_IO2/USART1_R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); also elsewhere on the board
/HS_CTRL_SW3: R121.1; also elsewhere on the board
/HS_CTRL_SW4: U22.49 (SYS_SWCLK/USART2_TX/PA14); also elsewhere on the board
/HS_CTRL_SW5: U22.2 (PC13/RTC_OUT_ALARM/RTC_OUT_CALIB/RTC_TA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); also elsewhere on the board
/HS_CTRL_SW6: U22.57 (I2C1_SMBA/I2S1_SD/SPI1_MOSI/SYS_WKUP6/T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); also elsewhere on the board
/HS_CTRL_SW7: U22.61 (CAN_RX/CEC/I2C1_SCL/TIM16_CH1/TSC_SYNC/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); also elsewhere on the board
/HS_CTRL_SW8: U22.62 (CAN_TX/DAC_EXTI9/I2C1_SDA/I2S2_WS/IR_OU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); also elsewhere on the board
/PPS0_GPIO13: U22.55 (I2S1_CK/SPI1_SCK/TIM2_CH2/TSC_G5_IO1/PB3); also elsewhere on the board
/PPS1_GPIO12: U22.38 (PC7/TIM3_CH2); also elsewhere on the board
/RL1_OUT: U22.39 (PC8/TIM3_CH3); also elsewhere on the board
/RL2_OUT: U22.37 (PC6/TIM3_CH1); also elsewhere on the board
/RL3_OUT: U22.33 (I2S2_WS/SPI2_NSS/TIM15_BKIN/TIM1_BKIN/T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); also elsewhere on the board
/RL4_OUT: U22.30 (I2C2_SDA/TIM2_CH4/TSC_G6_IO1/USART3_RX/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); also elsewhere on the board
/RL5_OUT: U22.28 (TSC_G3_IO4/PB2); also elsewhere on the board
/STM_BOOT0: R117.1, U22.60 (BOOT0); also elsewhere on the board
/STM_DEBUG_RX: U22.17 (ADC_IN3/COMP2_INP/TIM15_CH2/TIM2_CH4/TS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); also elsewhere on the board
/STM_DEBUG_TX: U22.16 (ADC_IN2/COMP2_INM/COMP2_OUT/SYS_WKUP4/T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); also elsewhere on the board
/STM_Micro/DAC_OUT: U22.40 (PC9/DAC_EXTI9/TIM3_CH4); also elsewhere on the board
/STM_RESET: C81.1, R120.2, SW1.2, U22.7 (NRST); also elsewhere on the board
/USB_DATA_N: U22.44 (CAN_RX/COMP1_OUT/TIM1_CH4/TSC_G4_IO3/US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); also elsewhere on the board
/USB_DATA_P: U22.45 (CAN_TX/COMP2_OUT/TIM1_ETR/TSC_G4_IO4/US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); also elsewhere on the board
GND: C73.2, C74.2, C75.2, C76.2, C77.2, C78.2, C79.2, C80.2, C81.2, C82.2, R117.2, SW1.1, U22.12 (VSSA), U22.18 (VSS), U22.31 (VSS), U22.47 (VSS), U22.63 (VSS); also elsewhere on the board
unnamed: C75.1, U22.5 (PF0/CRS_SYNC/RCC_OSC_IN), Y2.1
unnamed: C76.1, U22.6 (PF1/RCC_OSC_OUT), Y2.3
unnamed: C77.1, U22.3 (PC14/RCC_OSC32_IN), Y3.1
unnamed: C78.1, U22.4 (PC15/RCC_OSC32_OUT), Y3.4
unnamed: C82.1, L11.2, U22.13 (VDDA)
unnamed: D13.1 (K), R124.1
unnamed: R118.2, U22.51 (PC10/USART3_TX/USART4_TX)
unnamed: R119.2, U22.52 (PC11/USART3_RX/USART4_RX)
unnamed: R121.2, U22.46 (IR_OUT/SYS_SWDIO/USB_OE/PA13)
unnamed: R122.2, U22.14 (ADC_IN0/COMP1_INM/COMP1_OUT/RTC_TAMP2/S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)
unnamed: R123.2, U22.15 (ADC_IN1/COMP1_INP/TIM15_CH1N/TIM2_CH2/T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)
unnamed: R124.2, U22.21 (ADC_IN5/CEC/COMP1_INM/COMP2_INM/DAC_OUT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)

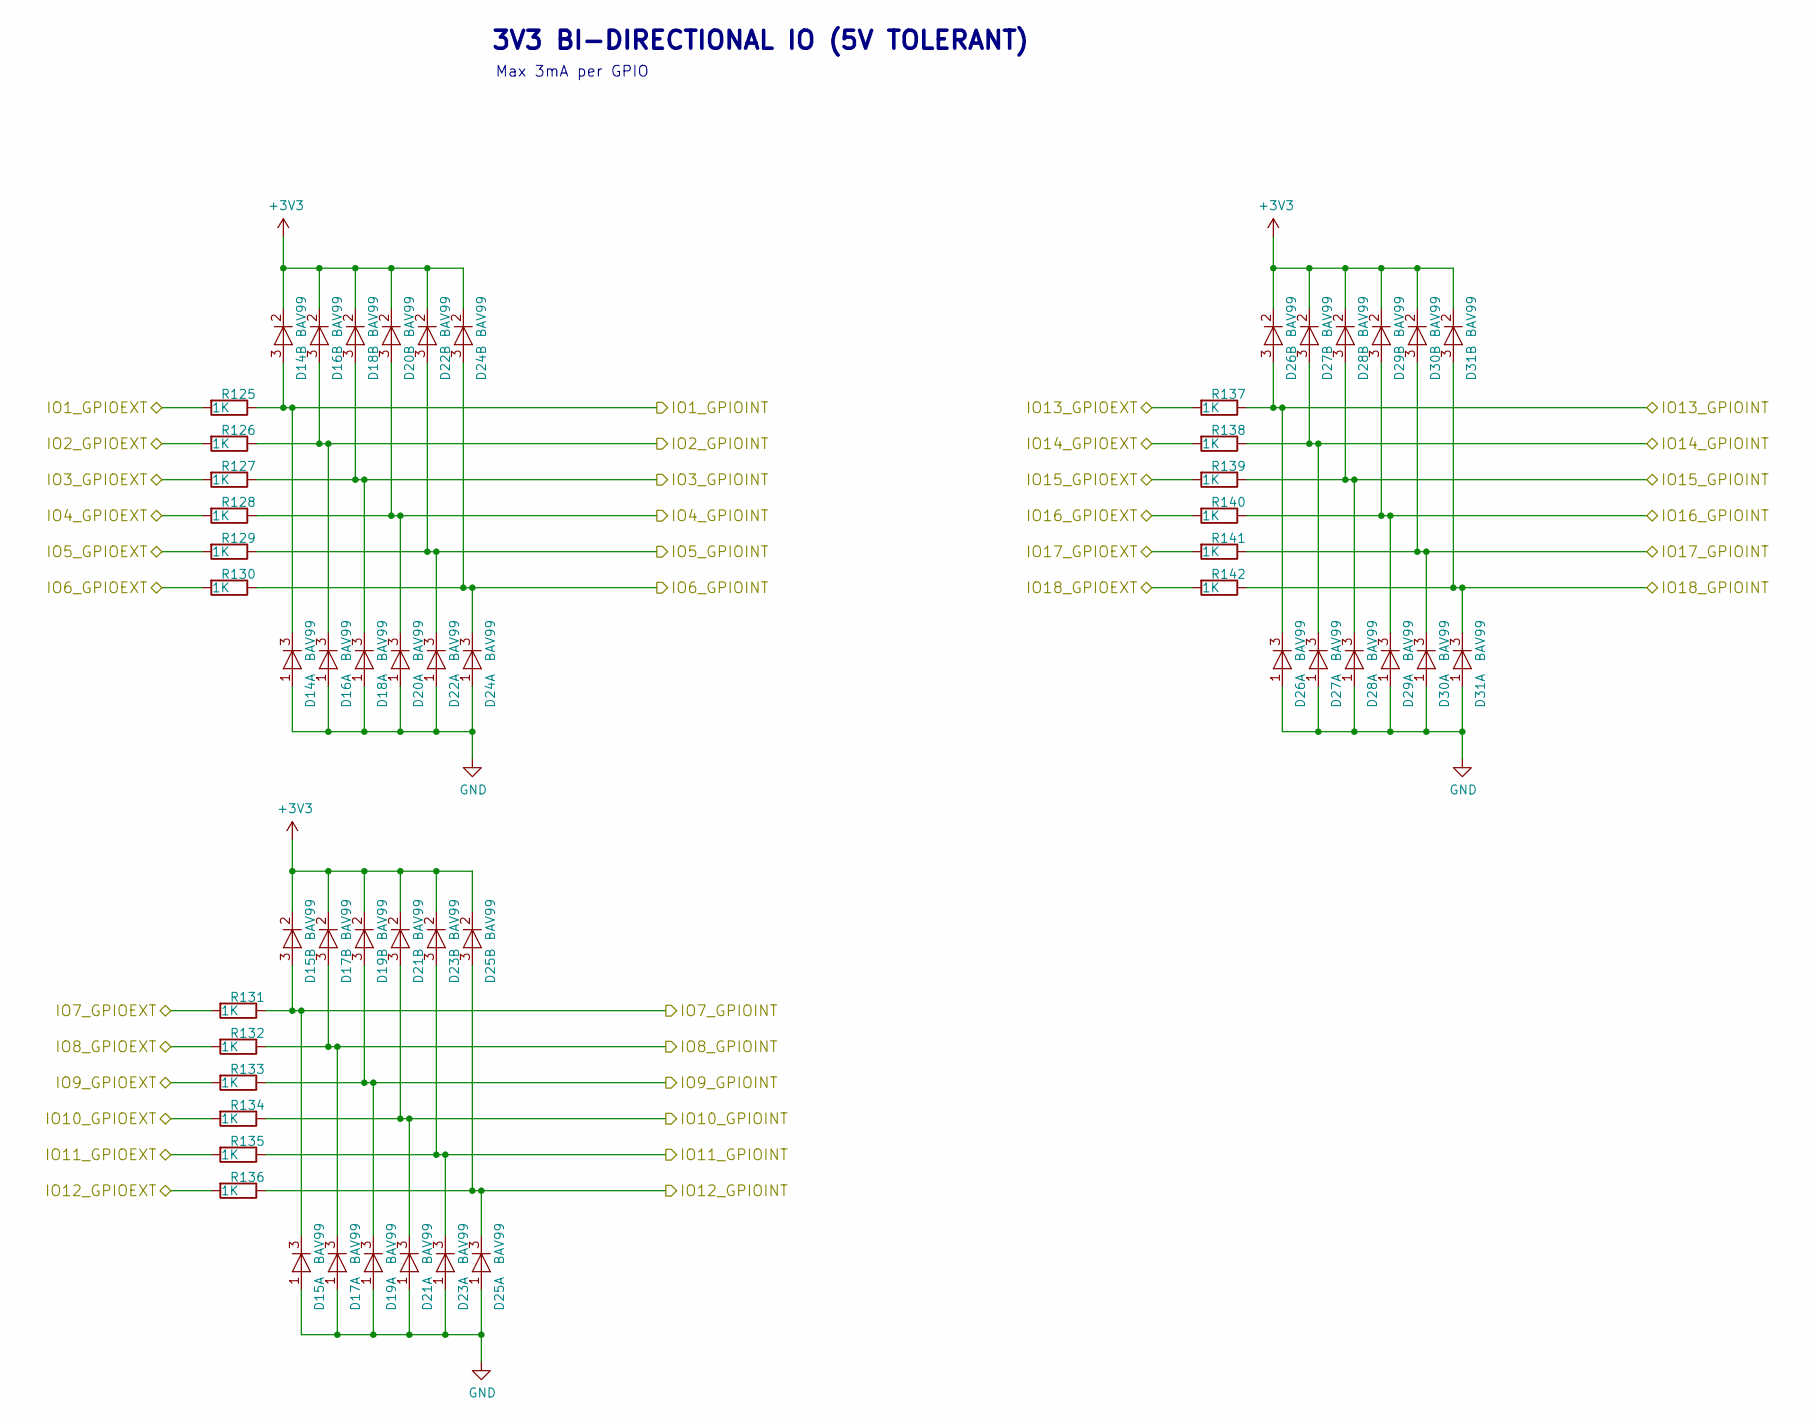
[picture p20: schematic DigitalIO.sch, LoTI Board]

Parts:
D14, D15, D16, D17, D18, D19, D20, D21, D22, D23, D24, D25, D26, D27, D28, D29, D30, D31: BAV99; SOT-23
R125, R126, R127, R128, R129, R130, R131, R132, R133, R134, R135, R136, R137, R138, R139, R140, R141, R142: 1K; R_0603_1608Metric

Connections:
+3V3: D14.2 (K), D15.2 (K), D16.2 (K), D17.2 (K), D18.2 (K), D19.2 (K), D20.2 (K), D21.2 (K), D22.2 (K), D23.2 (K), D24.2 (K), D25.2 (K), D26.2 (K), D27.2 (K), D28.2 (K), D29.2 (K), D30.2 (K), D31.2 (K); also elsewhere on the board
/DUT0_RX_GPIO17_EXT: R141.2; also elsewhere on the board
/DUT0_TX_GPIO18_EXT: R142.2; also elsewhere on the board
/DUT0_UART_RX_GPIO17: D30.3 (K), R141.1; also elsewhere on the board
/DUT0_UART_TX_GPIO18: D31.3 (K), R142.1; also elsewhere on the board
/DUT1_RX_GPIO15_EXT: R139.2; also elsewhere on the board
/DUT1_TX_GPIO16_EXT: R140.2; also elsewhere on the board
/DUT1_UART_RX_GPIO15: D28.3 (K), R139.1; also elsewhere on the board
/DUT1_UART_TX_GPIO16: D29.3 (K), R140.1; also elsewhere on the board
/GPIO1: D14.3 (K), R125.1; also elsewhere on the board
/GPIO1_EXT: R125.2; also elsewhere on the board
/GPIO2: D16.3 (K), R126.1; also elsewhere on the board
/GPIO2_EXT: R126.2; also elsewhere on the board
/GPIO3: D18.3 (K), R127.1; also elsewhere on the board
/GPIO3_EXT: R127.2; also elsewhere on the board
/GPIO4: D20.3 (K), R128.1; also elsewhere on the board
/GPIO4_EXT: R128.2; also elsewhere on the board
/GPIO5: D22.3 (K), R129.1; also elsewhere on the board
/GPIO5_EXT: R129.2; also elsewhere on the board
/GPIO6: D24.3 (K), R130.1; also elsewhere on the board
/GPIO6_EXT: R130.2; also elsewhere on the board
/GPIO7: D15.3 (K), R131.1; also elsewhere on the board
/GPIO7_EXT: R131.2; also elsewhere on the board
/GPIO8: D17.3 (K), R132.1; also elsewhere on the board
/GPIO8_EXT: R132.2; also elsewhere on the board
/GPIO9: D19.3 (K), R133.1; also elsewhere on the board
/GPIO9_EXT: R133.2; also elsewhere on the board
/GPIO10: D21.3 (K), R134.1; also elsewhere on the board
/GPIO10_EXT: R134.2; also elsewhere on the board
/GPIO11: D23.3 (K), R135.1; also elsewhere on the board
/GPIO11_EXT: R135.2; also elsewhere on the board
/GPIO14: D27.3 (K), R138.1; also elsewhere on the board
/GPIO14_EXT: R138.2; also elsewhere on the board
/PPS0_GPIO13: D26.3 (K), R137.1; also elsewhere on the board
/PPS0_GPIO13_EXT: R137.2; also elsewhere on the board
/PPS1_GPIO12: D25.3 (K), R136.1; also elsewhere on the board
/PPS1_GPIO12_EXT: R136.2; also elsewhere on the board
GND: D14.1 (A), D15.1 (A), D16.1 (A), D17.1 (A), D18.1 (A), D19.1 (A), D20.1 (A), D21.1 (A), D22.1 (A), D23.1 (A), D24.1 (A), D25.1 (A), D26.1 (A), D27.1 (A), D28.1 (A), D29.1 (A), D30.1 (A), D31.1 (A); also elsewhere on the board

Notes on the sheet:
3V3 BI-DIRECTIONAL IO (5V TOLERANT)
Max 3mA per GPIO

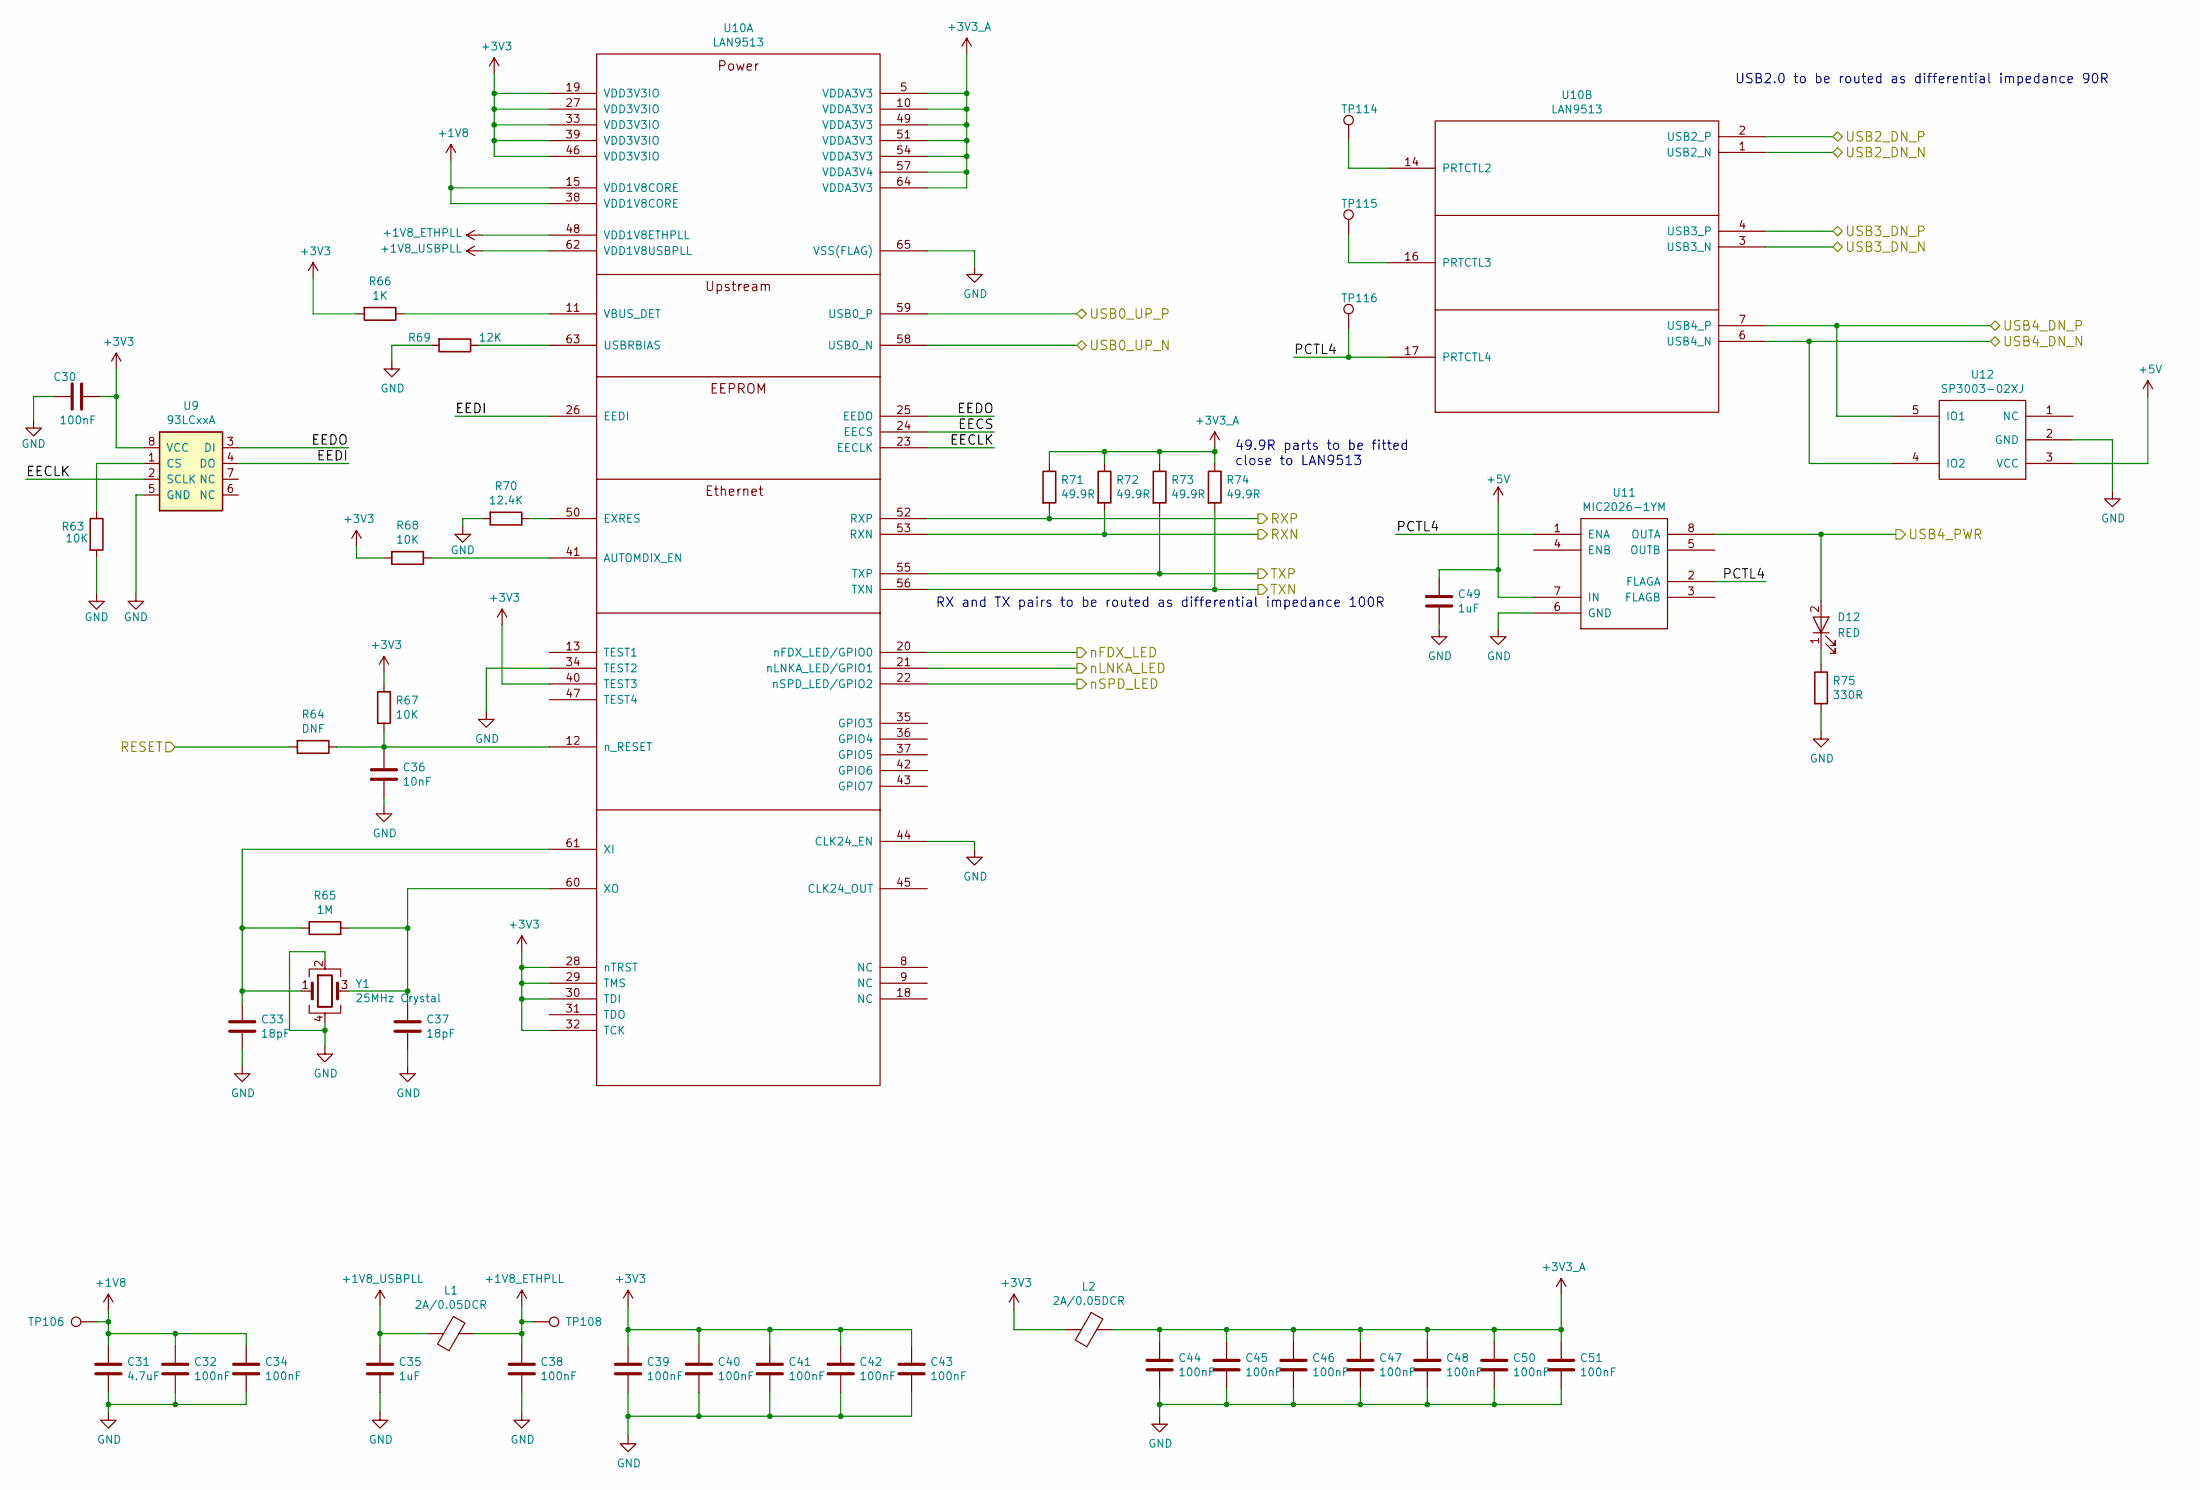
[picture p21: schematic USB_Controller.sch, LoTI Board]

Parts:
C30, C32, C34, C39, C40, C41, C42, C43, C44, C45, C46, C47, C48, C50, C51: 100nF; C_0402_1005Metric
C31: 4.7uF; C_0603_1608Metric
C33, C37: 18pF; C_0402_1005Metric
C35, C49: 1uF; C_0603_1608Metric
C36: 10nF; C_0402_1005Metric
C38: 100nF; C_0603_1608Metric
D12: RED; LED_0402_1005Metric
L1, L2: 2A/0.05DCR; L_0805_2012Metric
R63: 10K; R_0603_1608Metric
R64: DNF; R_0603_1608Metric
R65: 1M; R_0402_1005Metric
R66: 1K; R_0402_1005Metric
R67, R68: 10K; R_0402_1005Metric
R69: 12K; R_0402_1005Metric
R70: 12.4K; R_0402_1005Metric
R71, R72, R73, R74: 49.9R; R_0402_1005Metric
R75: 330R; R_0603_1608Metric
TP106, TP108, TP114, TP115, TP116: Test_Point; TestPoint_THTPad_D1.0mm_Drill0.5mm
U9: 93LCxxA; SOIC-8_3.9x4.9mm_P1.27mm
U10: LAN9513; QFN-64-1EP_9x9mm_P0.5mm_EP7.3x7.3mm_ThermalVias
U11: MIC2026-1YM; SOIC-8_3.9x4.9mm_P1.27mm
U12: SP3003-02XJ; SC70-5
Y1: 25MHz Crystal; Crystal_SMD_SeikoEpson_FA238V-4Pin_3.2x2.5mm

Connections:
+1V8: C31.1, C32.1, C34.1, TP106.1, U10.15 (VDD1V8CORE), U10.38 (VDD1V8CORE)
+1V8_ETHPLL: C38.1, L1.1, TP108.1, U10.48 (VDD1V8ETHPLL)
+1V8_USBPLL: C35.1, L1.2, U10.62 (VDD1V8USBPLL)
+3V3: C30.2, C39.1, C40.1, C41.1, C42.1, C43.1, L2.2, R66.2, R67.1, R68.2, U9.8 (VCC), U10.19 (VDD3V3IO), U10.27 (VDD3V3IO), U10.28 (nTRST), U10.29 (TMS), U10.30 (TDI), U10.32 (TCK), U10.33 (VDD3V3IO), U10.39 (VDD3V3IO), U10.40 (TEST3), U10.46 (VDD3V3IO); also elsewhere on the board
+3V3_A: C44.1, C45.1, C46.1, C47.1, C48.1, C50.1, C51.1, L2.1, R71.1, R72.1, R73.1, R74.1, U10.5 (VDDA3V3), U10.10 (VDDA3V3), U10.49 (VDDA3V3), U10.51 (VDDA3V3), U10.54 (VDDA3V3), U10.57 (VDDA3V4), U10.64 (VDDA3V3); also elsewhere on the board
+5V: C49.1, U11.7 (IN), U12.3 (VCC); also elsewhere on the board
/RESET: R64.2; also elsewhere on the board
/RXN: R72.2, U10.53 (RXN); also elsewhere on the board
/RXP: R71.2, U10.52 (RXP); also elsewhere on the board
/TXN: R74.2, U10.56 (TXN); also elsewhere on the board
/TXP: R73.2, U10.55 (TXP); also elsewhere on the board
/USB_AUX_N: U10.6 (USB4_N), U12.4 (IO2); also elsewhere on the board
/USB_AUX_P: U10.7 (USB4_P), U12.5 (IO1); also elsewhere on the board
/USB_AUX_PWR: D12.2 (A), U11.8 (OUTA); also elsewhere on the board
/USB_Controller/EECLK: U9.2 (SCLK), U10.23 (EECLK)
/USB_Controller/EECS: U10.24 (EECS)
/USB_Controller/EEDI: U9.4 (DO), U10.26 (EEDI)
/USB_Controller/EEDO: U9.3 (DI), U10.25 (EEDO)
/USB_Controller/PCTL4: TP116.1, U10.17 (PRTCTL4), U11.1 (ENA), U11.2 (FLAGA)
/USB_DATA_N: U10.1 (USB2_N); also elsewhere on the board
/USB_DATA_P: U10.2 (USB2_P); also elsewhere on the board
/USB_DEBUG_N: U10.3 (USB3_N); also elsewhere on the board
/USB_DEBUG_P: U10.4 (USB3_P); also elsewhere on the board
/USB_ROOT_N: U10.58 (USB0_N); also elsewhere on the board
/USB_ROOT_P: U10.59 (USB0_P); also elsewhere on the board
/nFDX_LED: U10.20 (nFDX_LED/GPIO0); also elsewhere on the board
/nLNKA_LED: U10.21 (nLNKA_LED/GPIO1); also elsewhere on the board
/nSPD_LED: U10.22 (nSPD_LED/GPIO2); also elsewhere on the board
GND: C30.1, C31.2, C32.2, C33.2, C34.2, C35.2, C36.2, C37.2, C38.2, C39.2, C40.2, C41.2, C42.2, C43.2, C44.2, C45.2, C46.2, C47.2, C48.2, C49.2, C50.2, C51.2, R63.2, R69.2, R70.2, R75.2, U9.5 (GND), U10.34 (TEST2), U10.44 (CLK24_EN), U10.65 (VSS(FLAG)), U11.6 (GND), U12.2 (GND), Y1.2, Y1.4; also elsewhere on the board
unnamed: C33.1, R65.1, U10.61 (XI), Y1.1
unnamed: C36.1, R64.1, R67.2, U10.12 (n_RESET)
unnamed: C37.1, R65.2, U10.60 (XO), Y1.3
unnamed: D12.1 (K), R75.1
unnamed: R63.1, U9.1 (CS)
unnamed: R66.1, U10.11 (VBUS_DET)
unnamed: R68.1, U10.41 (AUTOMDIX_EN)
unnamed: R69.1, U10.63 (USBRBIAS)
unnamed: R70.1, U10.50 (EXRES)
unnamed: TP114.1, U10.14 (PRTCTL2)
unnamed: TP115.1, U10.16 (PRTCTL3)

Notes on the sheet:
49.9R parts to be fitted close to LAN9513
RX and TX pairs to be routed as differential impedance 100R
USB2.0 to be routed as differential impedance 90R

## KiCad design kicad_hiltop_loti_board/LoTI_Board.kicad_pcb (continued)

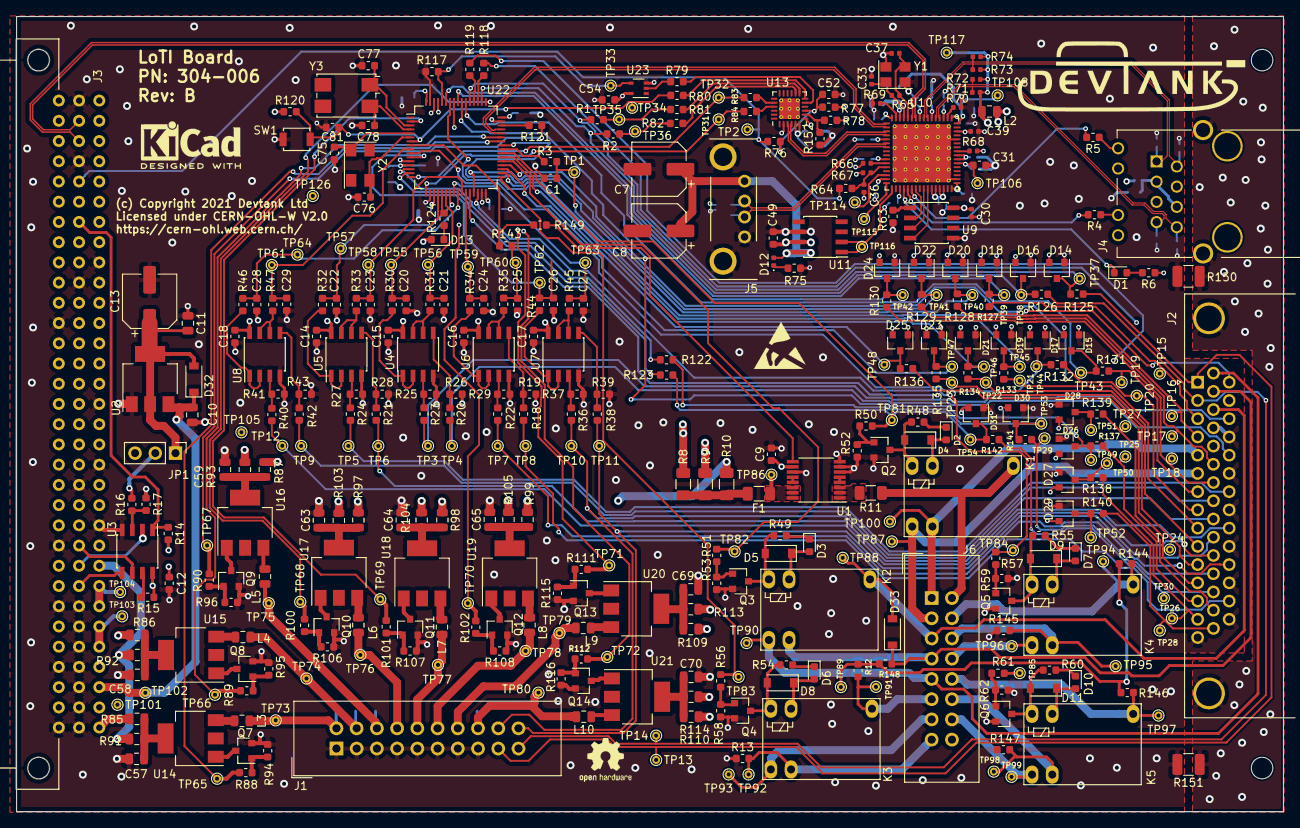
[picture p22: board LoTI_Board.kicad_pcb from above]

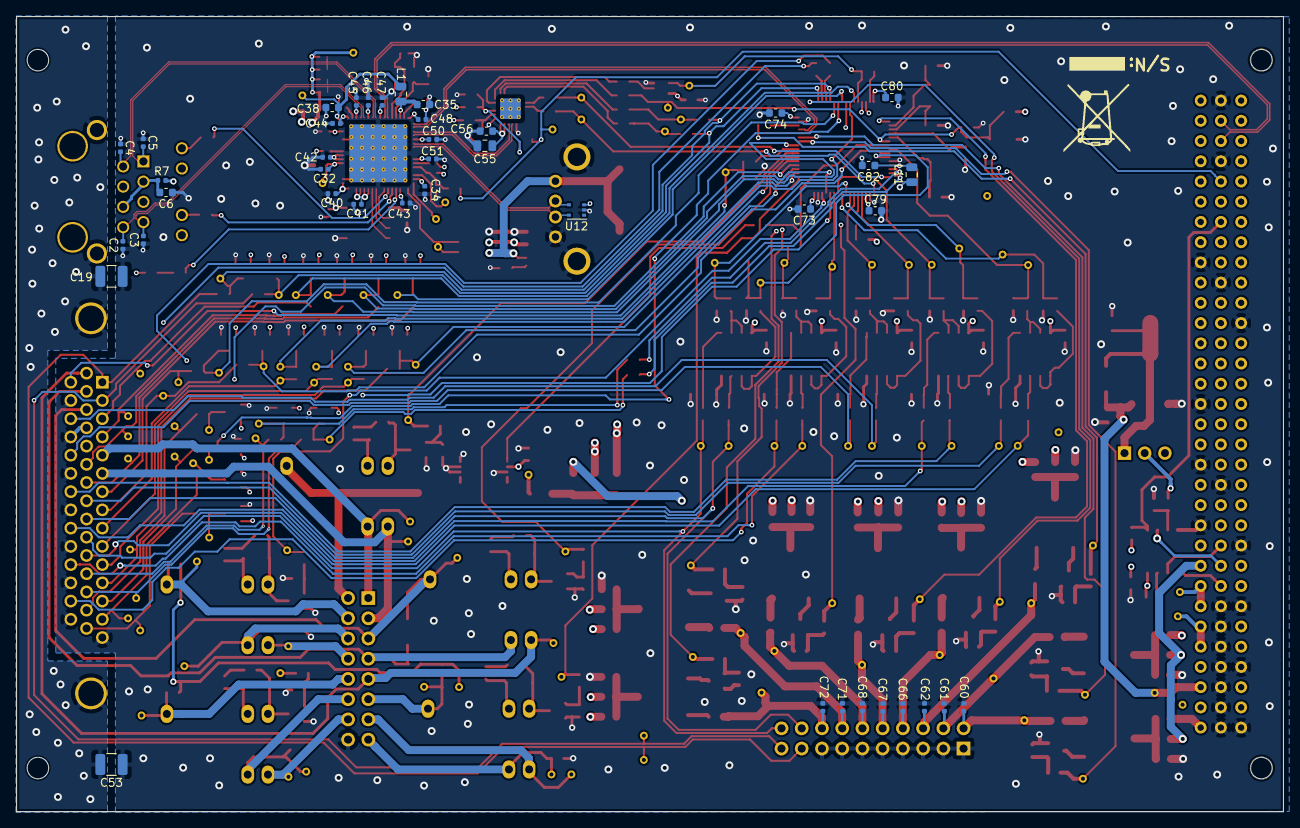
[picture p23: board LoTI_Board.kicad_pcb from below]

Board: 4 copper layers, 159.1 x 99.9 mm, 443 parts (41 on the bottom side), 251 nets.

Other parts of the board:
TP117: Test_Point; TestPoint_THTPad_D1.0mm_Drill0.5mm

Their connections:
+3V3_A: TP117.1; also elsewhere on the board

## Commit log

2019-06-06 setup new project git history for Loti board
    [DevtankProject.kicad_pcb, DevtankProject.sch]
2019-07-02 Project checkin.
    [DigitalIO.sch, HighSideOutputs.sch, InputConditioning.sch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]
2019-07-03 updated drawing templates
    [DigitalIO.sch, HighSideOutputs.sch, InputConditioning.sch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]
2020-09-14 Rev A
    [DigitalIO.sch, HighSideOutputs.sch, InputConditioning.sch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]
2021-04-09 Rev B updates
    [DigitalIO.sch, HighSideOutputs.sch, InputConditioning.sch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]

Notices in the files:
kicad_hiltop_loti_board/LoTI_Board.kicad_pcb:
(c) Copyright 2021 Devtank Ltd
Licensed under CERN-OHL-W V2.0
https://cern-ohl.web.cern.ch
